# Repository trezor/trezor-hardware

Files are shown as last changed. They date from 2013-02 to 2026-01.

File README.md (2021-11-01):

# Hardware design of Trezor



https://trezor.io/

## Open Source Hardware

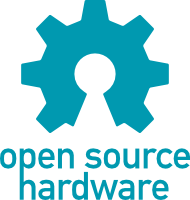
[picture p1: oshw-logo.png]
oshw (https://certification.oshwa.org/cz000005.html)


OSHWA UID: [CZ000005](https://certification.oshwa.org/cz000005.html)

The content of this repo is dual licensed under the following licenses:
* [GNU Affero General Public License v3](COPYING)
* [CERN Open Hardware Licence Version 2 - Strongly Reciprocal](LICENSE)

## Download

Download everything in a [single ZIP file](https://github.com/trezor/trezor-hardware/archive/master.zip).

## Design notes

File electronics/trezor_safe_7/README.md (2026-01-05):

# Trezor Safe 7 - Electronics Hardware
This folder contains both schematic designs and PCB renders of all the in-house developed PCBs present in the TS7 product. 

The TS7's electronics are split into three following PCBs
- Main board
- UI FPC
- ANT FPC

The display and battery also contain PCBs but these were not designed by Trezor's hardware team and therefore are not discloseable.

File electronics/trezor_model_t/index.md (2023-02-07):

# Trezor Model T Open Source Hardware Reference Documentation

## Photo

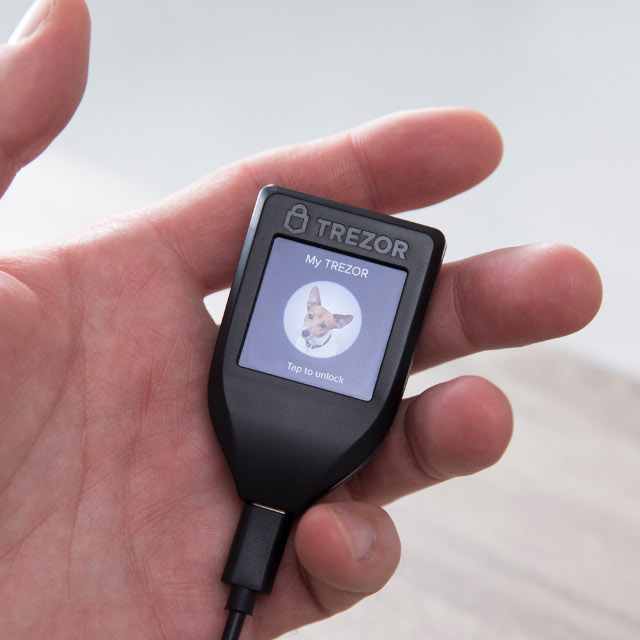
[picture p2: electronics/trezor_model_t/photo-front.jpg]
Photo Front


## Photo of assembled board (top)

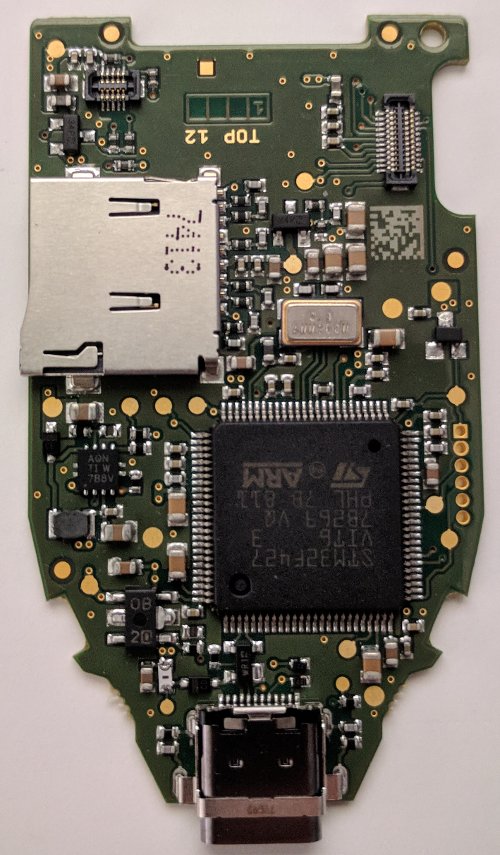
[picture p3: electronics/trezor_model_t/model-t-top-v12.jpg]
Assembled Board Top


## Photo of assembled board (bottom)

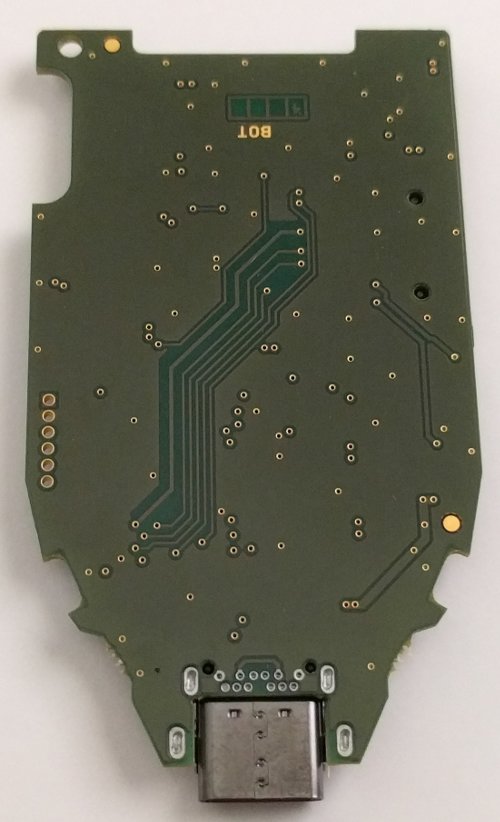
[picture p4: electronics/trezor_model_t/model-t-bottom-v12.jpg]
Assembled Board Bottom


## Photo of assembled TFT LCD display + capacitive touch panel module (top)

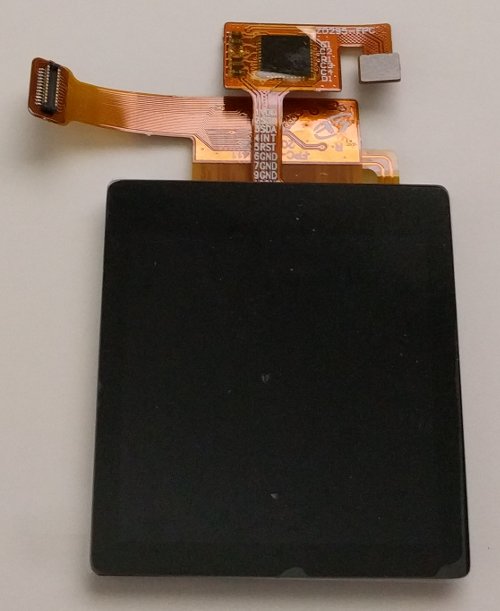
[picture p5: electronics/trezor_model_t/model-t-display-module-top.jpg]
Display Module Top


## Photo of assembled TFT LCD display + capacitive touch panel module (bottom)

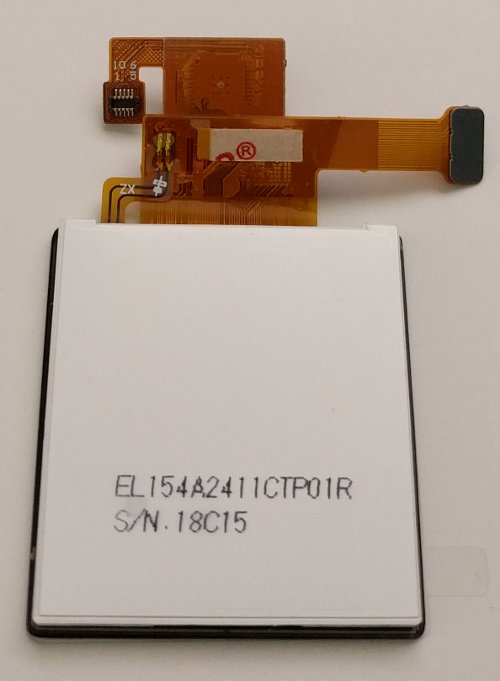
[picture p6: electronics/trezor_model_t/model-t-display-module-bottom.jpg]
Display Module Bottom


## Photo of disassembled TFT LCD display + capacitive touch panel module (top) (CTPM on left) (TFT LCD broken glass removed)

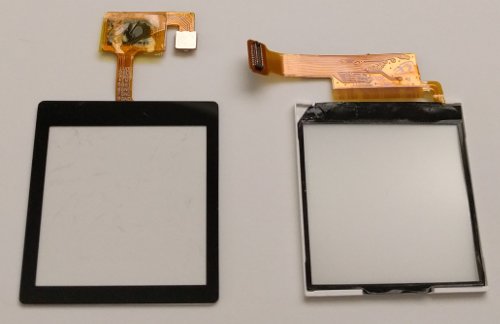
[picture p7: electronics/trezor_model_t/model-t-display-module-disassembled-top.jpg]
Display Module Disassembled Top


## Photo of disassembled TFT LCD display + capacitive touch panel module (bottom) (CTPM on left) (TFT LCD broken glass removed)

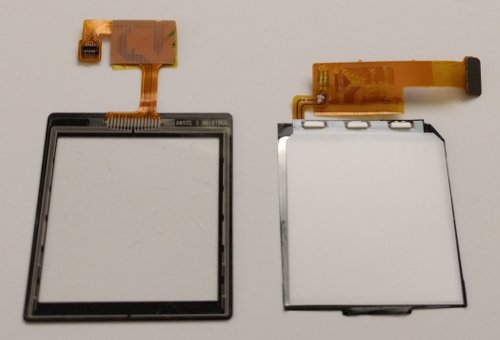
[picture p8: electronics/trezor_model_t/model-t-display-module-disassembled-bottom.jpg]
Display Module Disassembled Bottom


## Bill of Materials / BOM

[BOM](bom.txt)

## Schematic

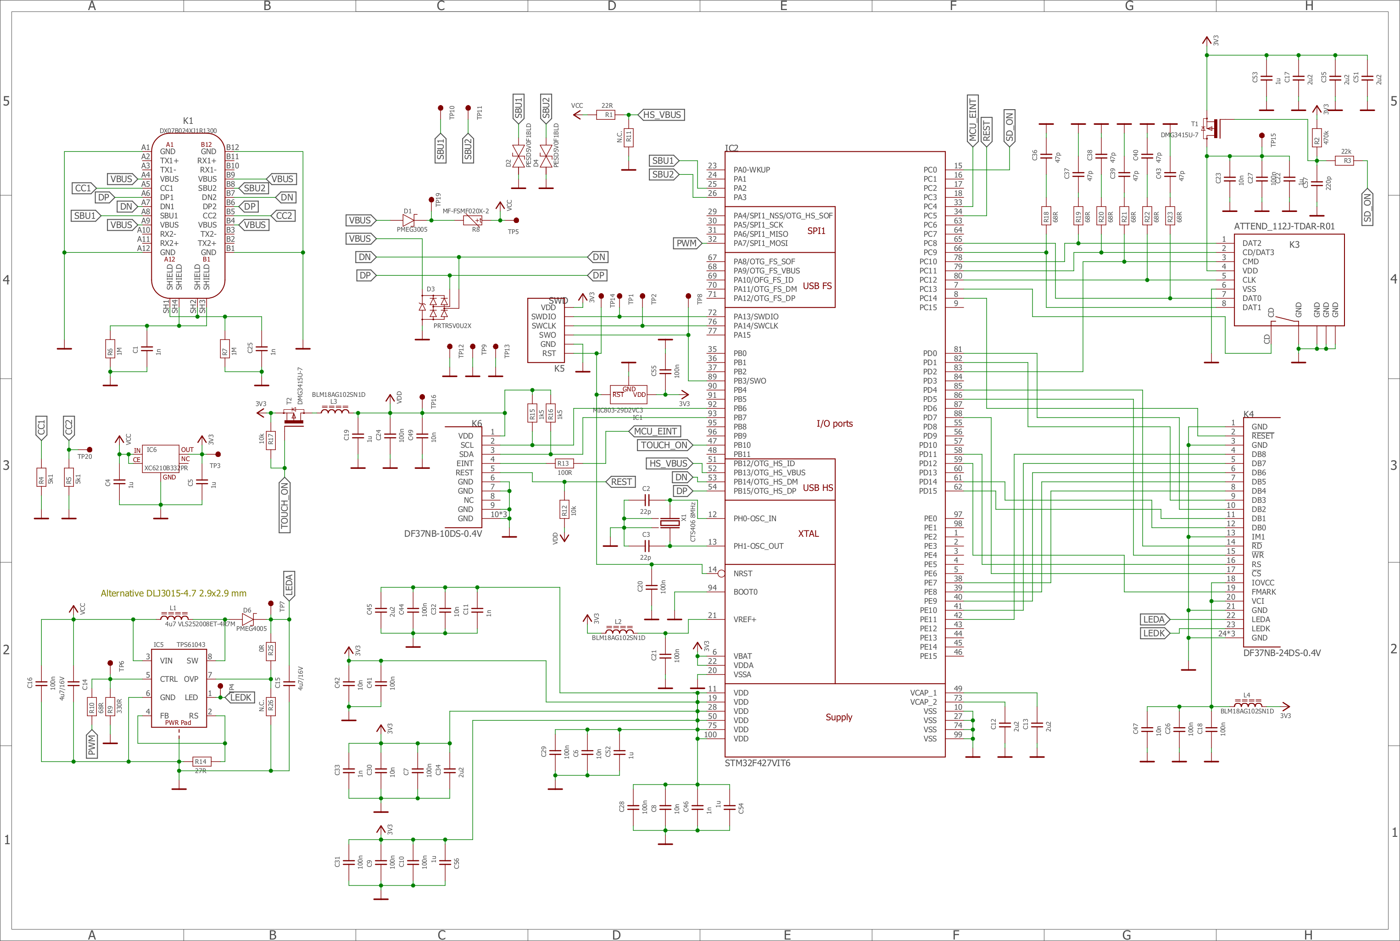
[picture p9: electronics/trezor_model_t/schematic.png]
Schematic


## Developer Kit

* 1 x [STM32F429I-DISC1](https://www.st.com/en/evaluation-tools/32f429idiscovery.html) (note: [Manual with pin to dev board function mapping](https://www.st.com/content/ccc/resource/technical/document/user_manual/6b/25/05/23/a9/45/4d/6a/DM00093903.pdf/files/DM00093903.pdf/jcr:content/translations/en.DM0009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))
* 1 x USB Cable Type A Plug/Male to Type Mini-B Plug/Male
* 1 x USB Cable Type A Plug/Male to Type Micro-B Plug/Male
* 1 x [ER-TFTM028-4 Display + Capacitive Touch Panel Module](https://www.ebay.com/itm/302049581340) (Note: specify 40-Pin Header, 8080 8-bit Parallel, VDD=3.3V, Capacitive Touch Panel) (note: [Manual](https://www.buydisplay.com/download/manual/ER-TFTM028-4_Datasheet.pdf))
* 1 x [microSD Board](https://www.waveshare.com/micro-sd-storage-board.htm)
* 1 x [Pack of 40 Female to female jumper wires with 0.1" header contacts](https://www.adafruit.com/product/266)

### Display

* Resolution: 240px x 240px -OR- 240px x 320px
* Driver IC: ST7789V, GC9307, or ILI9341V (on-chip display data RAM of 240x320x18 bits)
* 18-bit (262,144) RGB color graphic type TFT-LCD
* Bus/Interface: 8080-I 8-bit parallel with 16-bit/pixel (RGB 5-6-5)

#### Pinout

|Description|MCU Pin|Notes|
|---|---|-----|
|LCD_RST|PC14|display module pin 21. benign conflict with unpopulated OSC32_IN on dev board.|
|LCD_FMARK|PD12|tearing effect input; display module pin 22|
|LCD_PWM|PA7|backlight control (brightness); display module pin 29. benign conflict with I2C_EXT_RST on dev board.|
|LCD_CS|PD7|display module pin 23|
|LCD_RS|PD11|register select aka command/data; display module pin 24|
|LCD_RD|PD4|display module pin 26|
|LCD_WR|PD5|display module pin 25|
|LCD_D0|PD14|display module pin 3|
|LCD_D1|PD15|display module pin 4|
|LCD_D2|PD0|display module pin 5|
|LCD_D3|PD1|display module pin 6|
|LCD_D4|PE7|display module pin 7|
|LCD_D5|PE8|display module pin 8|
|LCD_D6|PE9|display module pin 9|
|LCD_D7|PE10|display module pin 10|
|LCD_D8|PE11|not currently used|

### Capacitive Touch Panel / Sensor

* Bus/Interface: I2C
* Driver IC: FT6236 or FT6206
* single touch

#### Pinout

|Description|MCU Pin|Notes|
|---|---|-----|
|TOUCH_ON|PB10|no mapped pin on display module|
|I2C1_SCL|PB6|display module pin 30|
|I2C1_SDA|PB7|display module pin 31|
|EINT|PC4|not currently used. display module pin 39. conflict with USB OTG FS PSO on dev board.|
|REST|PC5|benign conflict with USB OTG FS OC on dev board. no mapped pin on display module.|

### microSD Socket

* Bus/Interface: 4-bit

#### Pinout

|Description|MCU Pin|
|---|---|
|SDIO_D0|PC8|
|SDIO_D1|PC9|
|SDIO_D2|PC10|
|SDIO_D3|PC11|
|SDIO_CK|PC12|
|SDIO_CMD|PD2|
|SD_CARDDETECT|PC13|
|SD_ON|PC0|

### USB Socket

* USB HS (high-speed) peripheral in FS (full-speed) mode

#### Pinout

|Description|MCU Pin|Notes|
|---|---|-----|
|OTG_HS_VBUS|PB13||
|OTG_HS_ID|PB12||
|OTG_HS_DM|PB14||
|OTG_HS_DP|PB15||
|SBU1|PA2|not currently used. conflict with L3GD20 Gyroscope MEMS on dev board.|
|SBU2|PA3|not currently used|

### Dev Board

* [STM32F429ZIT6](https://www.st.com/en/microcontrollers-microprocessors/stm32f429zi.html)
* HSE / High-Speed External Crystal: 8 MHz
* Integrated STMicroelectronics ST-LINK/V2.1 debugger

Note: There are many conflicts between how the software maps GPIO pins and how the dev board maps them to its functions.
Many of the conflicts are resolved by removing the external SDRAM chip and the TFT LCD display + resistive touch panel that come attached to the dev board.
The unresolved conflicts are noted in the pinout descriptions above.
Currently, testing has shown that it is not necessary to remove either the SDRAM or the TFT LCD display + resistive touch panel.
If you choose to remove them, our experience is that the easiest way to remove the SDRAM chip is by first cutting the leads on one side of the chip (e.g.- with an X-Acto knife) and then lifting the chip and rocking it until the leads on the other side break. Be sure that no broken leads short to another pin as this can cause the dev board and/or display to malfunction. If some do, just clean them up so that they are separate again.
This method reduces the amount of knife work, and the chance for slicing other things on the board (or yourself).
To remove the TFT LCD display + resistive touch panel module, lift the module away from the metal tray, bend the metal tray out of the way, then cleanly pull/tear the flex PCB away from the solder connections to the main board (the connections usually break without much force).
The metal tray is attached to the board with double stick tape. You just have to pull that up.

## Photo of dev board before modifications (top)

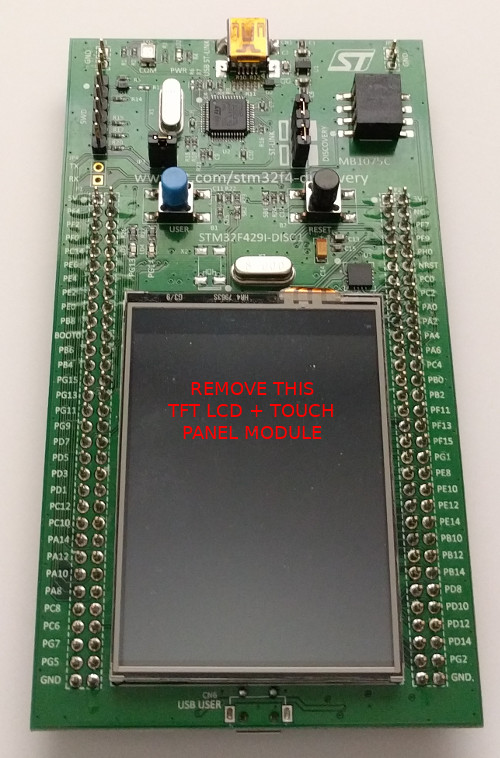
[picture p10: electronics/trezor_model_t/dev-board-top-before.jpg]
Dev Board Top Before


## Photo of dev board before modifications (bottom)

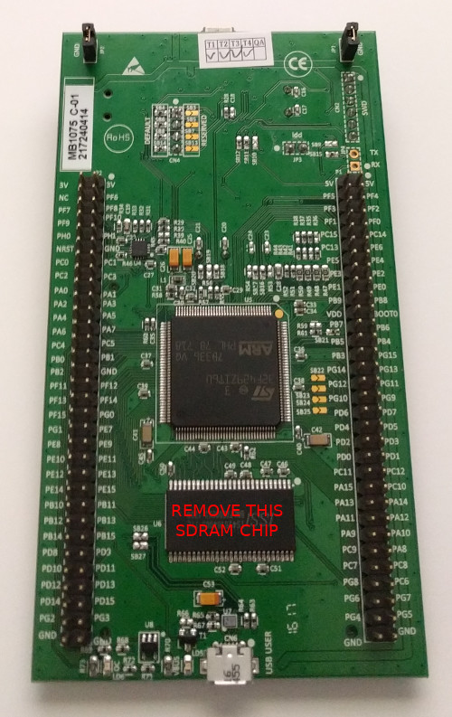
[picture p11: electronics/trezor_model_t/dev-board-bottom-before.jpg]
Dev Board Bottom Before


Minimum MCU requirements:

* STM32F4 family [STM32F427VIT6](https://www.st.com/en/microcontrollers-microprocessors/stm32f427vi.html)
* 168 MHz, 8 MHz HSE
* 2048 KB Flash memory
* 192 KB SRAM
* 64 KB CCMRAM
* FMC controller
* TRNG

### Clock Tree

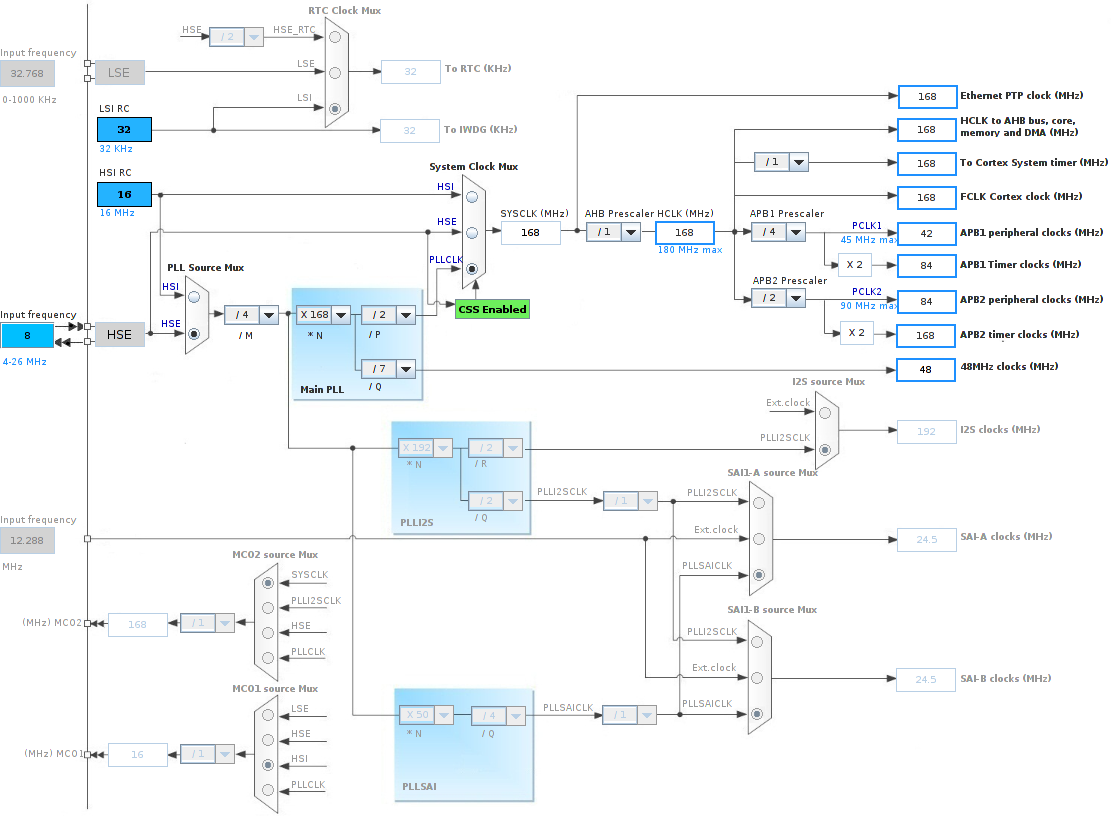
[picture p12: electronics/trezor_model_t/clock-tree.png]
Clock Tree


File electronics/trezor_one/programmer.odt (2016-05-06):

| 1 RST 2 GND 3 SWO 4 SWCLK 5 SWDIO 6 VDD

distance: 0.0625 inch

drill: 0.7 mm

programmer: ST-Link/V2

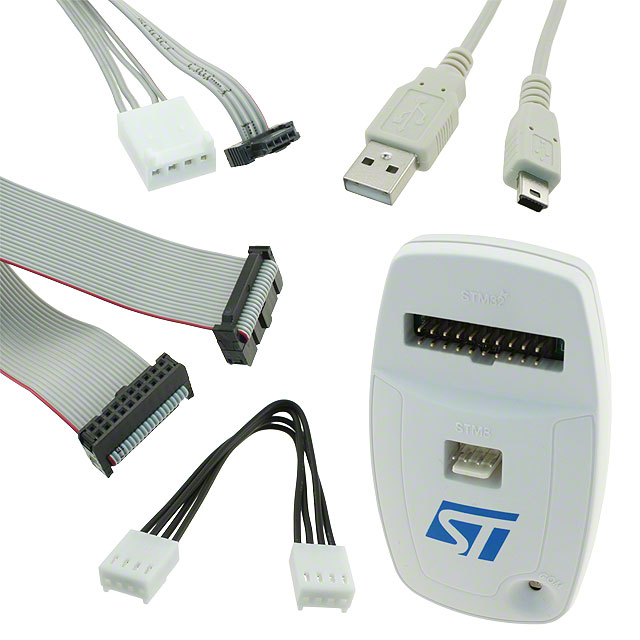
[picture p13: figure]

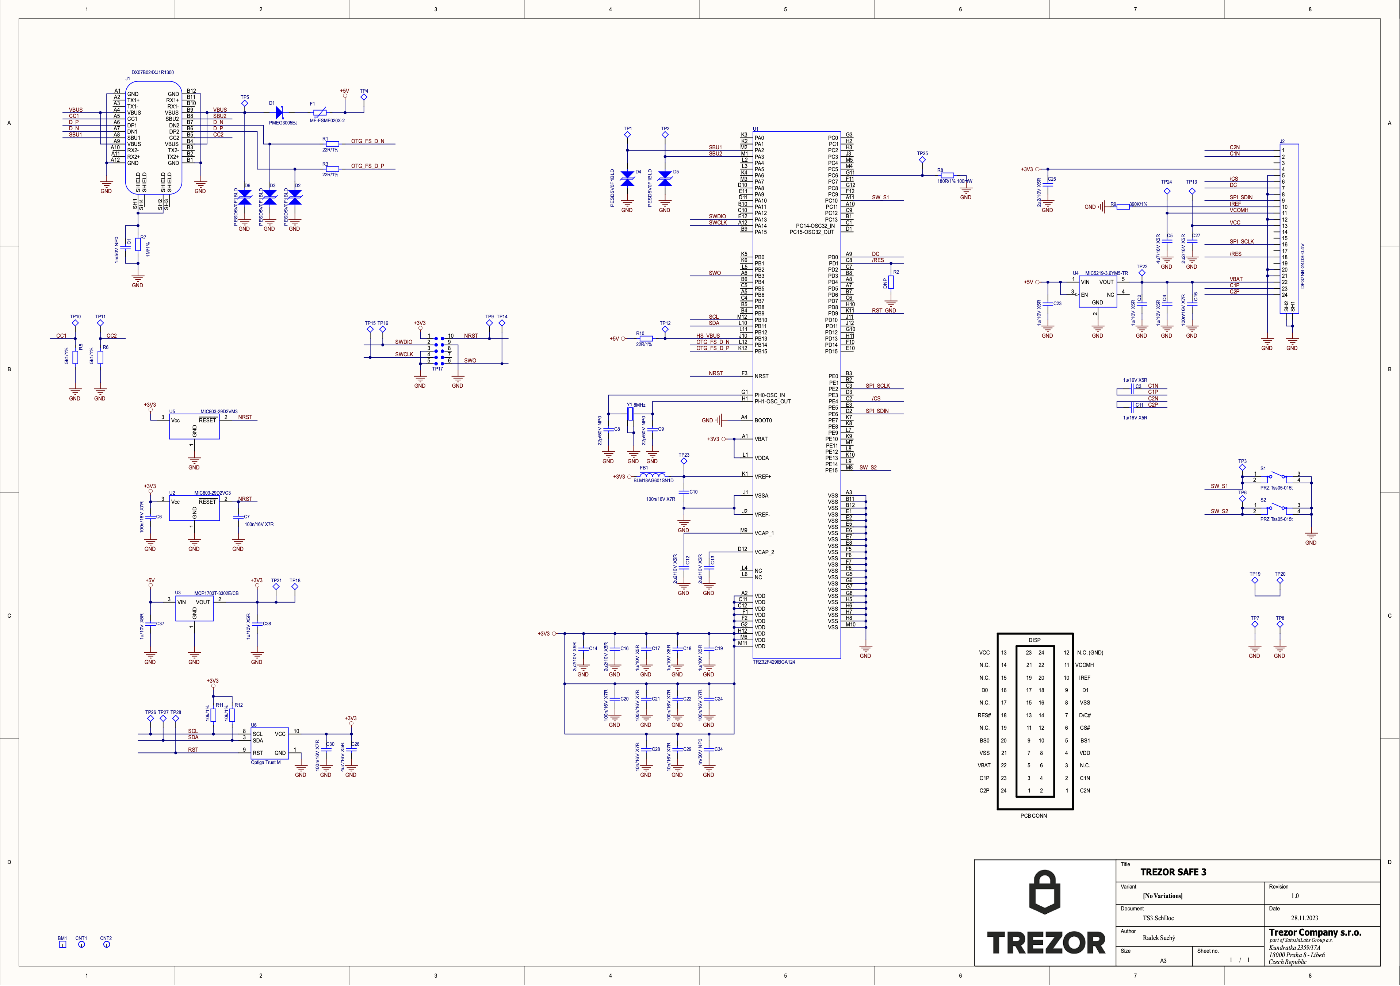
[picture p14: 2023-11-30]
electronics/trezor_safe_3/schematics.png

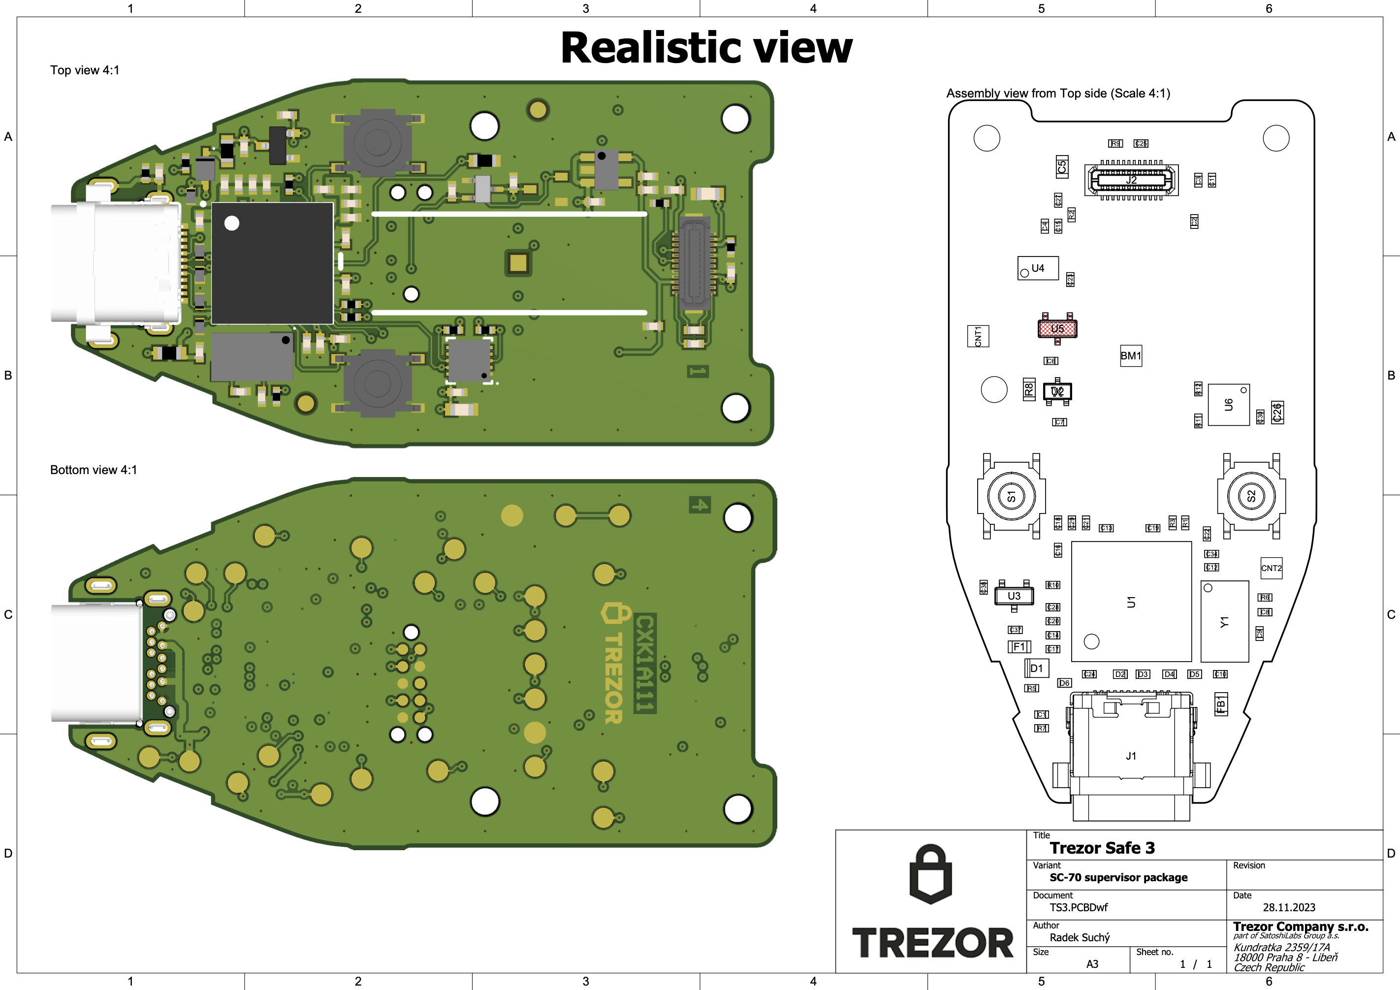
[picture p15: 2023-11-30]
electronics/trezor_safe_3/pcb_view.png

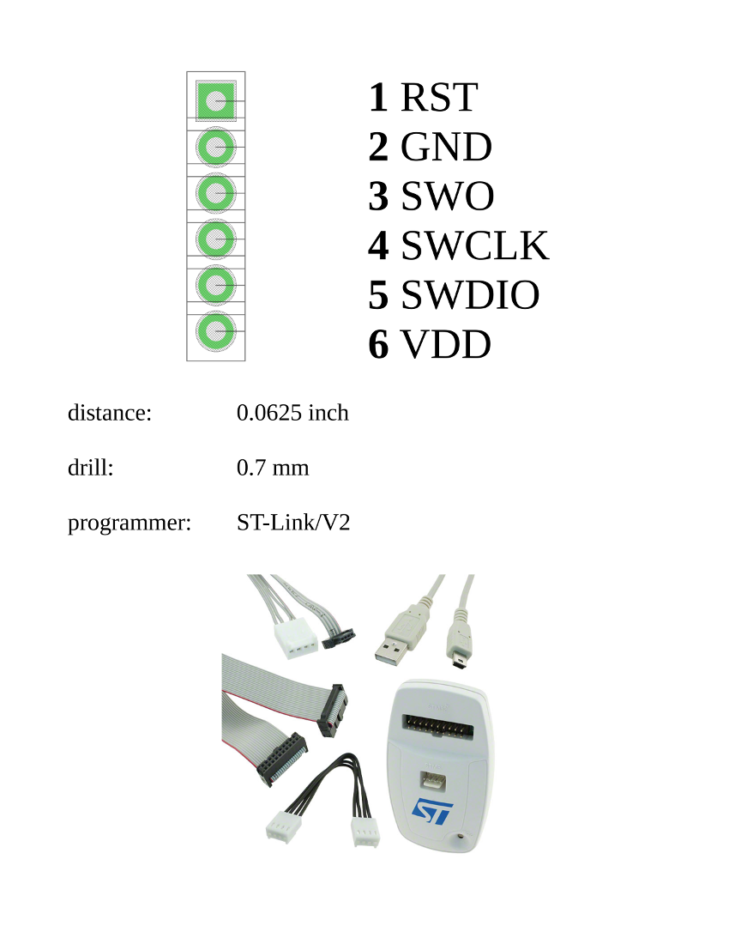
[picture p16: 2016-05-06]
electronics/trezor_one/programmer.png

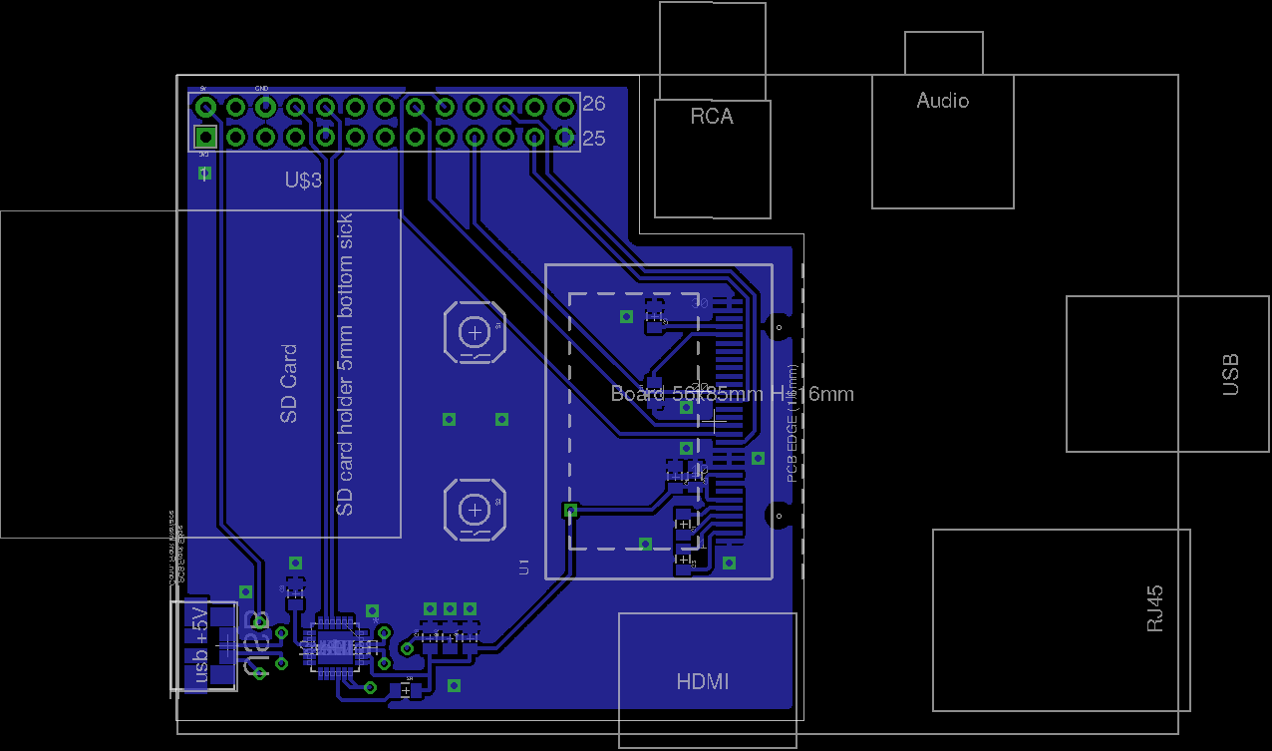
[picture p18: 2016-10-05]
electronics/trezor_one/raspi.brd.png

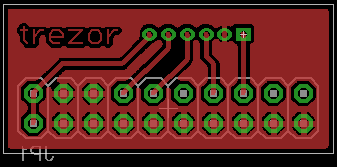
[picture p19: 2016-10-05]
electronics/trezor_one/programmer.brd.png

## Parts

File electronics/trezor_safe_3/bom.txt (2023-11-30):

Quantity    Designator                                  Comment                Footprint
2           C1, C34                                     1n/50V NP0             C_0402_B
8           C2, C4, C17, C18, C19, C23, C37, C38        1u/10V X5R             C_0402_B
2           C3, C11                                     1u/16V X5R             C_0402_B
2           C5, C26                                     4u7/16V X5R            C_0603_B
9           C6, C7, C10, C15, C20, C21, C22, C24, C30   100n/16V X7R           C_0402_B
2           C8, C9                                      22p/50V NP0            C_0402_B
5           C12, C13, C14, C16, C25                     2u2/10V X5R            C_0402_B
1           C27                                         2u2/16V X5R            C_0402_B
2           C28, C29                                    10n/16V X7R            C_0402_B
1           D1                                          PMEG3005EJ             SOD-323_B
5           D2, D3, D4, D5, D6                          PESD5V0F1BLD           SOD-882D_B
1           F1                                          MF-FSMF020X-2          R_0603_B
1           FB1                                         BLM18AG601SN1D         L_0603_B
1           J1                                          DX07B024XJ1R1300       USB-C_3.1_JAE_DX07B024XJ1
1           J2                                          DF37NB-24DS-0.4V       DF37NB-24DS-0.4V
3           R1, R3, R10                                 22R/1%                 R_0402_B
1           R2                                          DNP                    R_0402_B
2           R5, R6                                      5k1/1%                 R_0402_B
1           R7                                          1M/1%                  R_0402_B
1           R8                                          180R/1% 100mW          R_0603_B
1           R9                                          390K/1%                R_0402_B
2           R11, R12                                    10k/1%                 R_0402_B
2           S1, S2                                      PRZ Tss05-015t         Tact_Switch_5.2x5.2x1.5_B
1           U1                                          TRZ32F429IBGA124       BGA-124_9X9
1           U2                                          MIC803-29D2VC3         SC-70-3_B
1           U3                                          MCP1703T-3302E/CB      SOT-23-3_B
1           U4                                          MIC5219-3.6YM5-TR      SOT-23-5_B
1           U6                                          Optiga Trust M         PG-USON-10-2_B
1           Y1                                          8MHz                   X-4_6.0x3.5_B

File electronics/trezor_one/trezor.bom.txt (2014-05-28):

Trezor
======

- 5x SMD 0603 Capacitor 1uF - C1, C2, C4, C10, C11
- 7x SMD 0603 Capacitor 0.1uF - C3, C12, C13, C14, C15, C16, C18
- 3x SMD 0603 Capacitor 2.2uF - C6, C7, C17
- 1x SMD 0603 Capacitor 4.7uF - C5
- 2x SMD 0603 Capacitor 22pF - C8, C9

- 1x SMD 0603 Resistor 390k - R1

- 2x Microbuton P-B17310
  * http://www.gme.cz/mikrospinace-do-dps/p-b17310-p630-143/

- 1x Micro USB (type B) Receptacle Bottom
  * http://cz.farnell.com/molex/47346-0001/micro-usb-type-b-receptacle-bottom/dp/1568026

- 1x OLED display 128x64 UG-2864HSWEG01
  * http://www.wide.hk/products.php?product=128X64-OLED-LED-Display-Module-SSD1306-%28White-Color%29

- 1x STM32F205RE
  * http://www.st.com/web/catalog/mmc/FM141/SC1169/SS1575/LN1433/PF245096
  * http://cz.farnell.com/stmicroelectronics/stm32f205ret6/ic-mcu-32bit-arm-64-lqfp/dp/2060897

- 1x MCP1703 Low Dropout Voltage Regulator
  * http://www.microchip.com/wwwproducts/Devices.aspx?dDocName=en530838
  * http://cz.farnell.com/microchip/mcp1703t-3302e-cb/v-reg-ldo-250ma-3-3v-sot-23a-3/dp/1439518

- 1x ABMM2 8 MHz Crystal
  * http://cz.farnell.com/abracon/abmm2-8-000mhz-e2-t/crystal-8m-18pf-cl-6x3-6mm-smt/dp/1611803

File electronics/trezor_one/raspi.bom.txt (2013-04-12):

Raspberry Pi shield
===================

- 5x SMD 0805 Capacitor 1uF - C1, C2, C4, C6, C7
- 2x SMD 0805 Capacitor 0.1uF - C3, C8
- 1x SMD 0805 Capacitor 2.2uF - C5
- 1x SMD 0805 Capacitor 4.7uF - C9

- 1x SMD 0805 Resistor 390k - R1
- 1x SMD 0805 Resistor 4k7 - R2

- 2x Microbuton P-B17310
  * http://www.gme.cz/mikrospinace-do-dps/p-b17310-p630-143/

- 1x Micro USB (type B) Receptacle Bottom
  * http://cz.farnell.com/molex/47346-0001/micro-usb-type-b-receptacle-bottom/dp/1568026

- 1x OLED display 128x64 UG-2864HSWEG01
  * http://www.wide.hk/products.php?product=128X64-OLED-LED-Display-Module-SSD1306-%28White-Color%29

- 1x SiLabs CP2110 HID-232 converter
  * http://www.silabs.com/products/interface/usbtouart/Pages/usb-to-uart-bridge.aspx

- 1x 2x13 Pinheader
  * http://www.gme.cz/dutinkove-listy/dutinkova-lista-bl826gd-p832-240/

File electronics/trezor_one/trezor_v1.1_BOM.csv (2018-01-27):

Qty | Value | Device | Package | Parts | Description
7 | 100n | C_0402 | 402 | C7, C9, C12, C13, C14, C15, C16
1 | 12k | R_0402 | 402 | R7
1 | 1M | R_0603 | 603 | R9
1 | 1k5 | R_0402 | 402 | R6
1 | 1n/200V | C_0603 | 603 | C19
5 | 1u | C_0402 | 402 | C1, C2, C3, C4, C18
2 | 22R | R_0402 | 402 | R3, R4
1 | 22k | R_0402 | 402 | R8
2 | 22p | C_0402 | 402 | C20, C21
2 | 2u2 | C_0402 | 402 | C6, C8
1 | 2u2 | C_0603 | 603 | C5
1 | 390k | R_0402 | 402 | R10
1 | 4u7 | C_0603 | 603 | C10
1 | 8MHz | CRYSTALCTS406 | CTS406 | Q2 | CRYSTAL
1 | BAT60BWS | DS_SOD323 | SOD323 | D2
1 | DISPLAY | DISP_OLED_UG-2864HSWEG010.96";UG-2864HSWEG01_0.96IN_WRAPAROUND" | U3 | UG-2864HSWEG01 OLED display
1 | MCP1703T-3302E/CB | MCP1703CB | SOT23 | IC1 | 250 mA, 16V, Low Quiescent Current LDO Regulator
1 | MF-FSMF020X-2 | POLYSWITCH_0603 | 603 | R2
1 | PRTR5V0U2X | PRTR5V0_SOT143B | SOT143B | D1
1 | STM32F205RET6 | STM32F10XRXT6 | TQFP64 | U1 | STM32F101/103 64pin LQFP
1 | SWD | SWD | SWD | K2 | SWD
2 | SWITCH-MOMENTARY-2SMD | SWITCH-MOMENTARY-2SMD | TACTILE_SWITCH_SMD | S1, S2 | Various NO switches- pushbuttons, reed, etc
1 | USB5_USB_MICRO_MOLEX475890001 | USB5_USB_MICRO_MOLEX475890001 | USB_MICRO-MOLEX475890001 | K1

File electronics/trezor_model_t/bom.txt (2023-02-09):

Part Value                Device                                  Package
C1   1n/50V               C_0402                                  0402
C2   22p                  C_0402                                  0402
C3   22p                  C_0402                                  0402
C4   1u                   C_0603                                  0603
C5   1u                   C_0603                                  0603
C6   10n                  C_0402                                  0402
C7   100n                 C_0402                                  0402
C8   10n                  C_0402                                  0402
C9   100n                 C_0402                                  0402
C10  100n                 C_0402                                  0402
C11  1n                   C_0402                                  0402
C12  2u2                  C_0805                                  0805
C13  2u2                  C_0805                                  0805
C14  4u7/16V              C_0805                                  0805
C15  4u7/16V              C_0805                                  0805
C16  100n                 C_0402                                  0402
C17  2u2                  C_0805                                  0805
C18  100n                 C_0402                                  0402
C19  1u                   C_0603                                  0603
C20  100n                 C_0402                                  0402
C21  100n                 C_0402                                  0402
C22  1u                   C_0603                                  0603
C23  10n                  C_0402                                  0402
C24  100n                 C_0402                                  0402
C25  1n/50V               C_0402                                  0402
C26  100n                 C_0402                                  0402
C27  100n                 C_0402                                  0402
C28  100n                 C_0402                                  0402
C29  100n                 C_0402                                  0402
C30  10n                  C_0402                                  0402
C31  100n                 C_0402                                  0402
C32  10n                  C_0402                                  0402
C33  1n                   C_0402                                  0402
C34  2u2                  C_0805                                  0805
C35  2u2                  C_0805                                  0805
C36  47p                  C_0402                                  0402
C37  47p                  C_0402                                  0402
C38  47p                  C_0402                                  0402
C39  47p                  C_0402                                  0402
C40  47p                  C_0402                                  0402
C41  100n                 C_0402                                  0402
C42  10n                  C_0402                                  0402
C43  47p                  C_0402                                  0402
C44  100n                 C_0402                                  0402
C45  2u2                  C_0805                                  0805
C46  1n                   C_0402                                  0402
C47  10n                  C_0402                                  0402
C48  100n                 C_0402                                  0402
C49  10n                  C_0402                                  0402
C50  220p                 C_0402                                  0402
C51  2u2                  C_0805                                  0805
C52  1u                   C_0603                                  0603
C53  1u                   C_0603                                  0603
C54  1u                   C_0603                                  0603
C55  100n                 C_0402                                  0402
C56  1u                   C_0603                                  0603
C57  220p                 C_0402                                  0402
C58  1n                   C_0402                                  0402
D1   PMEG3005EJ           DS_SOD323F                              SOD323F
D2   PESD5V0F1BLD         D_TRANSIL_BI_SOD882D                    SOD882D
D3   PRTR5V0U2X           PRTR5V0_SOT143B                         SOT143B
D4   PESD5V0F1BLD         D_TRANSIL_BI_SOD882D                    SOD882D
D6   PMEG4005EJ           DS_SOD323F                              SOD323F
IC1  MIC803-30D2VC3                                               SC70-3
IC2  STM32F427VIT6        STM32F427_LQFP100                       LQFP100_NO_CENTER_NO_TDOCU
IC5  TPS61043             TP6104X_WSON-8_3X3MM                    WSON-8_3X3MM
IC6  XC6210B332PR         XC6210B_SOT89-5                         SOT89-5
K1   DX07B024XJ1R1300     USB-C_JAE_DX07B024XJ1                   USB_C_JAE_DX07B024XJ1
K3   ATTEND_112J-TDAR-R01 KON_µSD_CARD_ATTEND_112J_TXAR_R01_SMALL ATTEND_112J-TXAR-R01_SMALL
K4   DF37NB-24DS-0.4V     DISPLEJ_154A2411CTP01                   DF37NB-24DS-0.4V
K5   SWD                  SWD                                     SWD
K6   DF37NB-10DS-0.4V     DISPLEJ_154A2411CTP01_TOUCH             DF37NB-10DS-0.4V
L1   4u7 VLS252008ET-4R7M L_2.5X2.0                               L_2.5X2.0
L2   BLM18AG601SN1D       L_0603                                  0603
L3   BLM18AG601SN1D       L_0603                                  0603
L4   BLM18AG601SN1D       L_0603                                  0603
LCD1                      LCD_DISPLEJ                             LCD
R1   22R                  R_0402                                  0402
R2   470k                 R_0402                                  0402
R3   22k                  R_0402                                  0402
R4   5k1                  R_0402                                  0402
R5   5k1                  R_0402                                  0402
R6   1M                   R_0402                                  0402
R7   1M                   R_0402                                  0402
R8   MF-FSMF020X-2        POLYSWITCH_0603                         0603
R9   330R                 R_0402                                  0402
R10  68R                  R_0402                                  0402
R11  N.C.                 R_0402                                  0402
R12  10k                  R_0402                                  0402
R13  100R                 R_0402                                  0402
R14  27R                  R_0402                                  0402
R15  1k5                  R_0402                                  0402
R16  1k5                  R_0402                                  0402
R17  470k                 R_0402                                  0402
R18  68R                  R_0402                                  0402
R19  68R                  R_0402                                  0402
R20  68R                  R_0402                                  0402
R21  68R                  R_0402                                  0402
R22  68R                  R_0402                                  0402
R23  68R                  R_0402                                  0402
R24  22k                  R_0402                                  0402
R25  0R                   R_0402                                  0402
R26  N.C.                 R_0402                                  0402
T1   DMP2045U                                                     SOT-23
T2   DMP2045U                                                     SOT-23
X1   CTS406 8MHz          X_4V_6,0X3,5                            X6,0X3,5

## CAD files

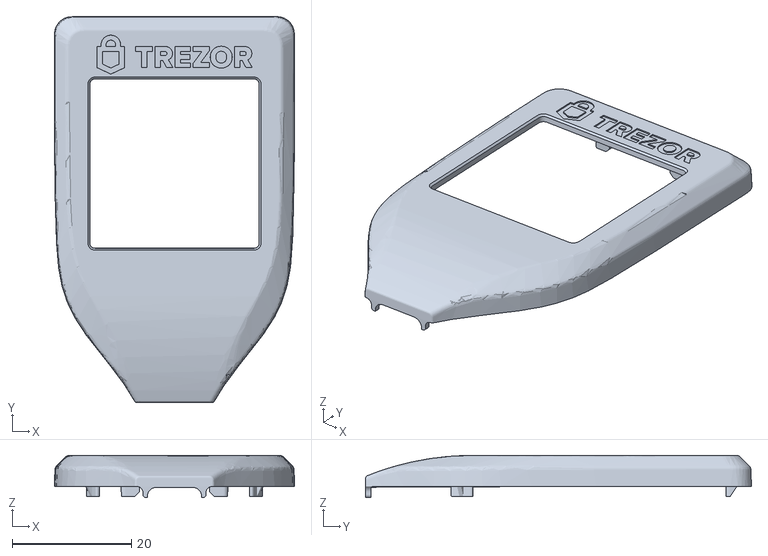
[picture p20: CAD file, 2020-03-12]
case/trezor_model_t/v1/top.stl
40.2 x 64.6 x 7.05

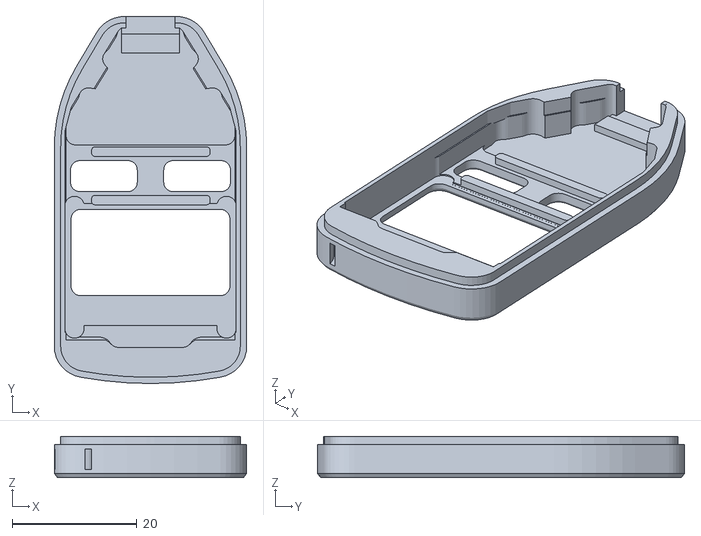
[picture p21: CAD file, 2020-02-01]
case/trezor_one/v3/cover-up.stl
30.9 x 58.9 x 6.61

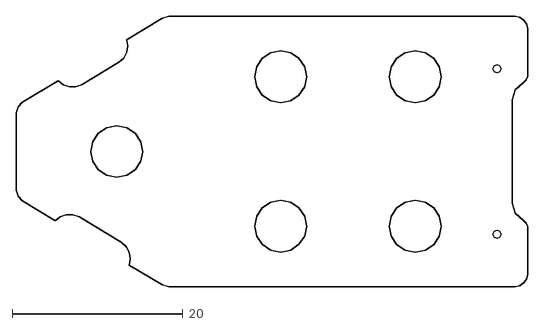
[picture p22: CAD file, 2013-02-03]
stl/plosak-nobezier.dxf
59.9 x 31.6

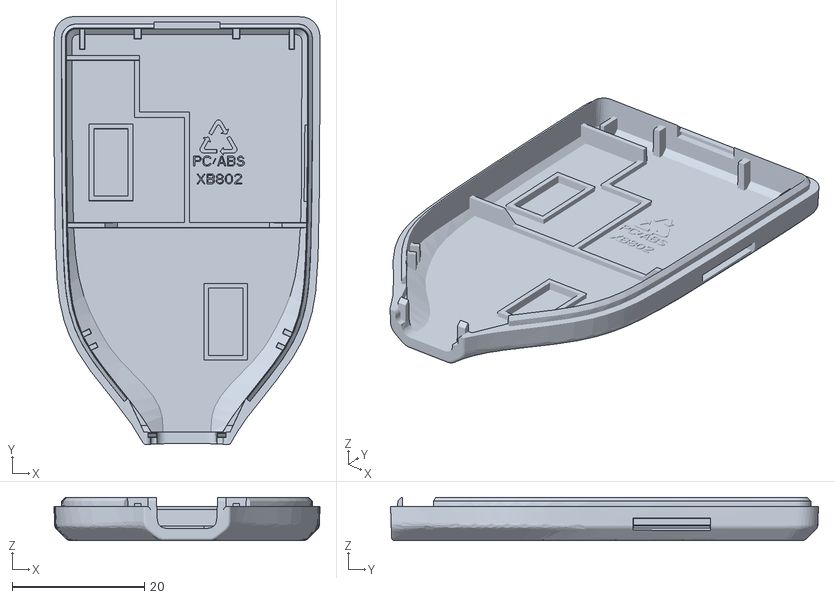
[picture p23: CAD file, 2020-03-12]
case/trezor_model_t/v1/bottom.stl
40.2 x 64.7 x 6.55

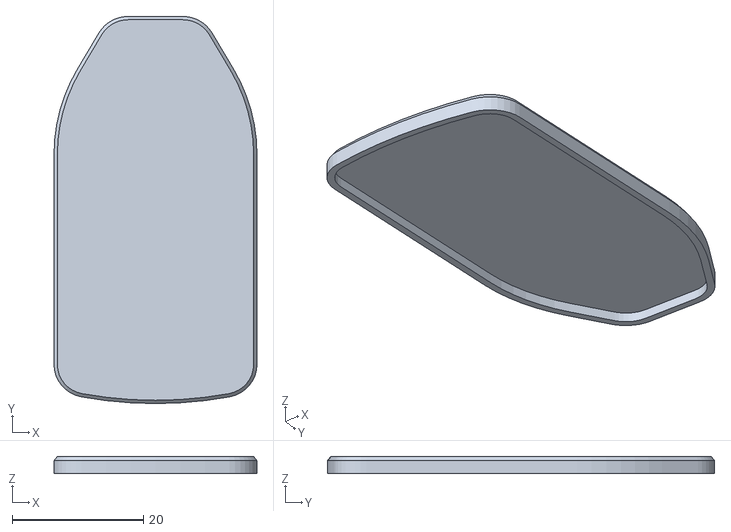
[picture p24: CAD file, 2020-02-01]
case/trezor_one/v3/cover-down.stl
30.9 x 58.9 x 2.64

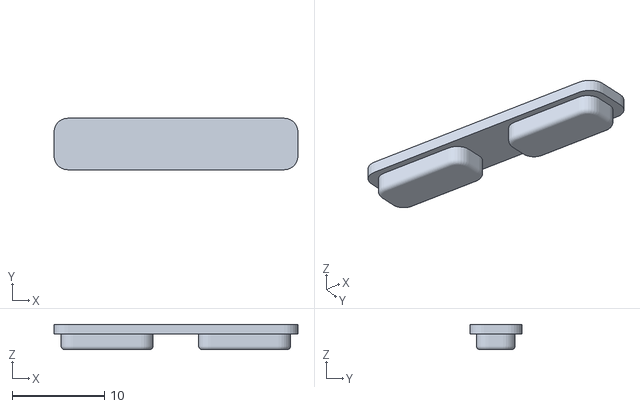
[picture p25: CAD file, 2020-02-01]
case/trezor_one/v3/buttons.stl
26.5 x 5.60 x 2.76

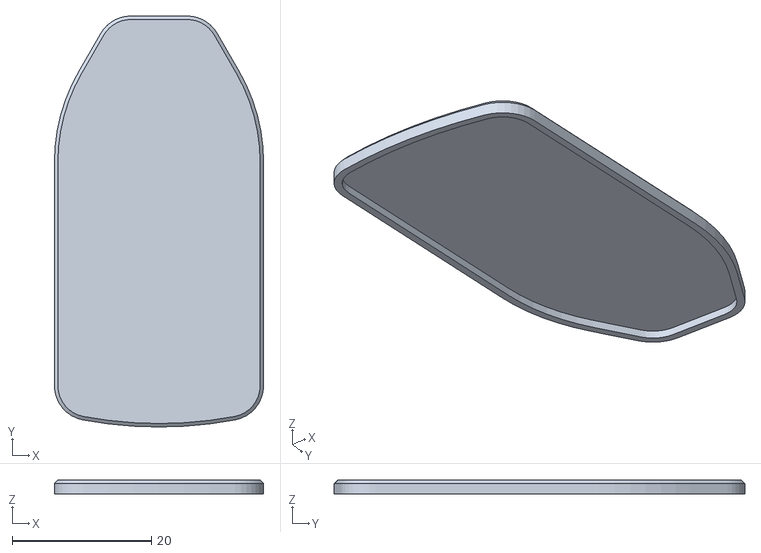
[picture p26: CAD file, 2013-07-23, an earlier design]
case/trezor_one/v1/cover-down.stl
30.0 x 58.9 x 2.00

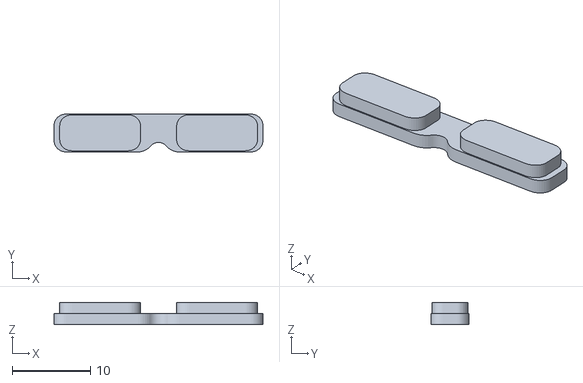
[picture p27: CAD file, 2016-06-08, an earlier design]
case/trezor_one/v2/buttons.stl
26.8 x 4.85 x 2.82

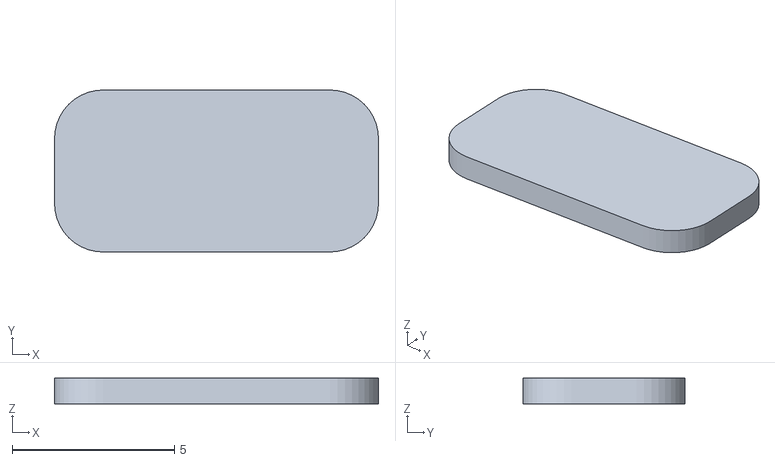
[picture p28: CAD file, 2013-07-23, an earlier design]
case/trezor_one/v1/button-up-2.stl
10.0 x 5.00 x 0.8

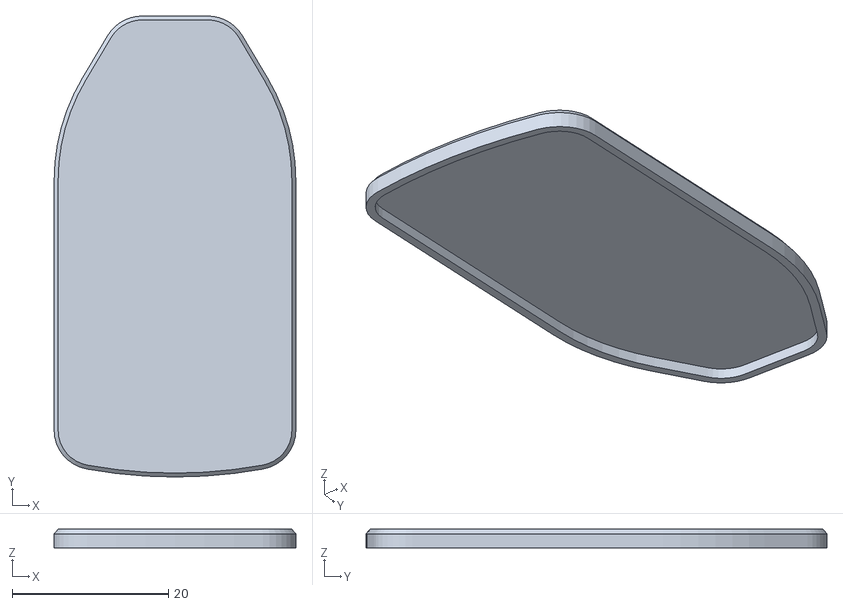
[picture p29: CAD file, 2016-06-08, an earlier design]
case/trezor_one/v2/cover-down-3.stl
30.9 x 58.9 x 2.40

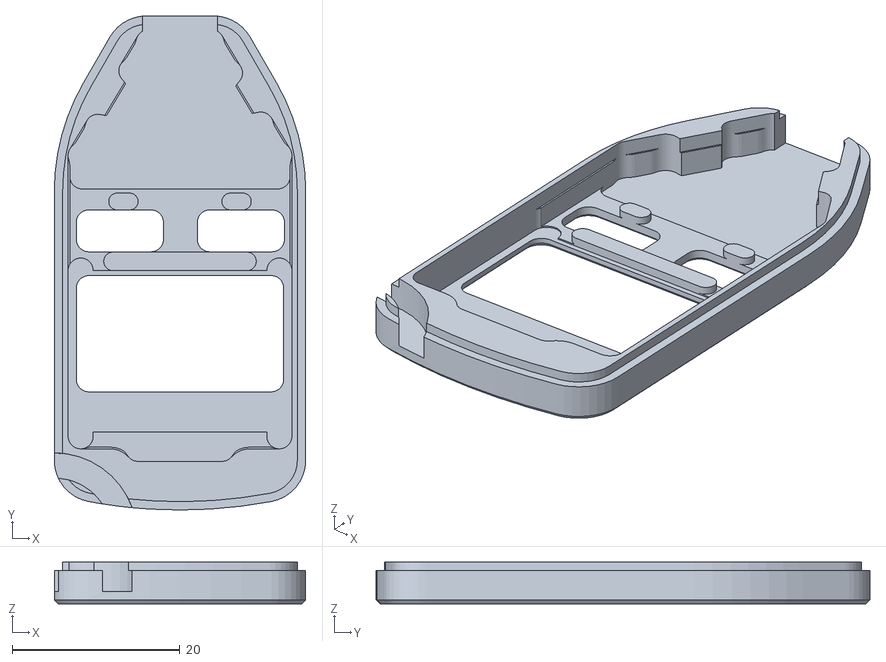
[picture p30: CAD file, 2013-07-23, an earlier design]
case/trezor_one/v1/cover-up.stl
30.0 x 58.9 x 5.00

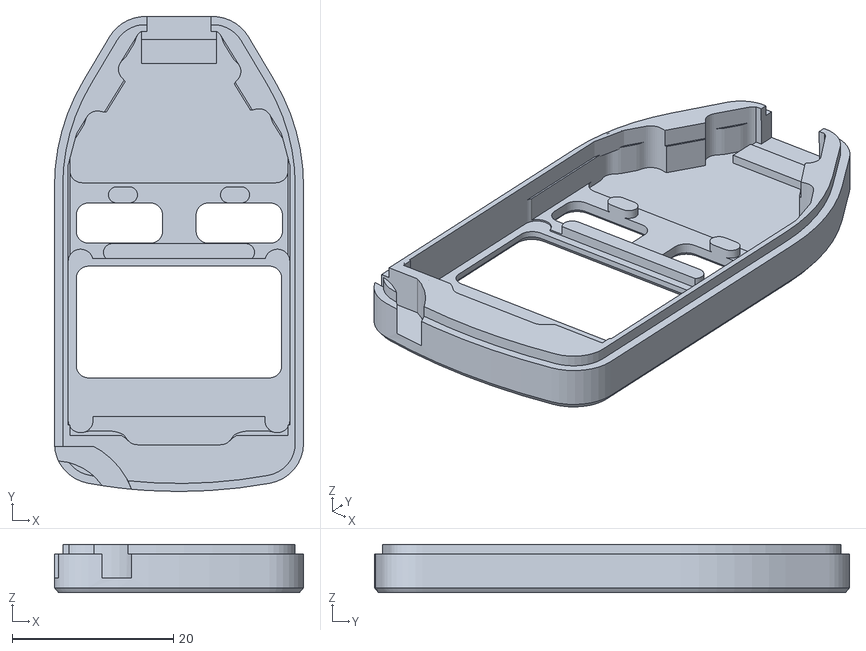
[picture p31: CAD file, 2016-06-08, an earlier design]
case/trezor_one/v2/cover-up-3.stl
30.9 x 58.9 x 6.01

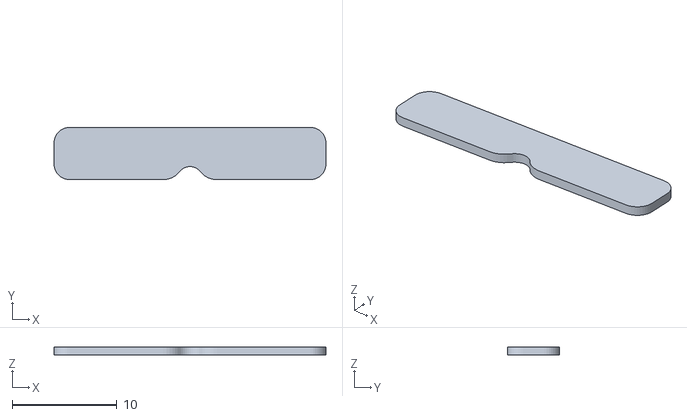
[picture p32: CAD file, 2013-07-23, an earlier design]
case/trezor_one/v1/button-down.stl
26.0 x 5.00 x 0.8

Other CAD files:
case/trezor_one/v1/button-up-1.stl

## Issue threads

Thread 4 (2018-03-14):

V1.1 schematic R6, R8 do not populate parts.

voltlog, 2018-03-14:
Although the schematic shows R6 and R8 these are do not populate parts as it can be seen in the picture of the production board. These should be marked accordingly in the schematic because if you populate these, trezor will only work in bootloader mode and it fill fail to initialize the USB interface in normal mode.

juttTechnology, 2018-06-26:
do you have trezor model T hardware files..? if this is open source then should be here. i also try to design for myself.

prusnak, 2018-06-26:
@juttTechnology https://github.com/trezor/trezor-core/blob/master/docs/hardware.md

juttTechnology, 2018-06-26:
thank you for your reply. this is document but can you also share the .sch and .brd file. or is it private ?

prusnak, 2018-06-26:
@juttTechnology what you see is what you get - i deleted older comments, because you are discussing totally unrelated stuff to the original issue

vladT0, 2018-08-13:
I can confirm, removing those 2 resistors will make USB available. With R6 and R8 for me PC has no connect to Trezor.

vladT0, 2018-08-13:
But actually I don't know about R8, if you remove it, you will get 5V on PA9, what is not good. May be make sense to return R8 back.

vladT0, 2018-08-13:
According your proposal I removed 2 resistors from the pcb and I can confirm, it makes USB available. With R6 and R8 for me PC had no connect to Trezor. But actually I don't know about R8, if you remove it, you will get 5V on PA9, what is not good. May be make sense to return R8 back. I return it back and I still have connect to PC with Trezor and seems wallet is working properly. I forget to say, in my case instead of STM32F205RET6, I am using STM32F405RGT6 and 16MHZ quartz with minor modifications in bootloader and firmware.

vladT0, 2018-08-14:
Resistor R6 1.5 kOhm is designed seems to provide STM32F102 functionality, which requires connection of an external resistor between D+ and VDD. Your microcontroller will likely not require such external component, having ‘on board’ everything what you need.

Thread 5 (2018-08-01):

External oscillator

Isawwad, 2018-08-01:
### You are using external oscillator because The USB OTG full-speed controller requires a dedicated 48 MHz clock that is generated by a PLL connected to the HSE oscillator.

is there any need or advantages from using external oscillator rather than internal one in stm32F20xx or its just the USB??

prusnak, 2018-08-01:
Just the USB

Isawwad, 2018-08-05:
thank you sir

Closed 2018-08-01.

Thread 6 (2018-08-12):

3D case

juttTechnology, 2018-08-12:
any one have updated 3D model files for Version 1.1
i already print the current files but have two issues.
1. button are very tight inside the case
2. back cover is not fitting because it looks small.

thank you

prusnak, 2018-08-12:
Use the files from https://github.com/trezor/trezor-hw/tree/master/case/3dPrint

Several people have successfully used these. If it still doesn't work, try to fiddle with your printer's settings.

Closed 2018-08-12.

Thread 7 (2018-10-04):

3D files for Model T case?

jonathancross, 2018-10-04:
Hi, where might I find 3D files for the Model T case?
I'd like to replace the plastic case with one [made of metal](https://www.sculpteo.com/en/materials/metals/dmls-stainless-steel-material/) -- is this at all feasible without breaking the electronics?

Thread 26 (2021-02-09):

Trezor T BOM and schematic mismatch

micmys, 2021-02-09:
I noticed there are differences in the BOM for Trezor model T:
https://github.com/trezor/trezor-hardware/blob/master/electronics/trezor_model_t/bom.txt
and its schematic:
https://github.com/trezor/trezor-hardware/blob/master/electronics/trezor_model_t/schematic.png

For example:
- transistors T1/T2 with their accompanying components are absent in the BOM
- IC1 is also nowhere to be found
- resistors R9, R10 have different values in both documents
- (probably some more discrepancies)

I assume that the schematic is newer & correct and BOM should be adjusted, but this probably needs clarification.

prusnak, 2023-02-09:
BOM updated in https://github.com/trezor/trezor-hardware/commit/5e020e14b6635fb0b783444121c7a3eb60352929

Closed 2023-02-09.

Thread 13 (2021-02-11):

Provide BOM and Gerbers for Model T

nhorvath, 2021-02-11:
Can you please provide similar resources for the model t as you have for the one? Thanks!

diimdeep, 2021-02-11:
Mentioned here https://www.youtube.com/watch?v=ggeCYry3gTw

specs32, 2021-02-12:
> Can you please provide similar resources for the model t as you have for the one? Thanks!

BOM is here https://github.com/trezor/trezor-firmware/blob/master/docs/hardware/model-t/index.md

prusnak, 2021-02-12:
I just copied the `bom.txt` and other files from the trezor-firmware repo to this repo.

We don't provide the Gerber files at the moment, only Eagle files - so it should be trivial to generate the Gerbers, but I'll have a look at this later.

nhorvath, 2021-02-12:
The free version of eagle only supports 2 layers.

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

prusnak, 2021-02-13:
I added the KiCad files (Eagle imports) to the Repo:

https://github.com/trezor/trezor-hardware/tree/master/electronics/trezor_model_t/kicad
and
https://github.com/trezor/trezor-hardware/tree/master/electronics/trezor_one/kicad

Feel free to send improvements to these.

I am not going to add Gerber files, because it should be trivial to export these from KiCad.

Closed 2021-02-13.

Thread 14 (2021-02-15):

K1 footprint : Edge.Cuts Layer stray segments prevent Kicad 3D viewer from determining board outline

transistortherapy, 2021-02-15:
The edge cut layers of K1 are preventing the 3D viewer from loading properly.

The slots/oval holes for SH1-4 are currently in the edge cuts layer. They need to be migrated from the edge cuts layer to the through hole pad parameters. The final result may be the same, depending on the fab.

However if you edit parameters of the through hole pads mentioned - in the top right hand corner of the pad parameters window, you'll see the drop down menu to change the hole shape from circular to oval and add the proper numbers.

Based on the corresponding stray segments in the edge cuts layer; SH2 and SH3 holes should be Oval, X:1.6mm x Y:0.6mm, SH1 and SH4 holes should be Oval, X:1.56mm x Y:0.6mm.

Once you've changed the pad hole type + dimensions, then delete the corresponding segments on the edge cuts layer, and the 3D viewer now loads the board as desired.

Thanks for your work!

prusnak, 2021-02-15:
Please send a pull request - I have very little experience with KiCad.

enjoycowboy, 2021-02-16:
I have the board outline issue resolved, trying to figure out the board layer disposition to correctly reassign power planes, as those are borked on import from eagle

prusnak, 2021-02-16:
Closing this as @enjoycowboy has addressed the issues! Thank you!!!

Closed 2021-02-16.

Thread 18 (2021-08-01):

Unknown bootloader detected

btclinux, 2021-08-01:
Hi! I built firmware with docker script, flash the bootloader and install firmware with trezor suite. Is it possible to erase firmware from STM now? With st-link utilities I can't connect to device anymore. ST-flash give an error "unknown chip id! 0x5fa0004", openocd give "Error: init mode failed (unable to connect to the target)"

prusnak, 2021-08-01:
Check your wiring again (maybe SWCLK and SWDIO are swapped)?
Also check the soldering quality.

btclinux, 2021-08-02:
> Check your wiring again (maybe SWCLK and SWDIO are swapped)?
> Also check the soldering quality.

no, all connections is right also soldering quality is perfect, I can connect to another empty device also I can to connect to this device before

Closed 2021-08-01.

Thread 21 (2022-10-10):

I'm trying to set up my TREZØR and it doesn't show up on my devices

WhiteTrashRabbit615, 2022-10-10:

Closed 2022-10-10.

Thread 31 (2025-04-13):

doc: missing `.stl` files for `Safe 3` and `Safe 5`

0xClandestine, 2025-04-13:
Would be useful for creating accessories.

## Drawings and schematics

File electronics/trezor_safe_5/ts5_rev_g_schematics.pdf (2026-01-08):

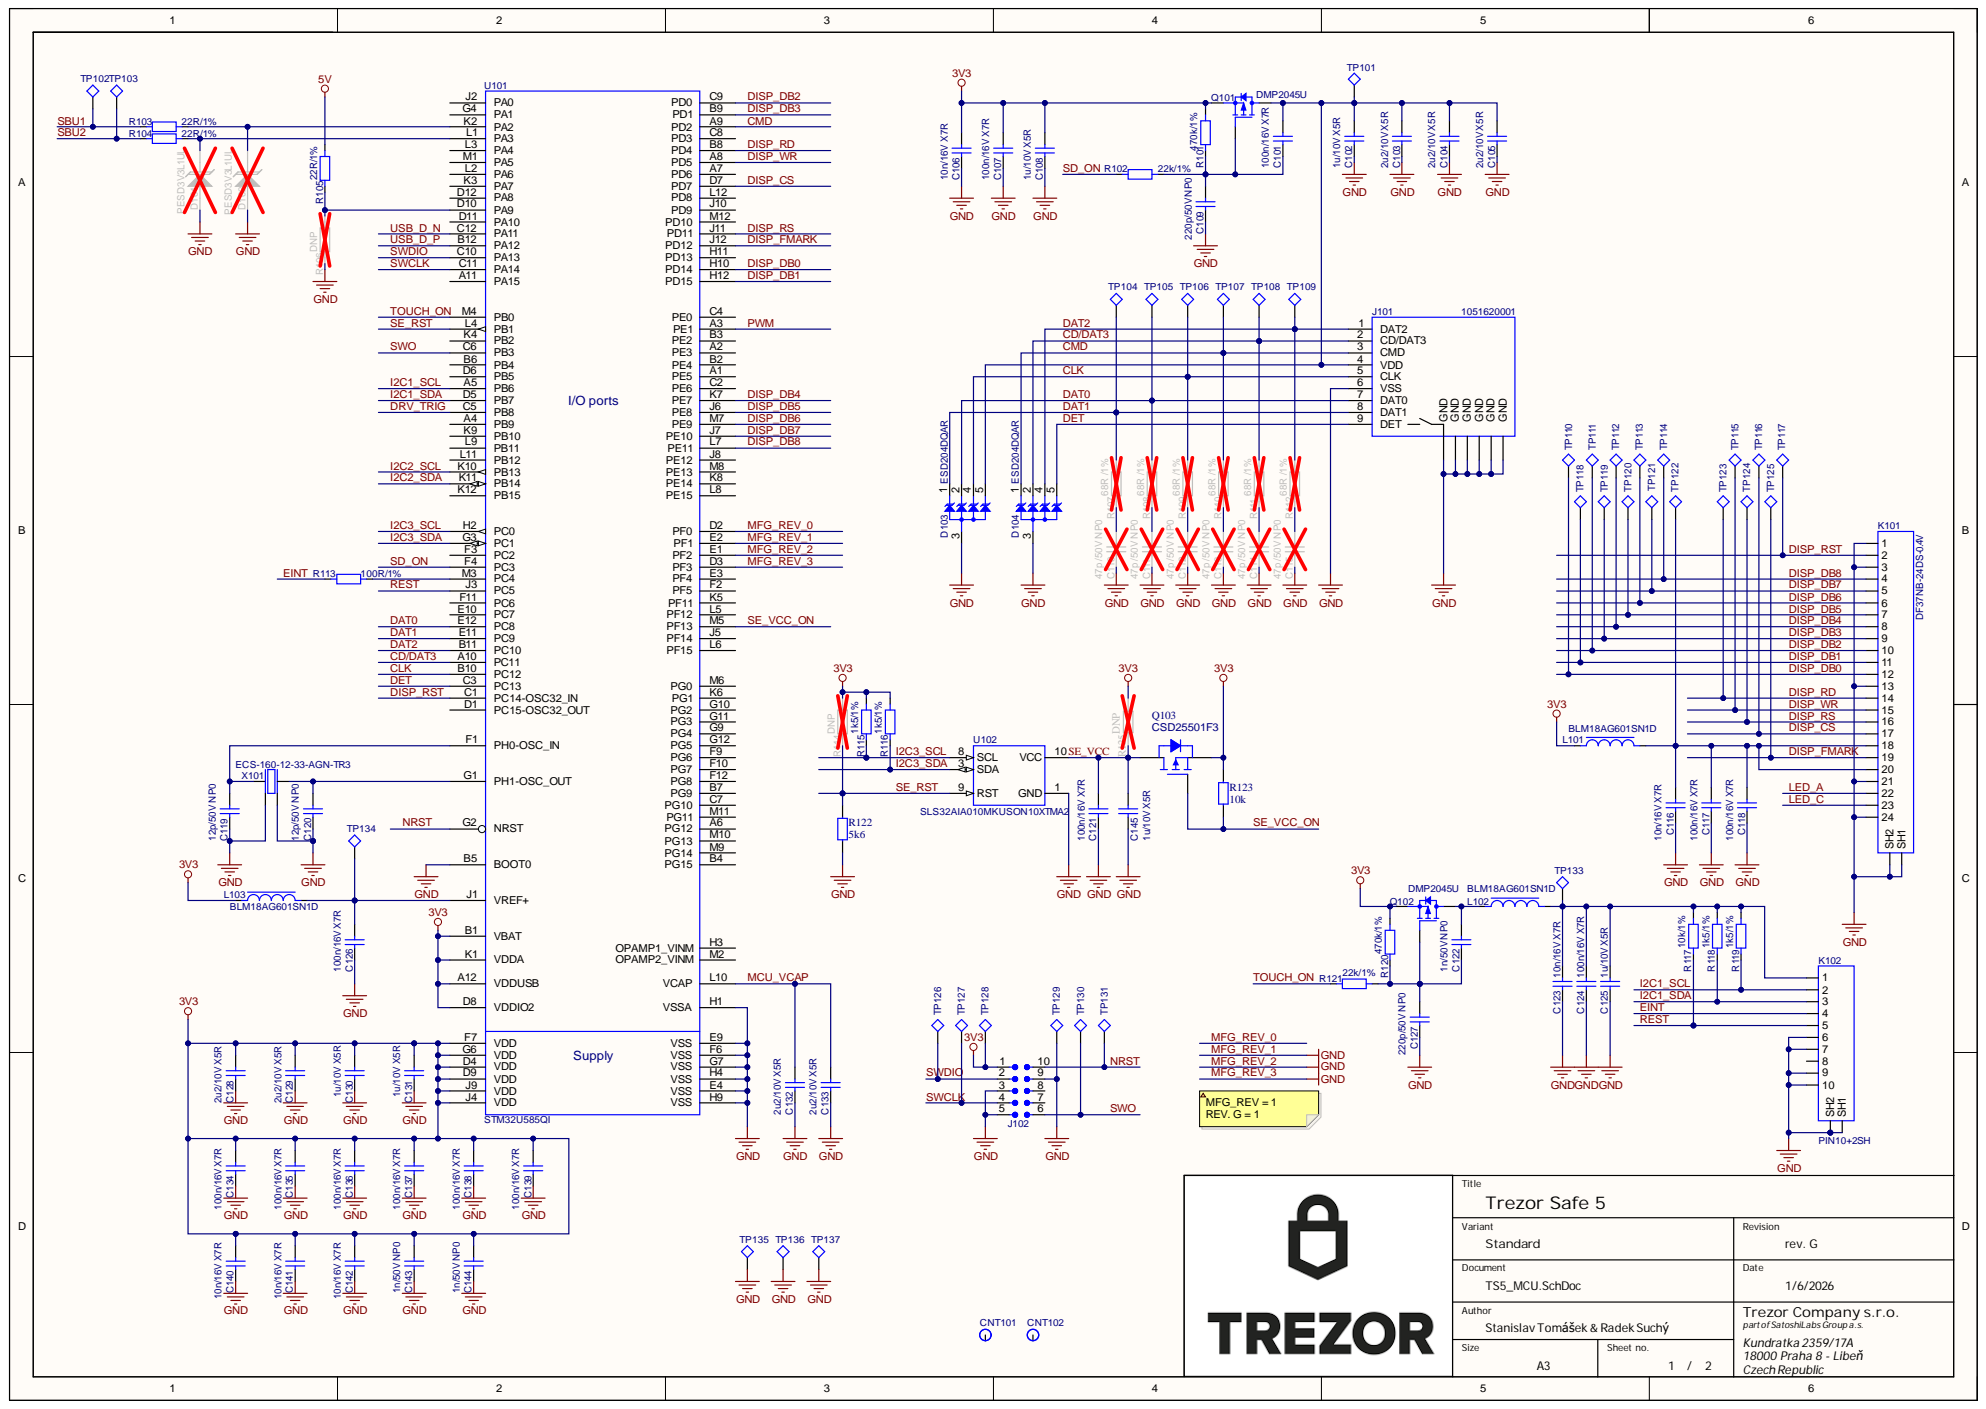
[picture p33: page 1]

PA4 L3
PA5 M1 | DISP_WR

DAT0 7

DISP_DB6 | | DET

DISP_DB7
DISP_DB6

DISP_DB3
DISP_DB2
DISP_DB1
DISP_DB0

DISP_RD
DISP_WR

VDDA K1

I2C1_SDA

VDDIO2 D8

10n/16V X7R GND GND GND GND

Title Trezor Safe 5

Variant Standard | Revision rev. G

Document TS5_MCU.SchDoc | Date 1/6/2026

Author
Stanislav Tomášek & Radek Suchý

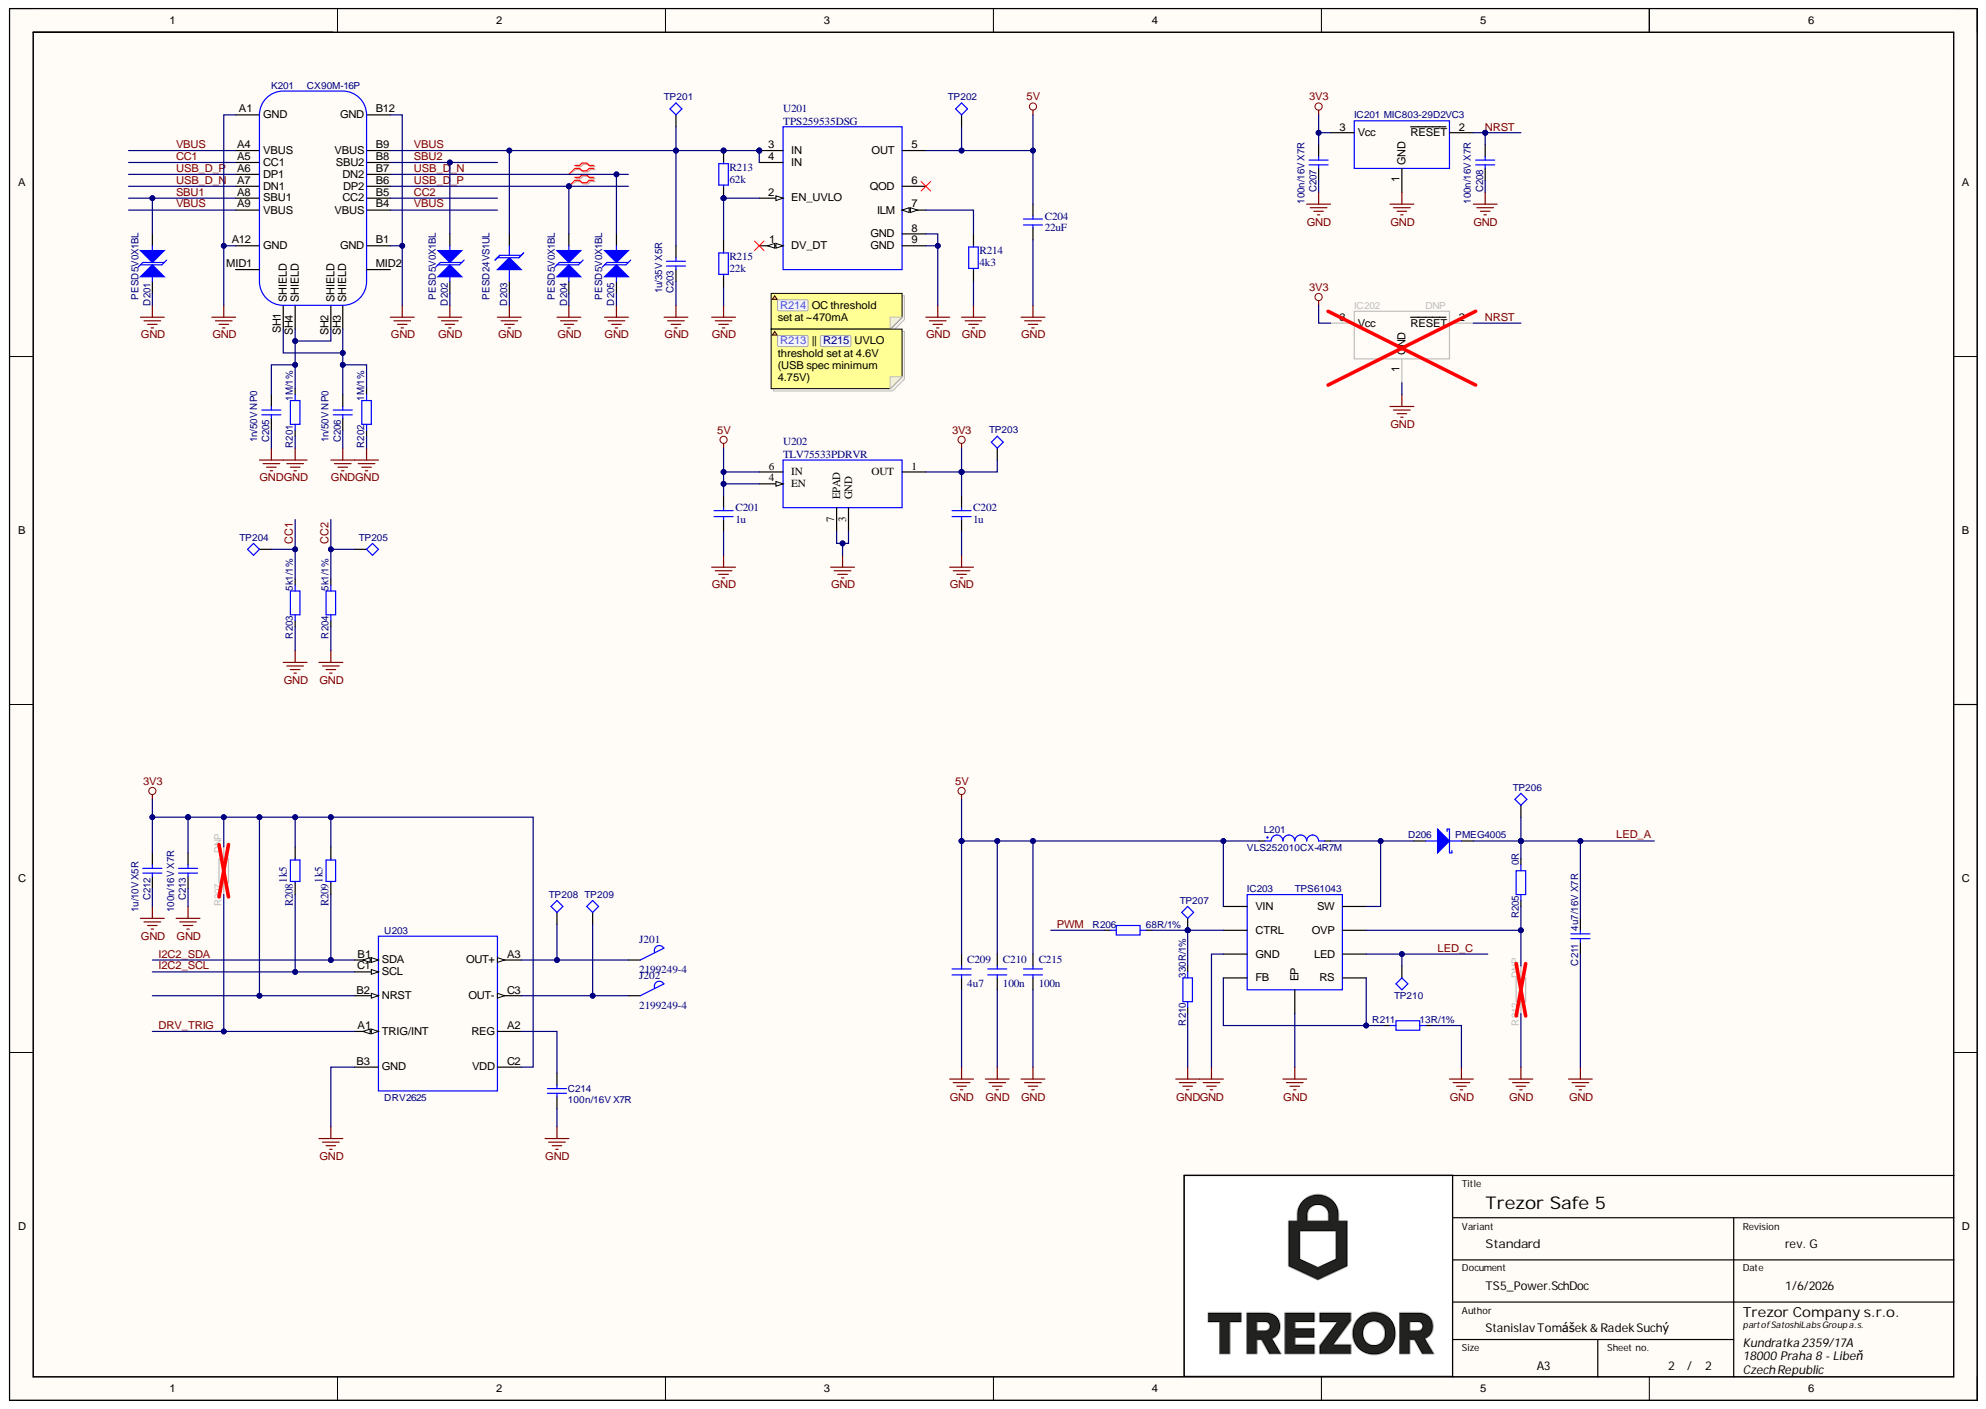
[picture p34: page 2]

Title Trezor Safe 5

Variant Standard | Revision rev. G

Document TS5_Power.SchDoc | Date 1/6/2026

Author Stanislav Tomášek & Radek Suchý | Trezor Company s.r.o. part of SatoshiLabsGroup a.s. Kundratka 2359/17A 18000 Praha 8 - Libeň Czech Republic

Size A3 | Sheet no. 2 / 2

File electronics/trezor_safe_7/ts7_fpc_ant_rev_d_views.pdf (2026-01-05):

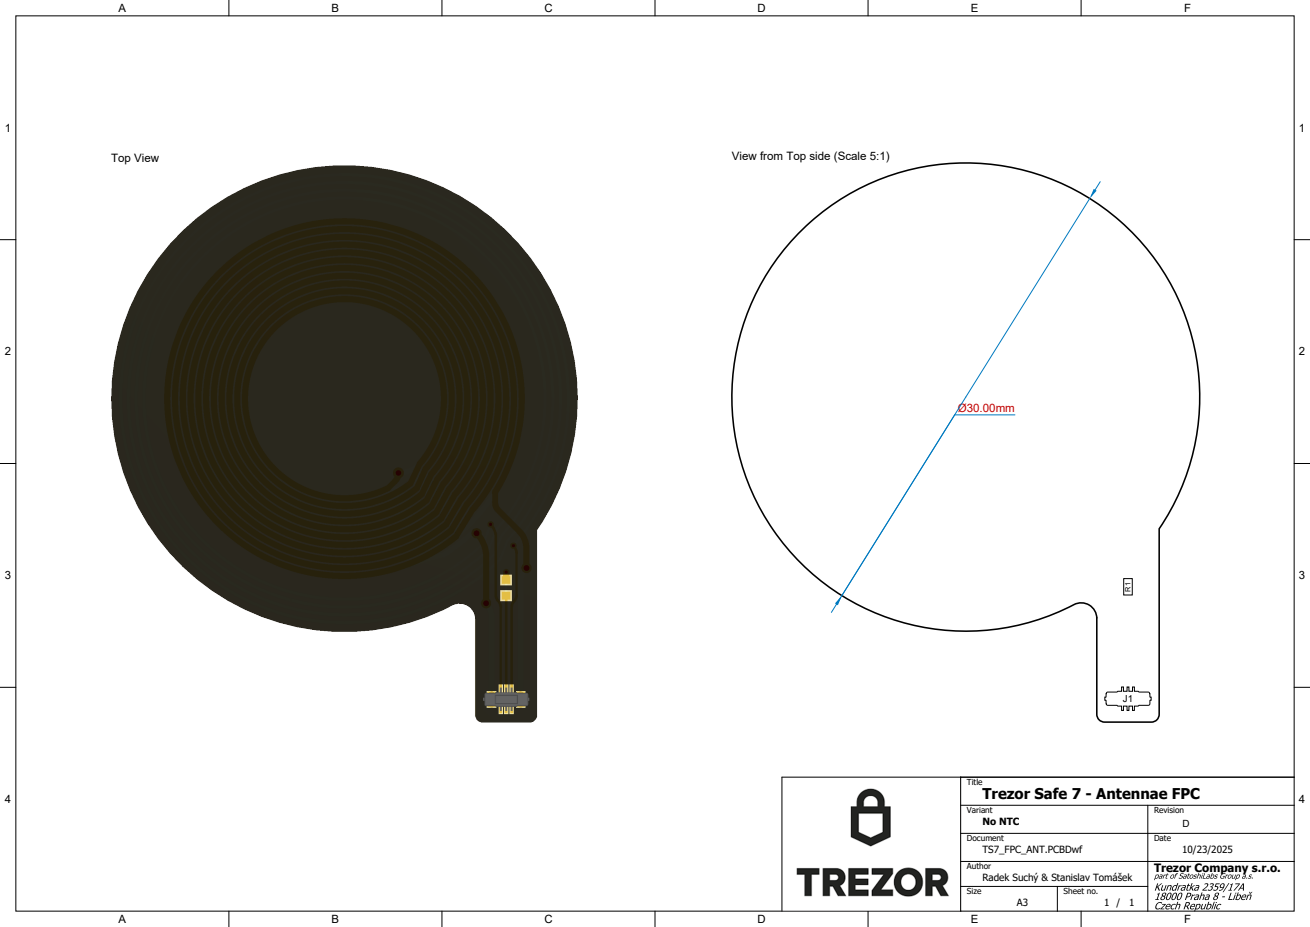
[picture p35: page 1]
Top View; View from Top side (Scale 5:1); Trezor Company s.r.o.; Date; Revision; Size; Sheet no.

Title
Trezor Safe 7 - Antennae FPC

Variant
No NTC
Document
TS7_FPC_ANT.PCBDwf
Author
Radek Suchý & Stanislav Tomášek

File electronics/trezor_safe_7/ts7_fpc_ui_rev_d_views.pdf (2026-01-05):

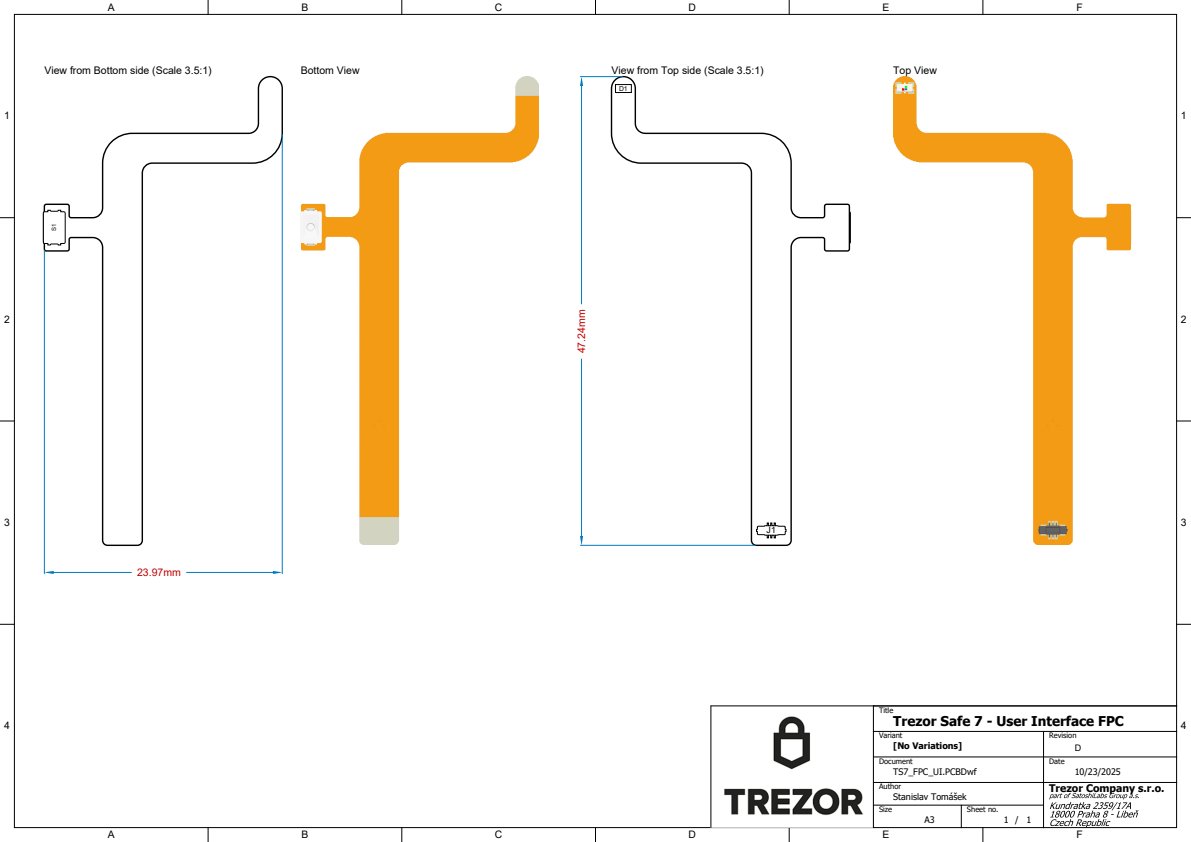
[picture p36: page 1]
View from Bottom side (Scale 3.5:1); Top View; Trezor Company s.r.o.; Date; Variant [No Variations]; Document; Stanislav Tomášek; Revision; Author; Size; Sheet no.; TS7_FPC_UI.PCBDwf; Bottom View

View from Top side (Scale 3.5:1)

Title
Trezor Safe 7 - User Interface FPC

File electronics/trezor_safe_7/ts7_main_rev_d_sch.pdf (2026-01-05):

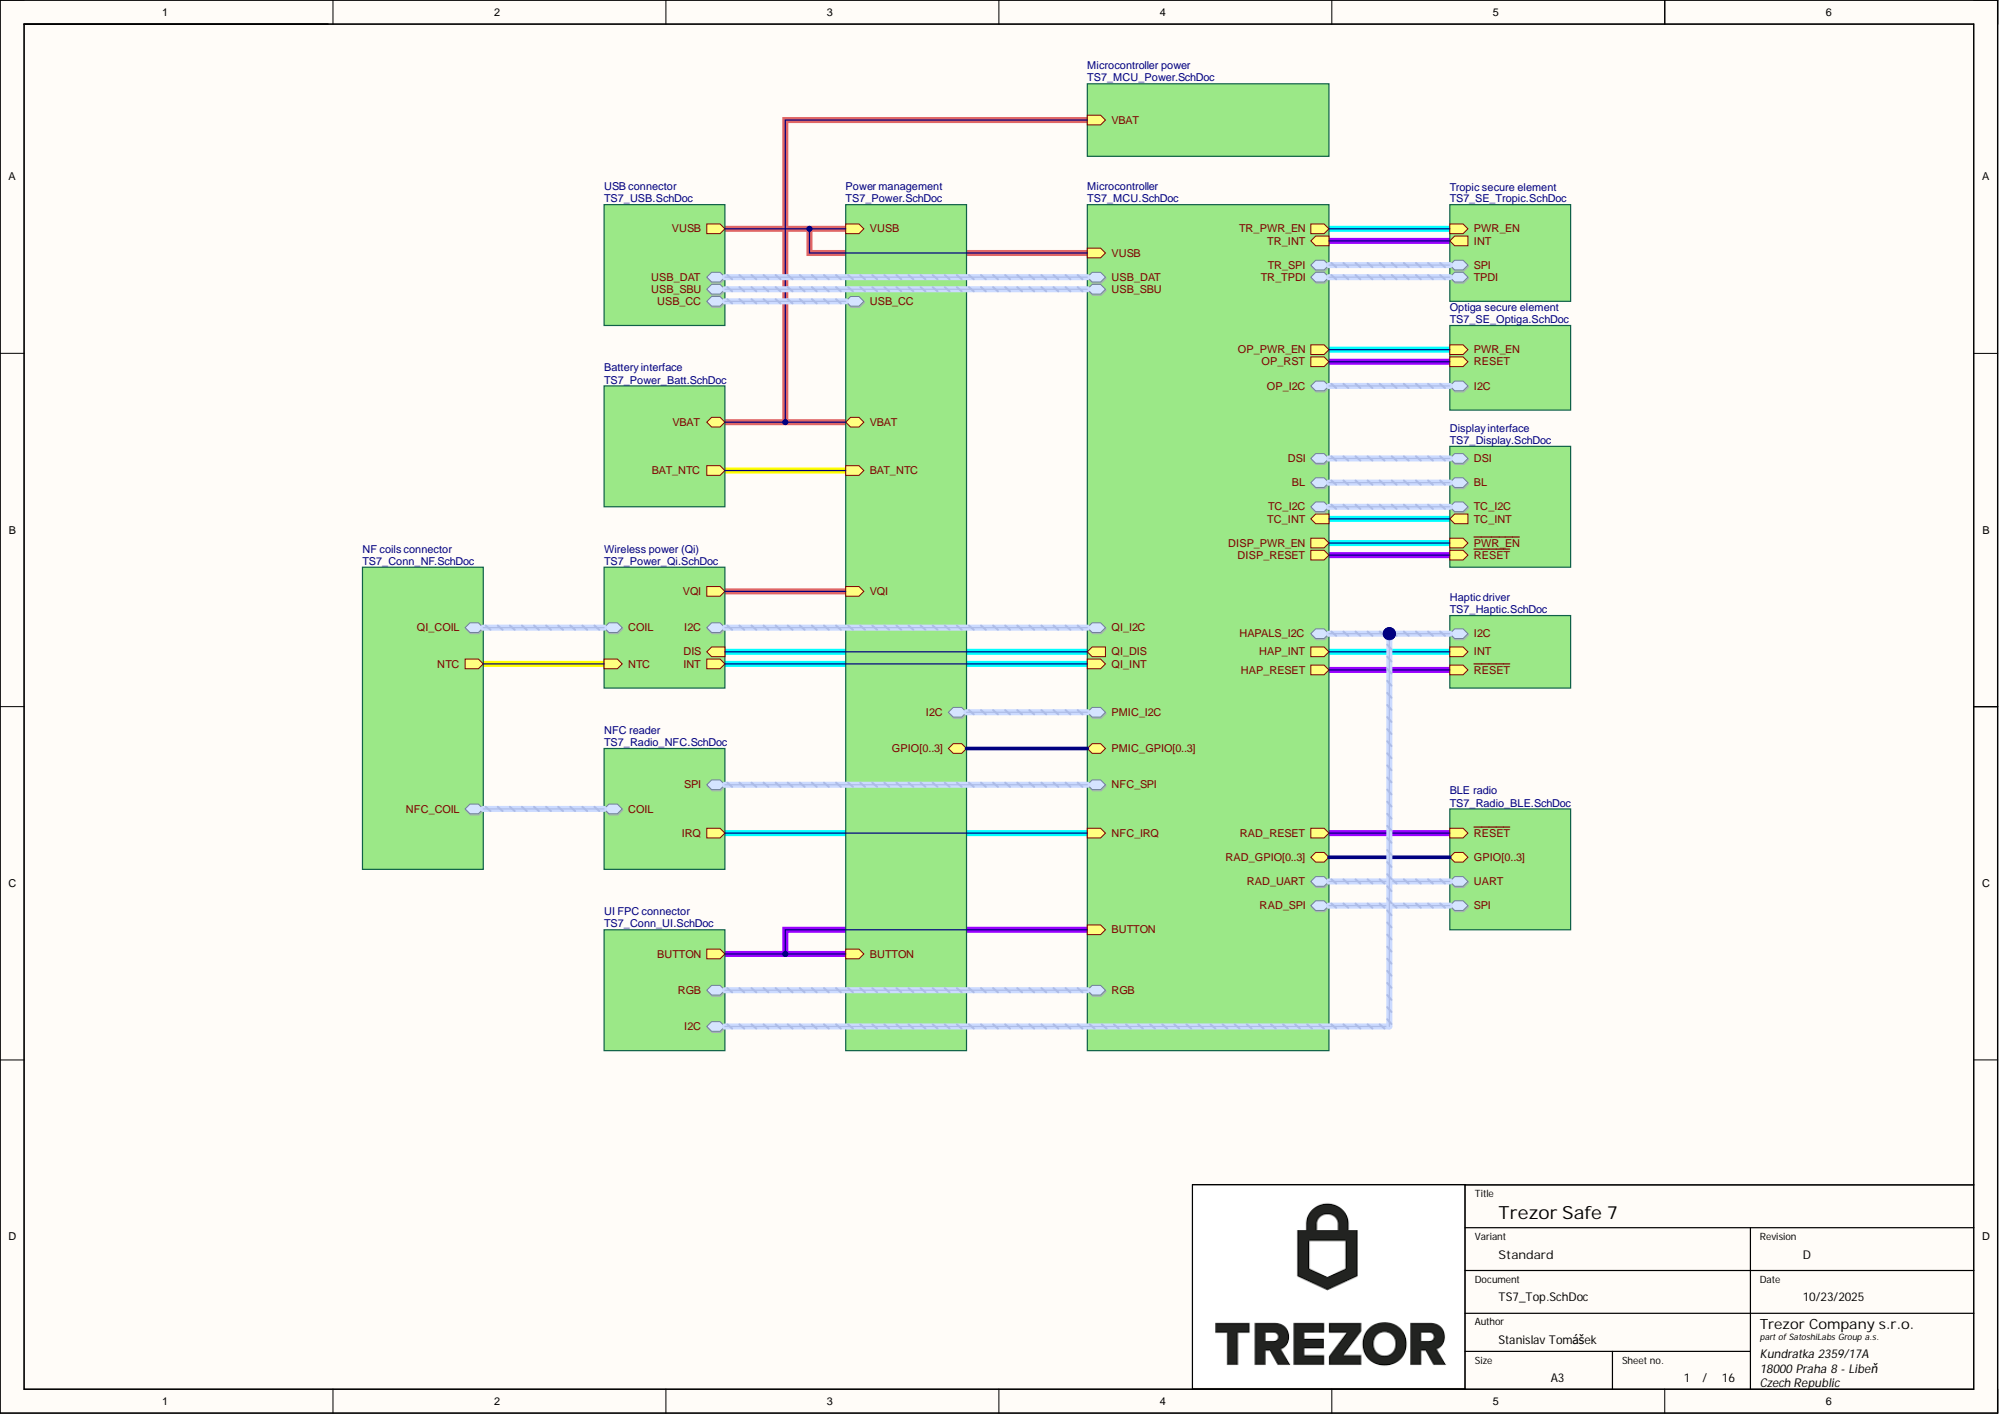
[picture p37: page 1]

USB_CC VBAT

BAT_NTC VQI

I2C GPIO[0..3]

TS7_Radio_BLE.SchDoc COIL

Title Trezor Safe 7

Variant Standard | Revision D

Document TS7_Top.SchDoc | Date 10/23/2025

Author Stanislav Tomášek | Trezor Company s.r.o. part of SatoshiLabs Group a.s. Kundratka 2359/17A 18000 Praha 8 - Libeň Czech Republic

Size A3 | Sheet no. 1 / 16

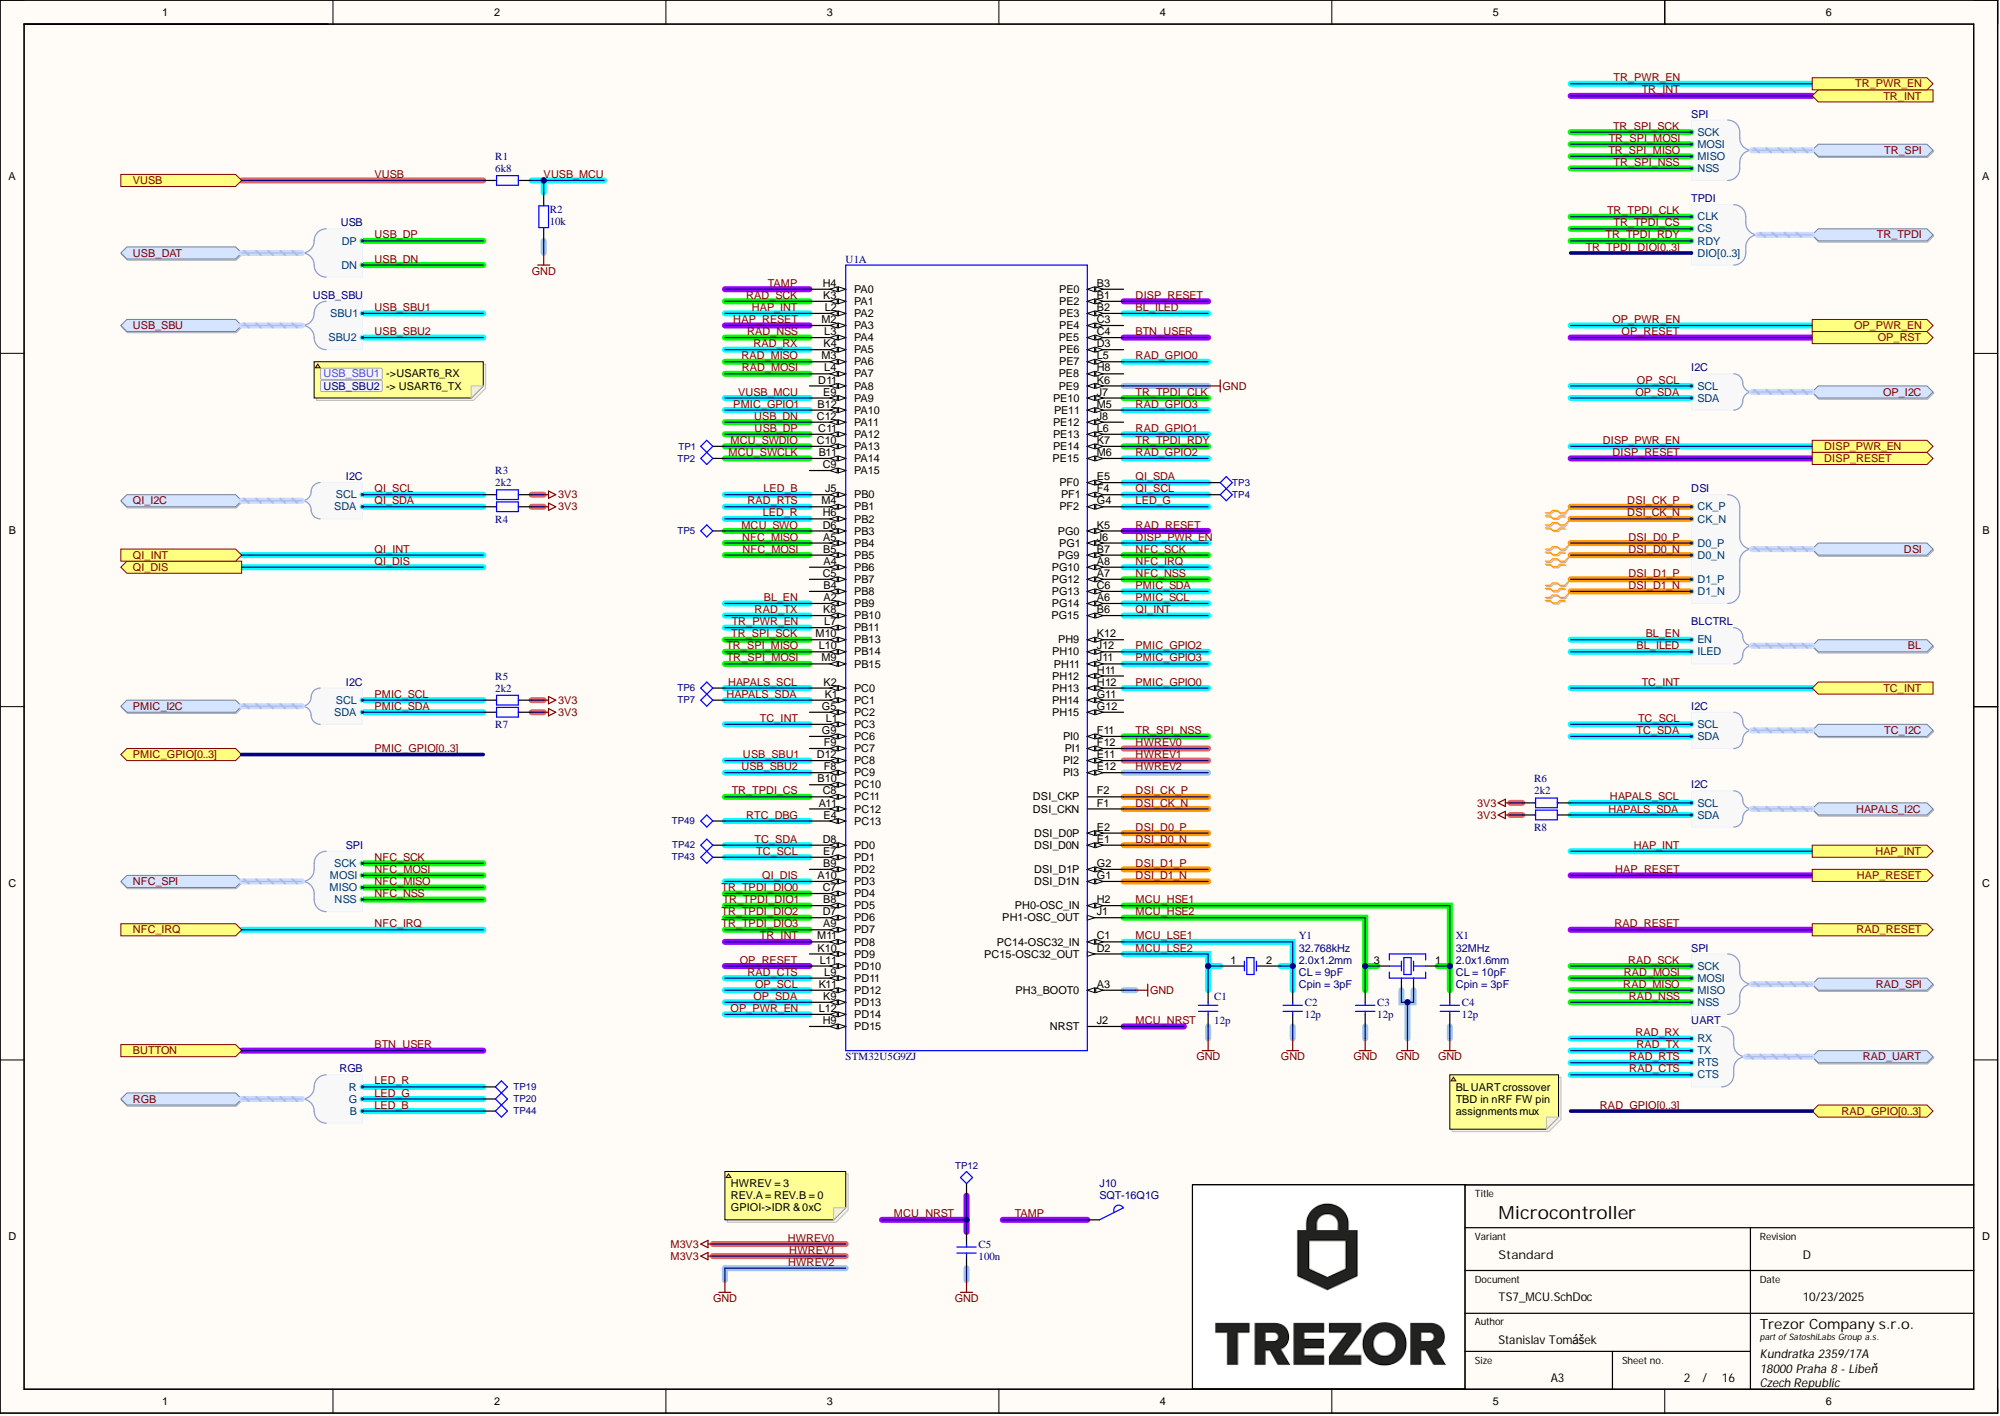
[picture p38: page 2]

T i t l e Microcon t r o l l e r

Variant Standar d | Rev isi o n D

Autho r Tomášek Stanislav | Trez or Co mpany s.r.o . part of Sa toshiLabs Group a .s. Kundratka 7A Praha 8 - Libeň Czech Republic

Size | Sheet no /

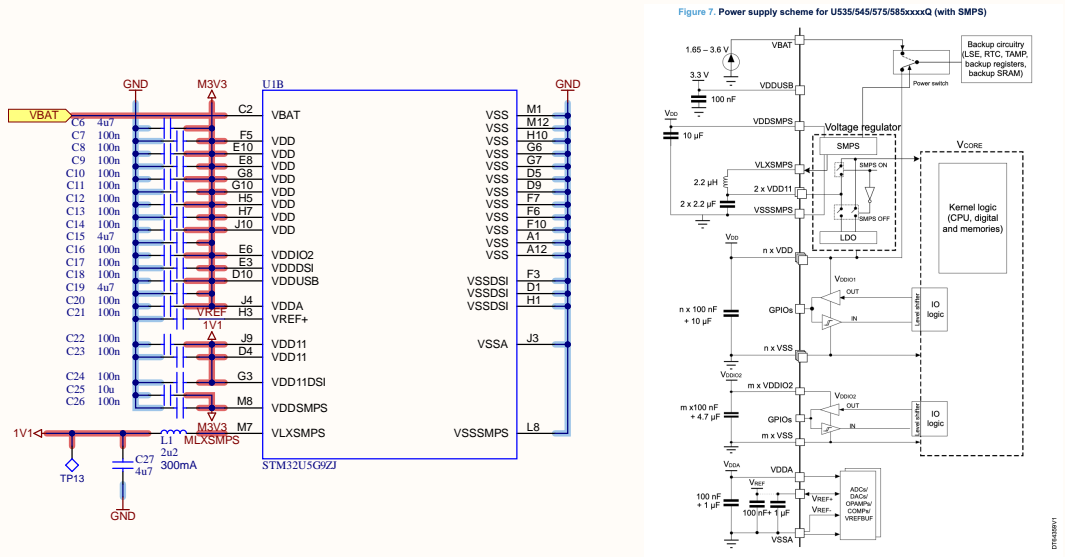
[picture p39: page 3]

H 5 | F7 6 VSS
H 7 | F
J 1 0 | F 1 0

T i t l e Microcontroller pow e r

Variant Standar d | Rev isi o n B

Do cumen t _MCU Power.SchD | Date

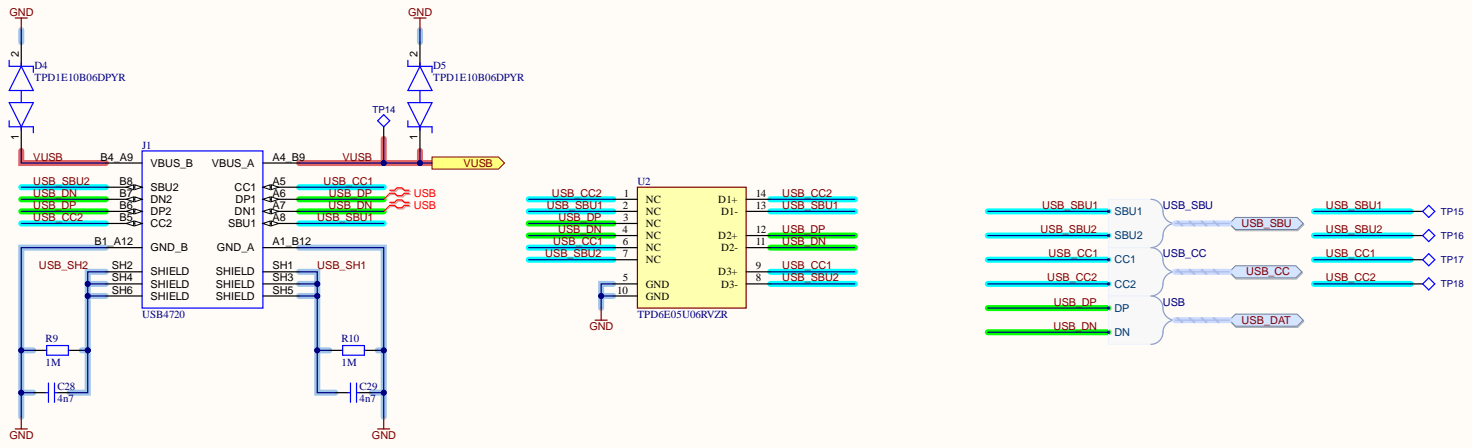
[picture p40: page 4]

T i t l e USB connector & protections

Variant Standar d | Rev isi o n B

Do cumen t USB.SchD | Date

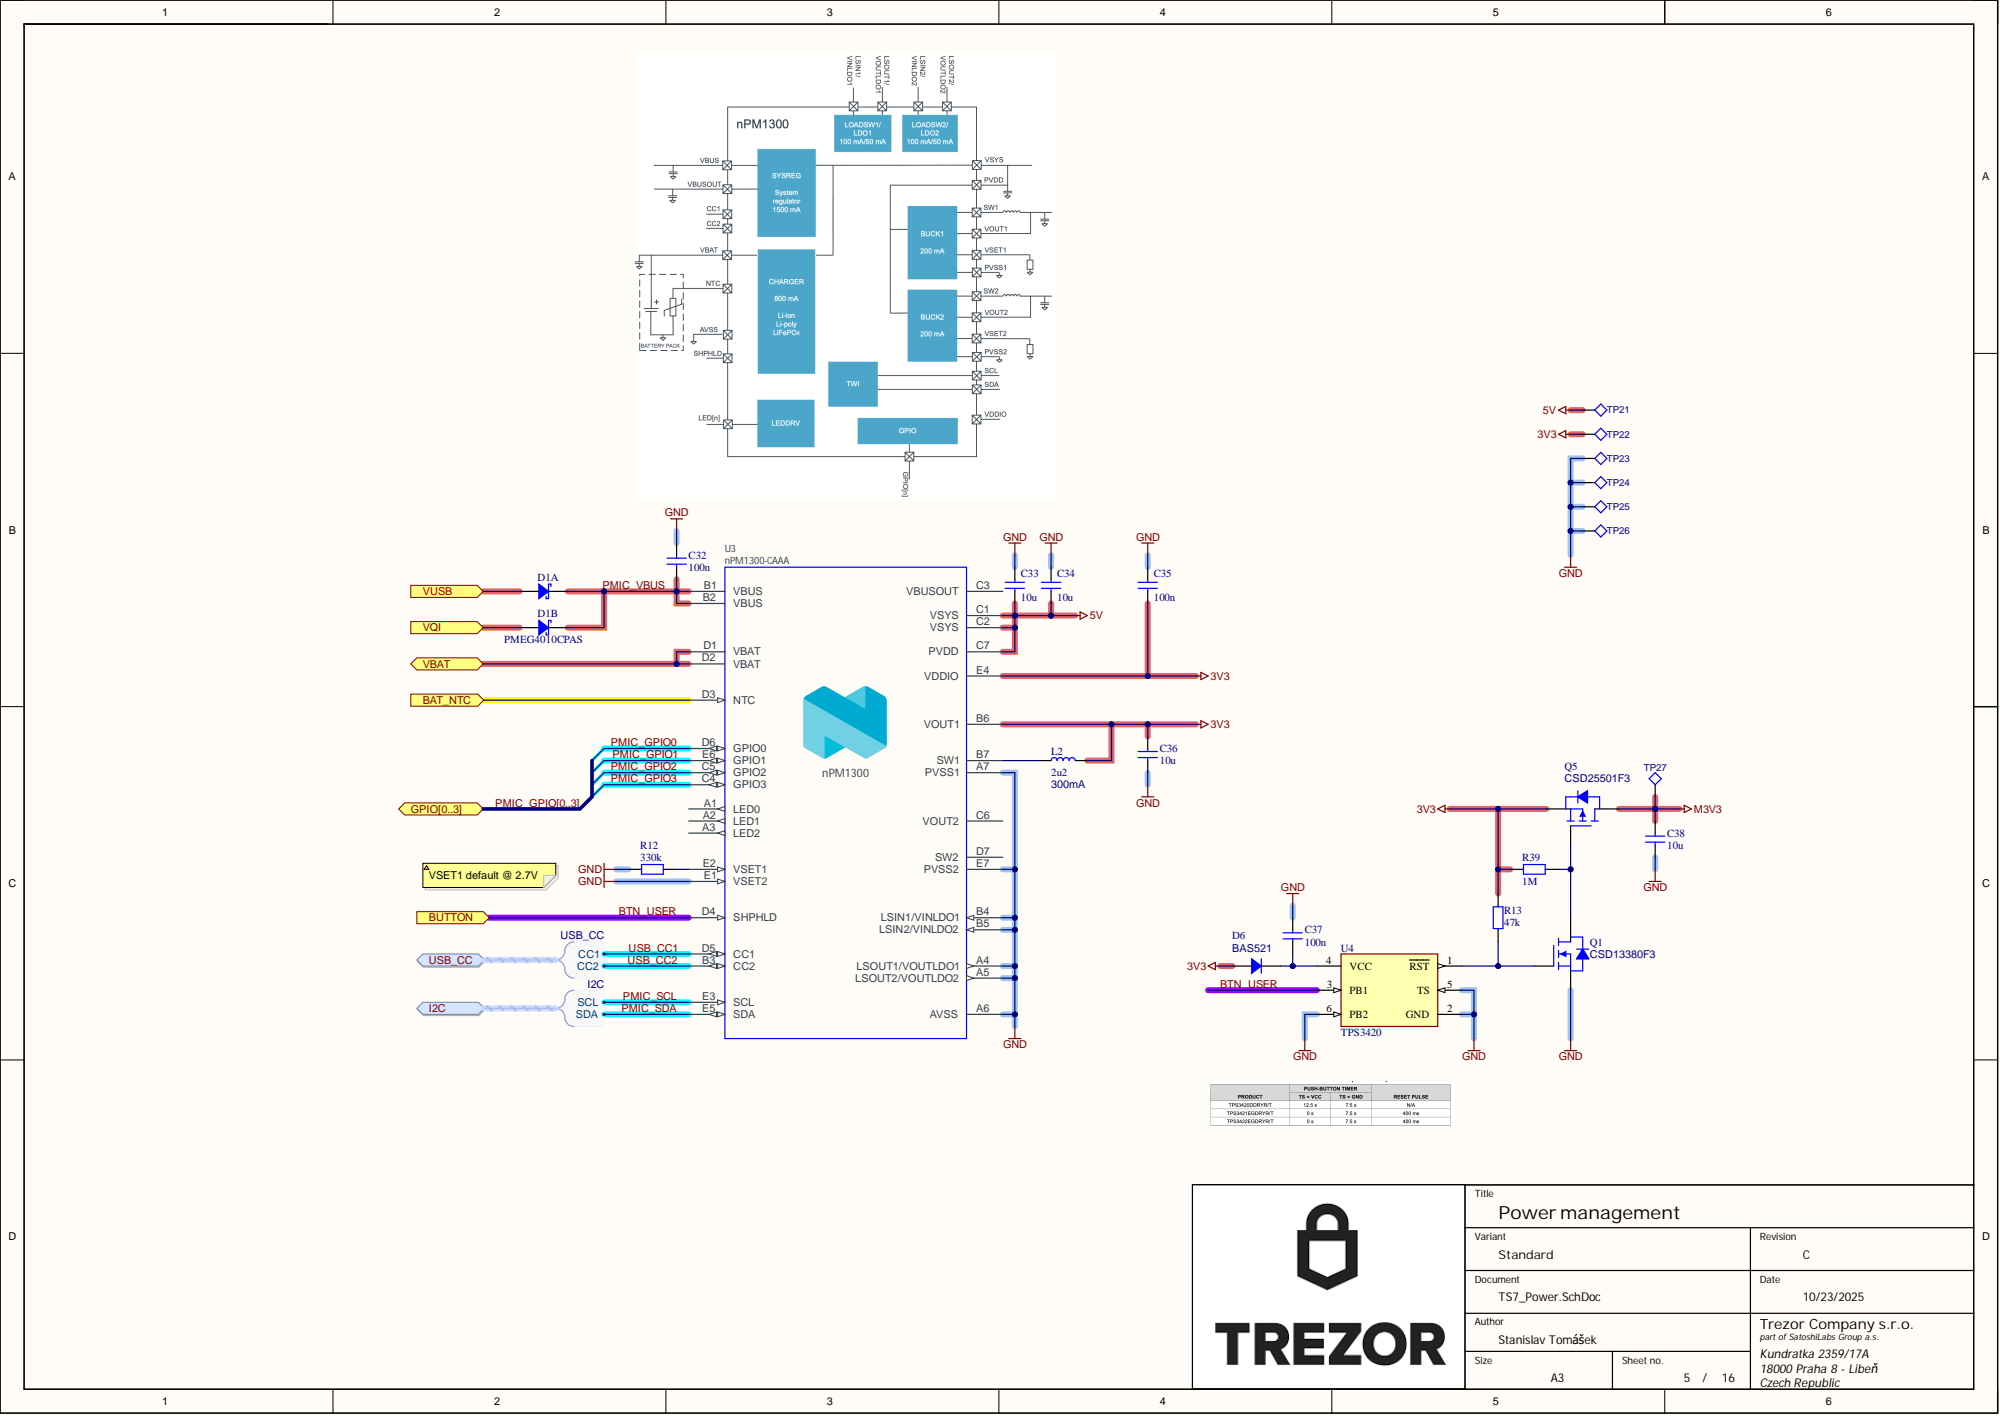
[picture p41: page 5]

T i t l e Power management

Variant Standar d | Rev isi o n C

Do cumen t Power.SchD | Date

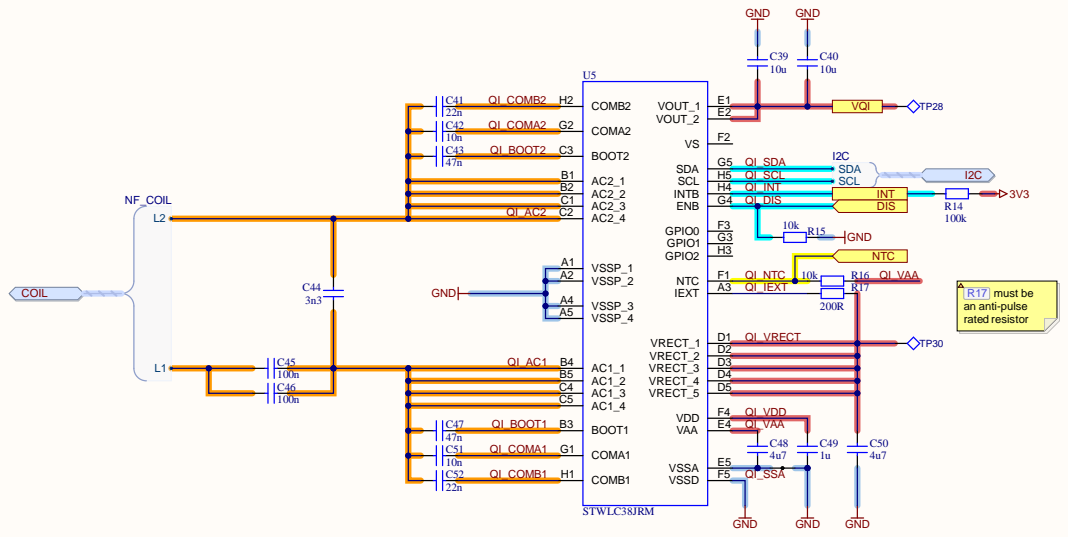
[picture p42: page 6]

C 4 | D 5
C 5 | F 4 QI_V D D

T i t l e Wireless power

Variant Standar d | Rev isi o n B

Do cumen t Power_Qi.SchD | Date

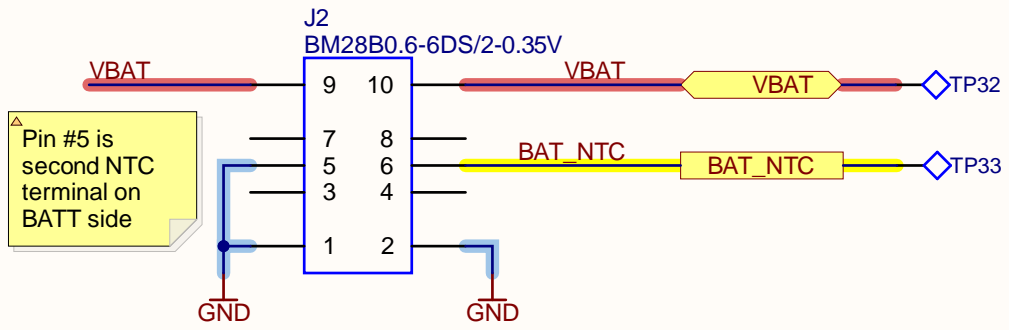
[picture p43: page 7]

Title Battery interface

Variant Standard | Revision B

Document TS7_Power_Batt.SchDoc | Date 10/23/2025

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

Size | Sheet no. 7 / 16

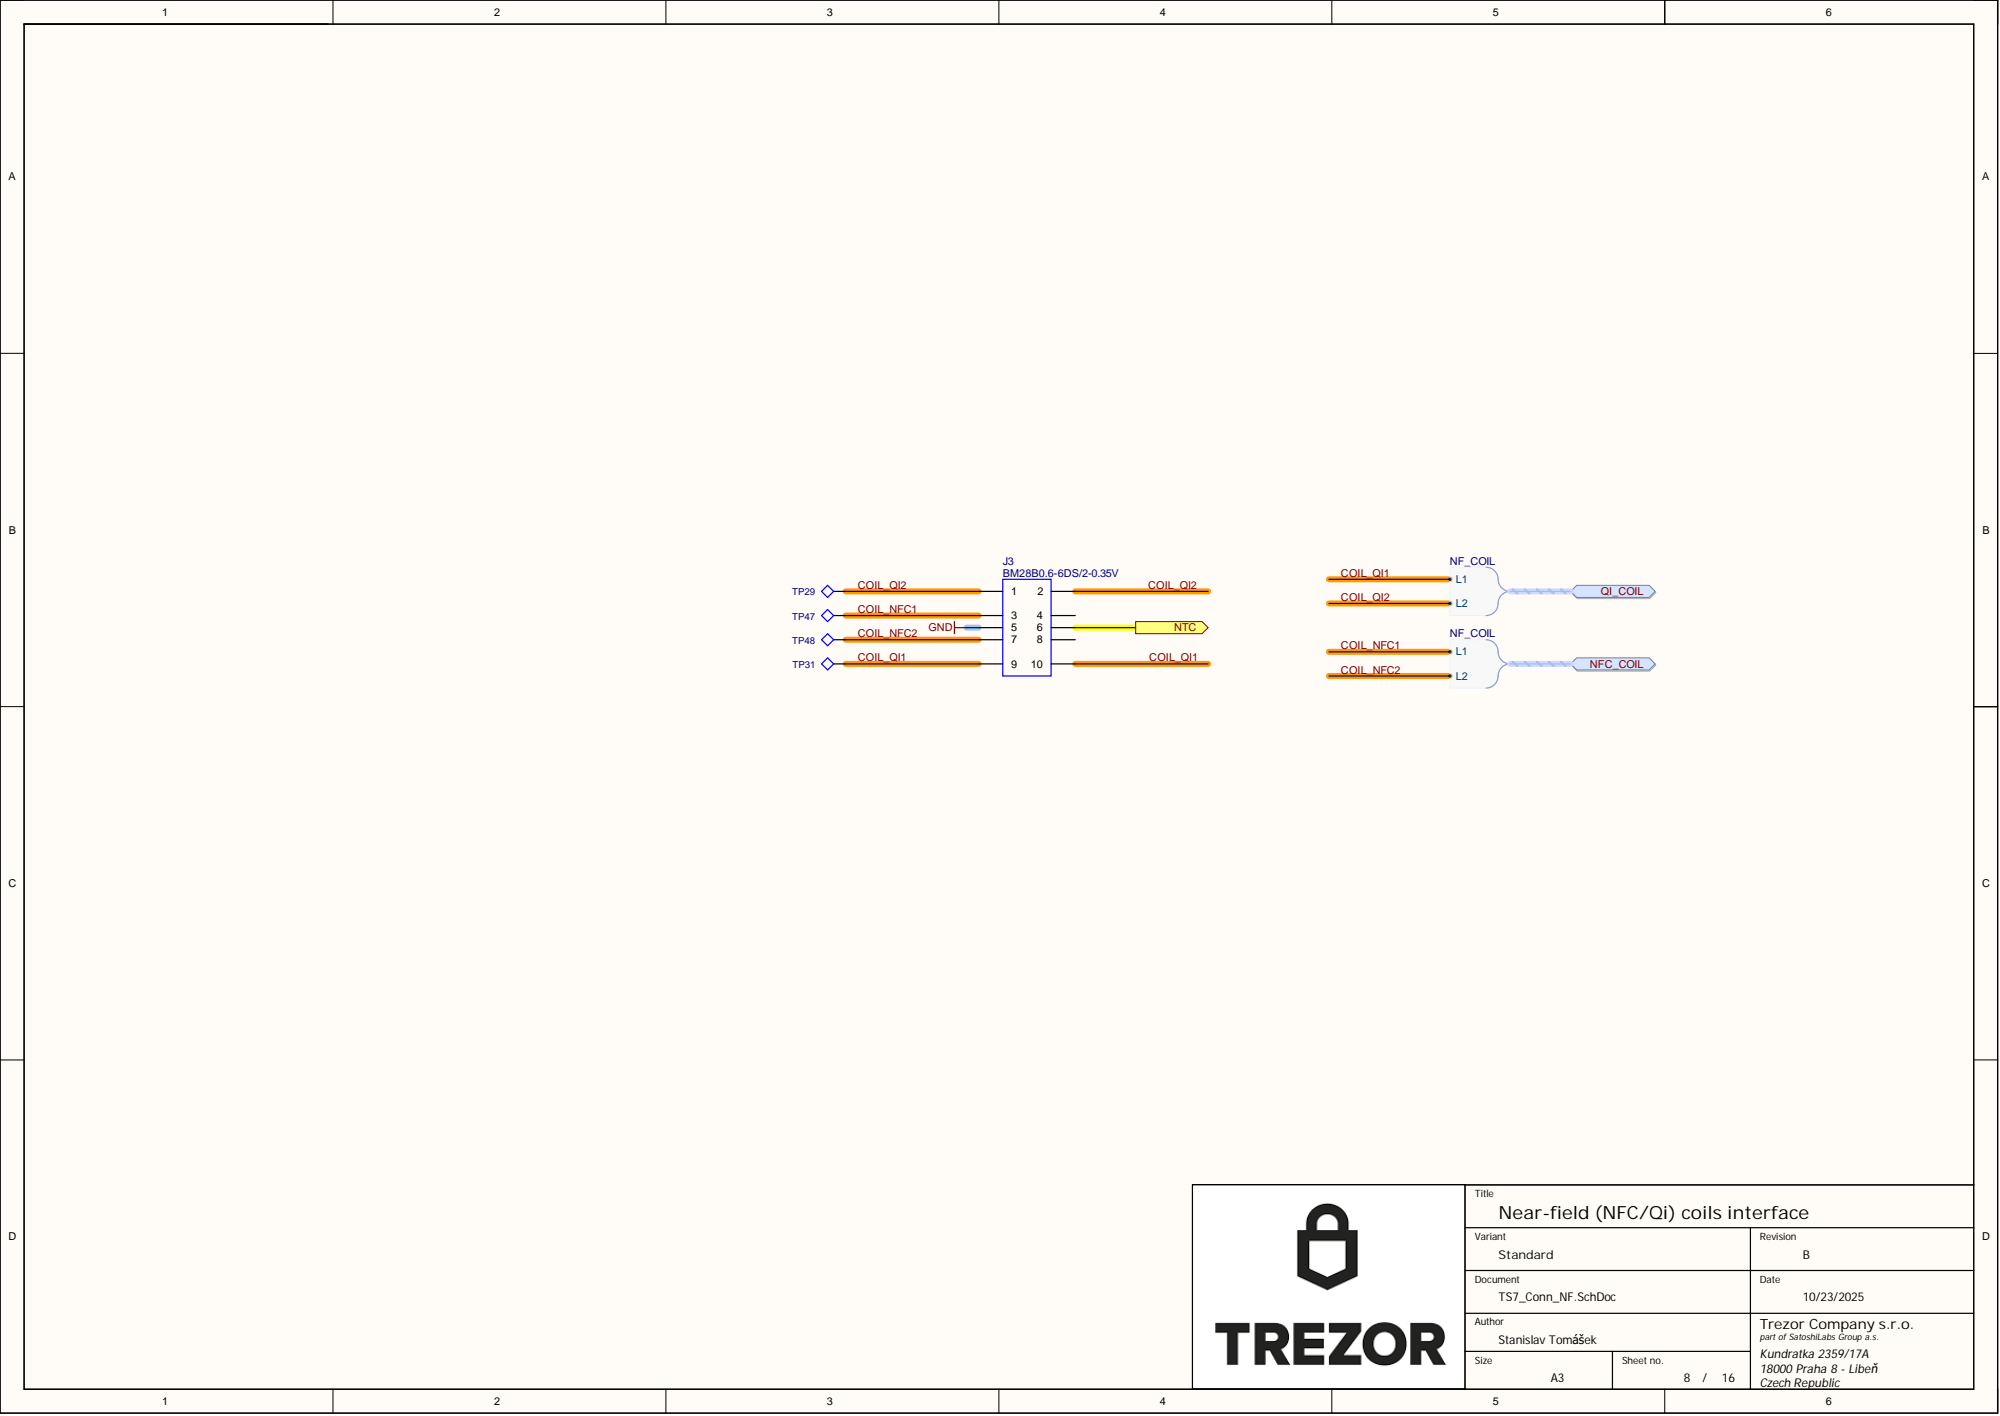
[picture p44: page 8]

T i t l e
Near-field (NFC/Qi) coils interfaceB 8 / 16 Variant Standar d | Rev isi o n

Do cumen t _Conn_NF.SchD | Date


DEC _2 | 1 0 | 0 n | C6 0

C 2 DEC _3 | C6 1 | 1 0 | 0 p

DEC _4 | 1 0 0 p | C6 | 2

T i t l e BLE/NFC radio

Variant Standar d | Rev isi o n D

Do cumen t Radio_ BLE.Sch D | Date


T i t l e NFC Reader

Variant Standar d | Rev isi o n B

Do cumen t Radio_NFC.Sch D | Date


T i t l e T ropic secure element

Variant Standar d | Rev isi o n C

Do cumen t _SE_ Tropic.Sch D | Date


T i t l e Optiga secure element

Variant Standar d | Rev isi o n A

Do cumen t _SE_Optiga.Sch D | Date


Title Display interface

Variant Standard | Revision C

Document TS7_Display.SchDoc | Date 10/23/2025

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

Size | Sheet no. 13 / 16


T i t l e Haptic driver

Variant Standar d | Rev isi o n C

Do cumen t _Haptic.SchD | Date


nPM has an internal PU

T i t l e UI FPC interface

Variant Standar d | Rev isi o n D

Do cumen t _Conn_ UI.SchD | Date

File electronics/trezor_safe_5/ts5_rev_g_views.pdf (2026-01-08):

A

B


View from Top side (Scale 2.5:1)

View from Bottom side (Scale 2.5:1)

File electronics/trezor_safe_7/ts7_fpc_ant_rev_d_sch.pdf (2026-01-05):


T i t l e Trezor S afe 7 - Anten n ae FPC

V a r i antN o N T C | Revisi o n D

Do cu m ent Radek Suc TS7_FPC_AN T_Top. Sch D oc | Da t e 9/2/2025

A u tho r ý á š h & Stanisl av Tom e k | Trezor Compan y s.r.o. part of Satoshi LabsGro up a. s. Kundra tka 2359/1 7A 18000 Praha 8 - Libeň Czech Republ ic

Size A 3 | She e t no . 1 / 1

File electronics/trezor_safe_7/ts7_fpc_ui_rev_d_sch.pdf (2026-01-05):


Title Trezor Safe 7 - User Interface FPC

Variant [NoVariations] | Revision D

Document TS7_FPC_UI_Top.SchDoc | Date 9/2/2025

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

Size A3 | Sheet no. 1 / 1

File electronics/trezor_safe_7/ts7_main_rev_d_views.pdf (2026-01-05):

AA

BB


View from Top side (Scale 3.5:1)

View from Bottom side (Scale 3.5:1)

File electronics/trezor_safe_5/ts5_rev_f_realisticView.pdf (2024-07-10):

A

B


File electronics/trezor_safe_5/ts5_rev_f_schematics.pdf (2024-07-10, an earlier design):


PA3 L1 | DISP_RD
PA4 L3
PA5 M1 | DISP_WR

CLK | | VDD 4

DAT0 | | VSS 6

DAT0 7

DISP_DB4
DISP_DB3
DISP_DB2

DISP_RD
DISP_WR
DISP_RS

ECS-160-12-33-AGN-TR3 | PH1-OSC_OUT G1

NRST G2 BOOT0 B5

I2C1_SCL
I2C1_SDA

VDDA K1

VDDUSB A12

VDDIO2 D8

10n/16V X7R GND GND GND GND

Title Trezor Safe 5

Variant Standard | Revision rev. F

Document TS5_MCU.SchDoc | Date 6/17/2024

Author Radek Suchý | Trezor Company s.r.o. part of SatoshiLabs Group a.s. Kundratka 2359/17A 18000 Praha 8 - Libeň Czech Republic


Title Trezor Safe 5

Variant Standard | Revision rev. F

Document TS5_Power.SchDoc | Date 6/17/2024

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

Size A3 | Sheet no. 2 / 2

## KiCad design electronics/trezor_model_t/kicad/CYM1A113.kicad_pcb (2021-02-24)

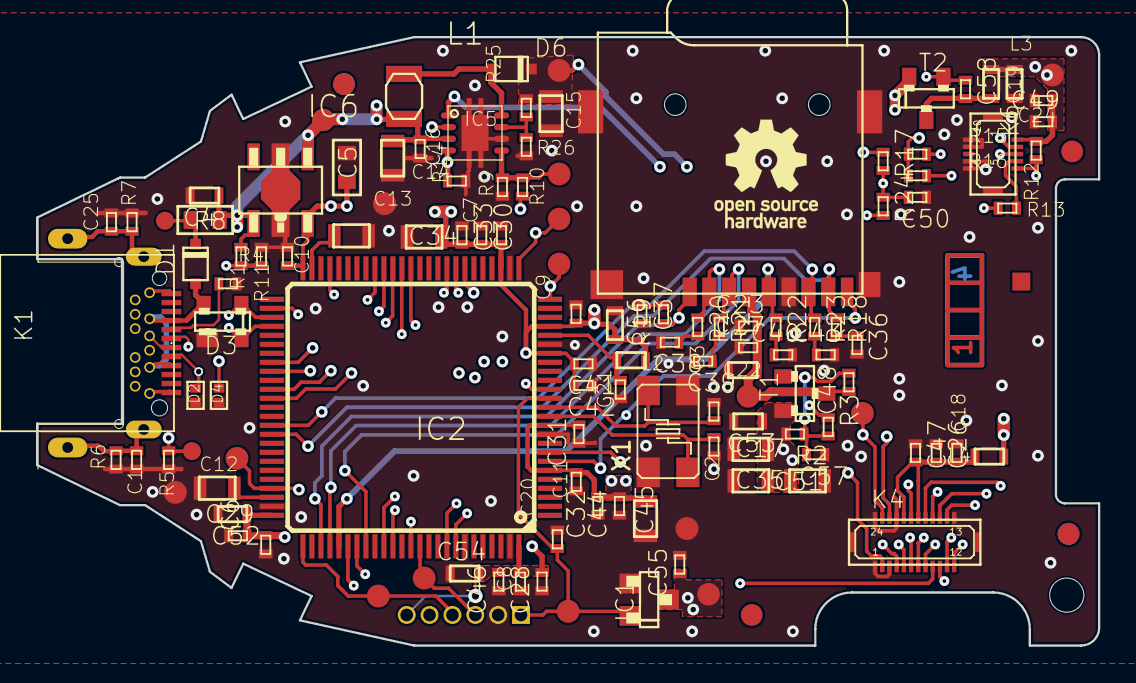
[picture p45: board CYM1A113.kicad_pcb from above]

Board: 4 copper layers, 59.0 x 33.8 mm, 132 parts (0 on the bottom side), 71 nets.

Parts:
@HOLE0: (no value)
C1, C11, C25, C33, C46, C58: 1n; 0402
C2, C3: 22p; 0402
C4, C19, C22, C52, C53, C54, C56: 1u; 0603_REFLOW
C5: 1u; 0603
C6, C8, C23, C30, C32, C42, C47, C49: 10n; 0402
C7, C9, C10, C16, C18, C20, C21, C24, C26, C27, C28, C29, C31, C41, C44, C48, C55: 100n; 0402
C12, C13, C17, C34, C35, C45, C51: 2u2; 0805_REFLOW
C14, C15: 4u7/16V; 0805_REFLOW
C36, C37, C38, C39, C40, C43: 47p; 0402
C50, C57: 220p; 0402
D1: PMEG3005; SOD323F
D2, D4: PESD5V0F1BLD; SOD882D
D3: PRTR5V0U2X; SOT143B_REFLOW
D6: PMEG4005; SOD323F
IC1: MIC803-29D2VC3; SOT23_MEDIUM_SIZE
IC2: STM32F427VIT6; LQFP100_NO_CENTER_NO_TDOCU
IC5: TPS61043; WSON-8_3X3MM
IC6: XC6210B332PR; SOT89-5
K1: DX07B024XJ1R1300; USB_C_JAE_DX07B024XJ1
K3: ATTEND_112J-TDAR-R01; ATTEND_112J-TXAR-R01_SMALL
K4: DF37NB-24DS-0.4V
K5: SWD
K6: DF37NB-10DS-0.4V
L1: 4u7 VLS252008ET-4R7M; L_2.5X2.0
L2, L3, L4: BLM18AG102SN1D; 0603_REFLOW
R1: 22R; 0402
R2, R17: 470k; 0402
R3, R24: 22k; 0402
R4, R5: 5k1; 0402
R6, R7: 1M; 0402
R8: MF-FSMF020X-2; 0603
R9: 330R; 0402
R10, R18, R19, R20, R21, R22, R23: 68R; 0402
R11, R26: N.C.; 0402
R12: 10k; 0402
R13: 100R; 0402
R14: 27R; 0402
R15, R16: 1k5; 0402
R25: 0R; 0402
T1, T2: DMP2045U; SOT23_REFLOW
TP1, TP2, TP4, TP6, TP7, TP8, TP9, TP12, TP13, TP14, TP15, TP16: MB_1.27; MB1.27
TP3, TP5, TP10, TP11: MB_1.50; MB1.5
TP19, TP20: MB_1.00
U$45, U$46, U$48, U$49, U$56, U$57: CENTR
U$47: BADMARK
U$54: LAYER_STACK_4_LAYERS
X1: CTS406 8MHz; X6,0X3,5

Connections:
/CC1: K1.A5, R4.P$2
/CC2: R5.P$2, TP20.1
/DN: D3.3, IC2.53, K1.A7, K1.B7
/DP: D3.2, IC2.54, K1.A6, K1.B6
/HS_VBUS: IC2.52, R1.P$1, R11.P$1
/LEDA: C15.2, D6.K, K4.22, R25.P$1, TP7.1
/LEDK: IC5.1, K4.23, TP4.1
/MCU_EINT: IC2.33, R13.P$2
/PWM: IC2.32, R10.P$1
/REST: IC2.34, K6.5, R12.P$2
/SBU1: D2.2, IC2.25, TP10.1
/SBU2: D4.2, IC2.26, TP11.1
/SD_ON: IC2.15, R3.P$1
/TOUCH_ON: IC2.47, R24.P$2
/VBUS: D1.A, D3.4, K1.A4, K1.B9
GND: C1.P$1, C2.P$1, C3.P$1, C4.1, C5.1, C6.P$1, C7.P$1, C8.P$1, C9.P$1, C10.P$1, C11.P$1, C12.1, C13.1, C14.2, C15.1, C16.P$1, C17.1, C18.P$1, C19.1, C20.P$1, C21.P$1, C22.1, C23.P$1, C24.P$1, C25.P$1, C26.P$1, C27.P$1, C28.P$1, C29.P$1, C30.P$1, C31.P$1, C32.P$1, C33.P$1, C34.1, C35.1, C36.P$2, C37.P$2, C38.P$2, C39.P$2, C40.P$2, C41.P$1, C42.P$1, C43.P$2, C44.P$1, C45.1, C46.P$1, C47.P$1, C49.P$1, C50.P$1, C51.1, C52.1, C53.1, C54.2, C55.P$2, C56.2, C57.P$1, D2.1, D3.1, D4.1, IC1.1, IC2.10, IC2.20, IC2.27, IC2.74, IC2.94, IC2.99, IC5.6, IC5.EP, IC5.EP$1, IC5.EP$2, IC5.EP$3, IC5.EP$4, IC6.2, K3.6, K3.GND@1, K3.GND@2, K3.GND@3, K3.GND@4, K4.1, K4.3, K4.13, K4.21, K4.24, K4.25, K4.26, K5.GND, K6.6, K6.7, K6.9, K6.10, K6.11, K6.12, R4.P$1, R5.P$1, R6.P$1, R7.P$1, R9.P$1, R11.P$2, R14.P$1, R26.P$2, TP9.1, TP12.1, TP13.1, X1.2, X1.4
unnamed: C1.P$2, R6.P$2
unnamed: C2.P$2, IC2.12, X1.1
unnamed: C3.P$2, IC2.13, X1.3
unnamed: C12.2, IC2.73
unnamed: C13.2, IC2.49
unnamed: C18.P$2, C26.P$2, C47.P$2, K4.18, K4.20, L4.1
unnamed: C20.P$2, IC1.2, IC2.14, K5.RST, TP14.1
unnamed: C21.P$2, IC2.21, L2.2
unnamed: C22.2, C23.P$2, C27.P$2, C48.P$1, K3.4, T1.3, TP15.1
unnamed: C25.P$2, K1.SH1, K1.SH2, R7.P$2
unnamed: C36.P$1, R18.P$2
unnamed: C37.P$1, R19.P$2
unnamed: C38.P$1, R20.P$2
unnamed: C39.P$1, R21.P$2
unnamed: C40.P$1, R22.P$2
unnamed: C43.P$1, R23.P$2
unnamed: C48.P$2, C57.P$2, R2.P$1, R3.P$2, T1.2
unnamed: C50.P$2, C58.P$1, R17.P$2, R24.P$1, T2.2
unnamed: C58.P$2, L3.1, T2.3
unnamed: D1.K, R8.2, TP19.1
unnamed: D6.A, IC5.8, L1.2
unnamed: IC2.7, K3.CD
unnamed: IC2.8, K4.2
unnamed: IC2.38, K4.8
unnamed: IC2.39, K4.7
unnamed: IC2.40, K4.6
unnamed: IC2.41, K4.5
unnamed: IC2.42, K4.4
unnamed: IC2.58, K4.16
unnamed: IC2.59, K4.19
unnamed: IC2.61, K4.12
unnamed: IC2.62, K4.11
unnamed: IC2.65, K3.7, R23.P$1
unnamed: IC2.66, K3.8, R18.P$1
unnamed: IC2.72, K5.SWDIO, TP1.1
unnamed: IC2.76, K5.SWCLK, TP2.1
unnamed: IC2.78, K3.1, R19.P$1
unnamed: IC2.79, K3.2, R20.P$1
unnamed: IC2.80, K3.5, R22.P$1
unnamed: IC2.81, K4.10
unnamed: IC2.82, K4.9
unnamed: IC2.83, K3.3, R21.P$1
unnamed: IC2.85, K4.14
unnamed: IC2.86, K4.15
unnamed: IC2.88, K4.17
unnamed: IC2.89, K5.SWO, TP8.1
unnamed: IC2.92, K6.2, R15.P$1
unnamed: IC2.93, K6.3, R16.P$1
unnamed: IC5.2, IC5.4, R14.P$2
unnamed: IC5.5, R9.P$2, R10.P$2, TP6.1
unnamed: IC5.7, R25.P$2, R26.P$1
unnamed: K6.4, R13.P$1
VBAT: C19.2, C24.P$2, C49.P$2, K6.1, L3.2, R12.P$1, R15.P$2, R16.P$2, TP16.1
VCC: C4.2, C14.1, C16.P$2, IC5.3, IC6.1, IC6.4, L1.1, R1.P$2, R8.1, TP5.1
VCC-2: C5.2, C6.P$2, C7.P$2, C8.P$2, C9.P$2, C10.P$2, C11.P$2, C17.2, C28.P$2, C29.P$2, C30.P$2, C31.P$2, C32.P$2, C33.P$2, C34.2, C35.2, C41.P$2, C42.P$2, C44.P$2, C45.2, C46.P$2, C51.2, C52.2, C53.2, C54.1, C55.P$1, C56.1, IC1.3, IC2.6, IC2.11, IC2.19, IC2.22, IC2.28, IC2.50, IC2.75, IC2.100, IC6.5, K5.VCC, L2.1, L4.2, R2.P$2, R17.P$1, T1.1, T2.1, TP3.1

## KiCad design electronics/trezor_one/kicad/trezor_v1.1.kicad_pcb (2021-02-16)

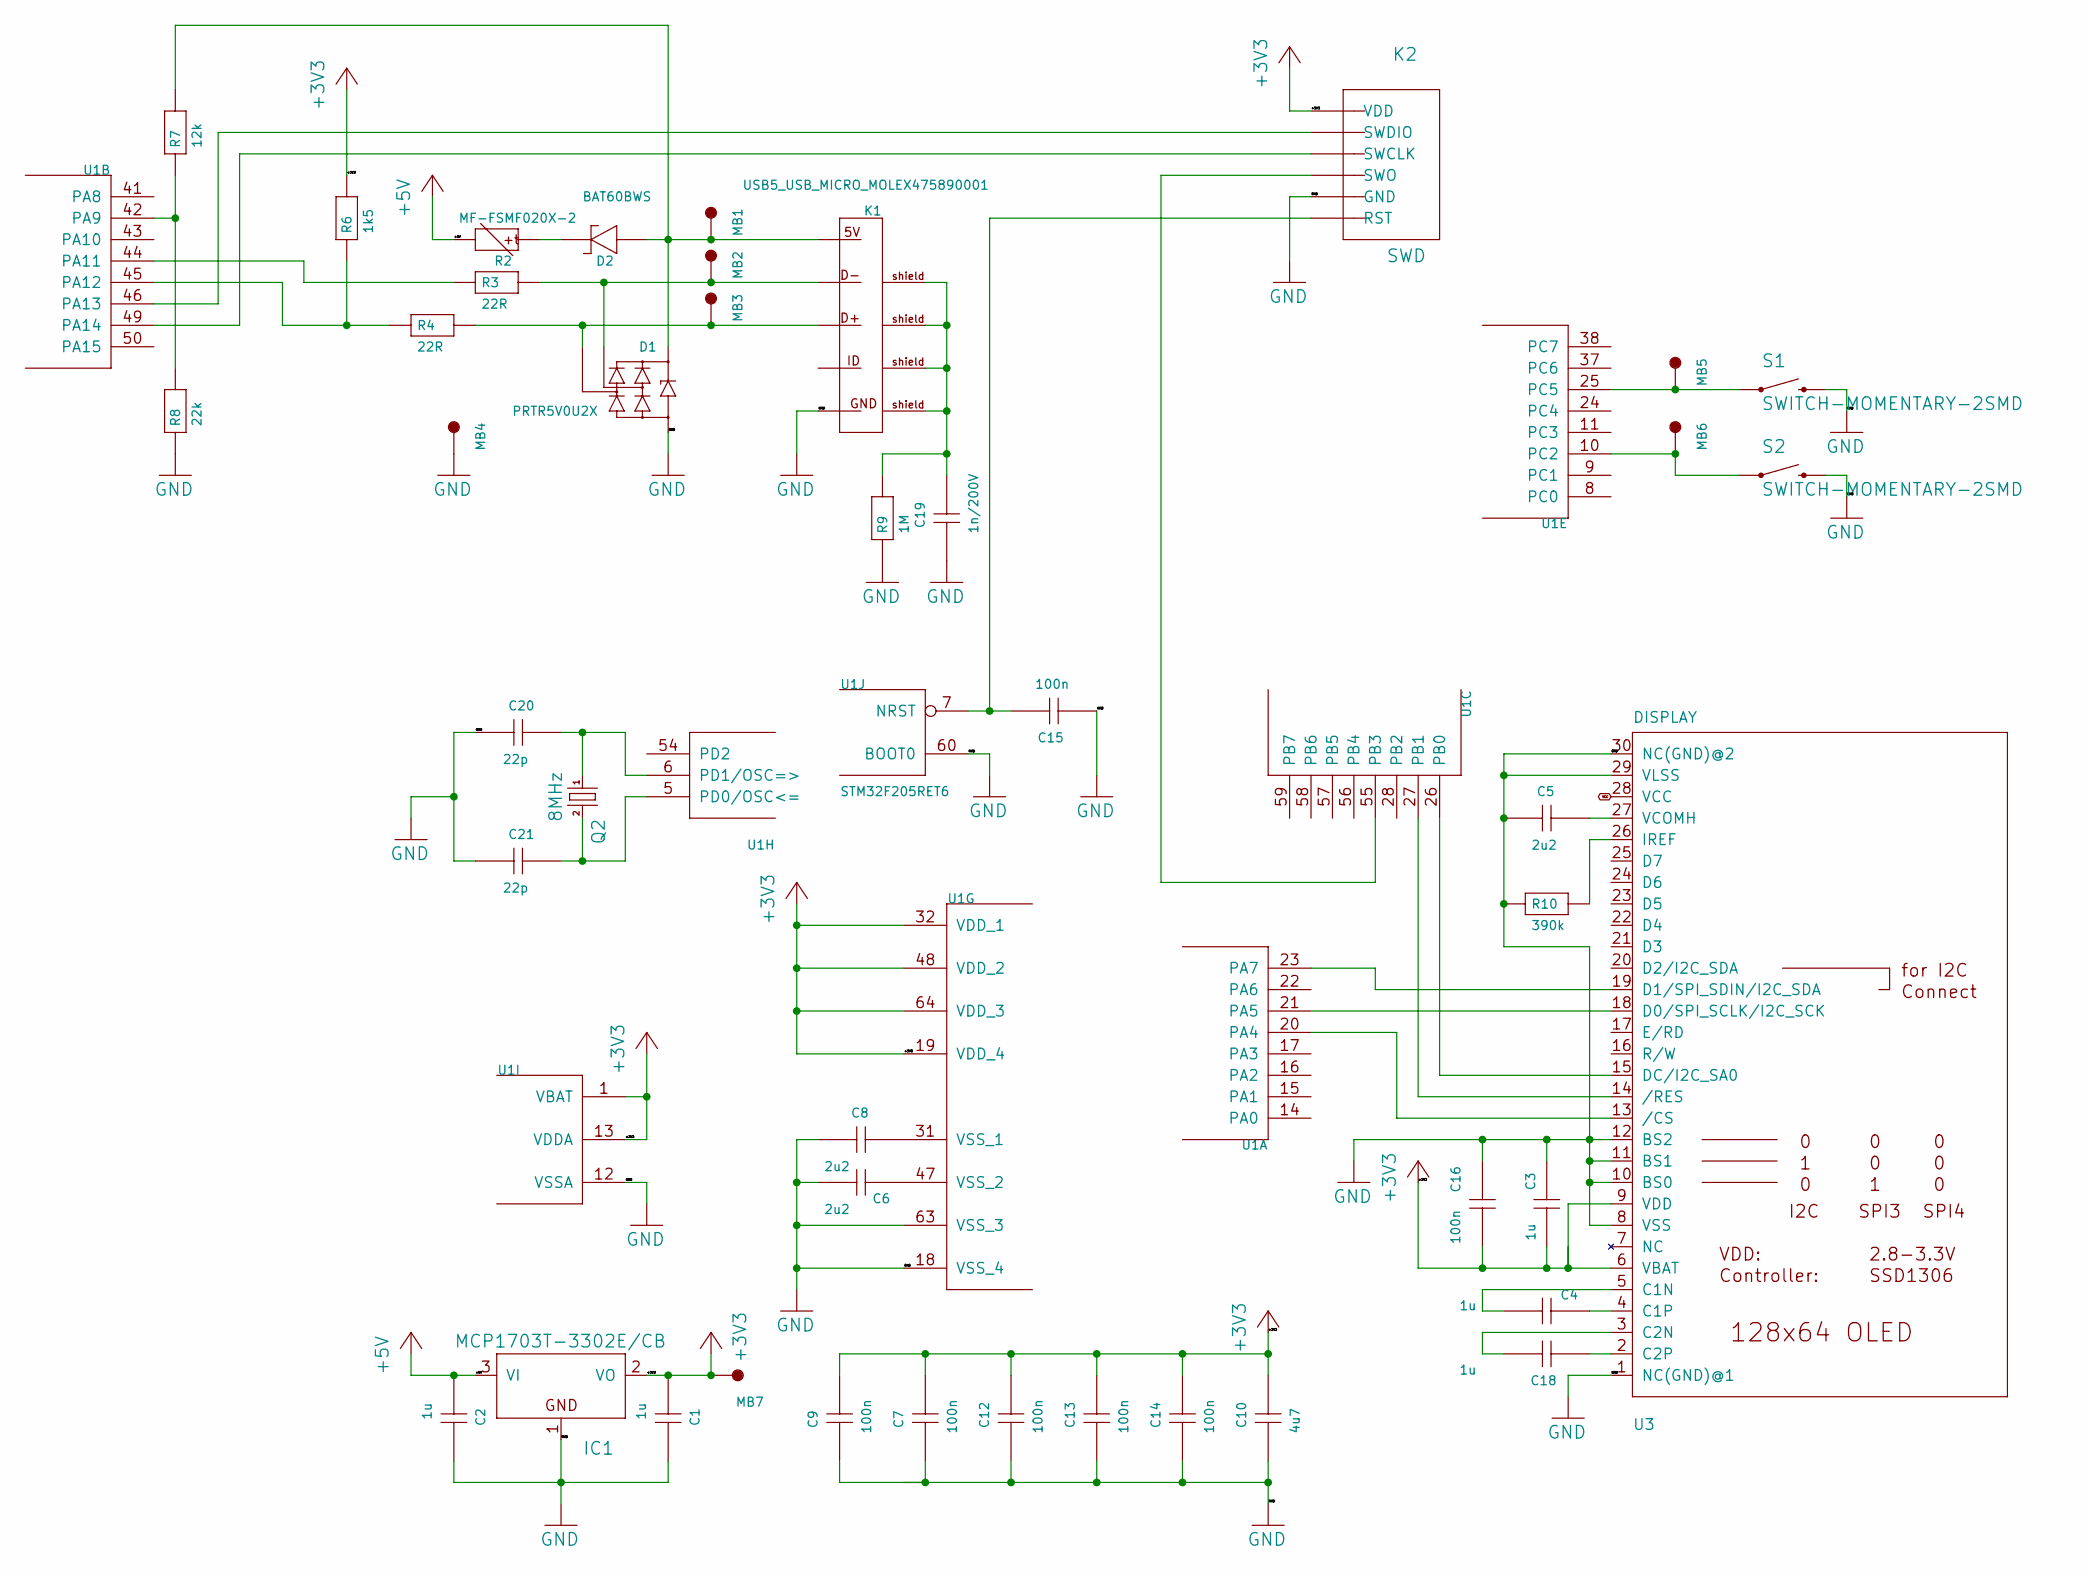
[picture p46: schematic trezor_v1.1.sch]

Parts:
C1, C2, C3, C4, C18: 1u; 0402
C5: 2u2; 0603
C6, C8: 2u2; 0402
C7, C9, C12, C13, C14, C15, C16: 100n; 0402
C10: 4u7; 0603
C19: 1n/200V; 0603
C20, C21: 22p; 0402
D1: PRTR5V0U2X; SOT143B
D2: BAT60BWS; SOD323
IC1: MCP1703T-3302E/CB; SOT23
K1: USB5_USB_MICRO_MOLEX475890001; USB_MICRO-MOLEX475890001
K2: SWD
MB1, MB2, MB3, MB4, MB5, MB6, MB7: MB_1.50; MB1.5
Q2: 8MHz; CTS406
R2: MF-FSMF020X-2; 0603
R3, R4: 22R; 0402
R6: 1k5; 0402
R7: 12k; 0402
R8: 22k; 0402
R9: 1M; 0603
R10: 390k; 0402
S1, S2: SWITCH-MOMENTARY-2SMD; TACTILE_SWITCH_SMD
U1: STM32F205RET6; TQFP64
U3: DISPLAY; UG-2864HSWEG01_0.96IN_WRAPAROUND

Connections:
+3V3: C1.P$1 (1), C3.P$1 (1), C7.P$2 (2), C9.P$2 (2), C10.2, C12.P$2 (2), C13.P$2 (2), C14.P$2 (2), C16.P$1 (1), IC1.2 (VO), K2.6 (VDD), MB7.1, R6.P$2 (2), U1.1 (VBAT), U1.13 (VDDA), U1.19 (VDD_4), U1.32 (VDD_1), U1.48 (VDD_2), U1.64 (VDD_3), U3.6 (VBAT), U3.9 (VDD)
+5V: C2.P$1 (1), IC1.3 (VI), R2.2
GND: C1.P$2 (2), C2.P$2 (2), C3.P$2 (2), C5.1, C6.P$1 (1), C7.P$1 (1), C8.P$1 (1), C9.P$1 (1), C10.1, C12.P$1 (1), C13.P$1 (1), C14.P$1 (1), C15.P$1 (1), C16.P$2 (2), C19.1, C20.P$1 (1), C21.P$1 (1), D1.1 (GND), IC1.1 (GND), K1.5 (5_GND), K2.2 (GND), MB4.1, R8.P$1 (1), R9.1, R10.P$1 (1), S1.3 (2), S1.4 (2), S2.3 (2), S2.4 (2), U1.12 (VSSA), U1.18 (VSS_4), U1.60 (BOOT0), U1.63 (VSS_3), U3.1 (NC(GND)@1), U3.8 (VSS), U3.10 (BS0), U3.11 (BS1), U3.12 (BS2), U3.29 (VLSS), U3.30 (NC(GND)@2)
unnamed: C4.P$1 (1), U3.4 (C1P)
unnamed: C4.P$2 (2), U3.5 (C1N)
unnamed: C5.2, U3.27 (VCOMH)
unnamed: C6.P$2 (2), U1.47 (VSS_2)
unnamed: C8.P$2 (2), U1.31 (VSS_1)
unnamed: C15.P$2 (2), K2.1 (RST), U1.7 (NRST)
unnamed: C18.P$1 (1), U3.2 (C2P)
unnamed: C18.P$2 (2), U3.3 (C2N)
unnamed: C19.2, K1.S1_BOT (SHIELD_1), K1.S1_TOP (SHIELD_1), K1.S2_BOT (SHIELD_2), K1.S2_TOP (SHIELD_2), K1.S3_BOT (SHIELD_3), K1.S3_TOP (SHIELD_3), K1.S4_BOT (SHIELD_4), K1.S4_TOP (SHIELD_4), K1.SA (SHIELD_1), K1.SB (SHIELD_2), R9.2
unnamed: C20.P$2 (2), Q2.1, U1.6 (PD1/OSC=>)
unnamed: C21.P$2 (2), Q2.3 (2), U1.5 (PD0/OSC<=)
unnamed: D1.2 (I/O1), K1.2 (2_D-), MB2.1, R3.P$2 (2)
unnamed: D1.3 (I/O2), K1.3 (3_D+), MB3.1, R4.P$2 (2)
unnamed: D1.4 (VCC), D2.A (1), K1.1 (1_5V), MB1.1, R7.P$2 (2)
unnamed: D2.K (2), R2.1
unnamed: K2.3 (SWO), U1.55 (PB3)
unnamed: K2.4 (SWCLK), U1.49 (PA14)
unnamed: K2.5 (SWDIO), U1.46 (PA13)
unnamed: MB5.1, S1.1, S1.2 (1), U1.25 (PC5)
unnamed: MB6.1, S2.1, S2.2 (1), U1.10 (PC2)
unnamed: R3.P$1 (1), U1.44 (PA11)
unnamed: R4.P$1 (1), R6.P$1 (1), U1.45 (PA12)
unnamed: R7.P$1 (1), R8.P$2 (2), U1.42 (PA9)
unnamed: R10.P$2 (2), U3.26 (IREF)
unnamed: U1.20 (PA4), U3.13 (/CS)
unnamed: U1.21 (PA5), U3.18 (D0/SPI_SCLK/I2C_SCK)
unnamed: U1.23 (PA7), U3.19 (D1/SPI_SDIN/I2C_SDA)
unnamed: U1.26 (PB0), U3.15 (DC/I2C_SA0)
unnamed: U1.27 (PB1), U3.14 (/RES)
VCC: U3.28 (VCC)

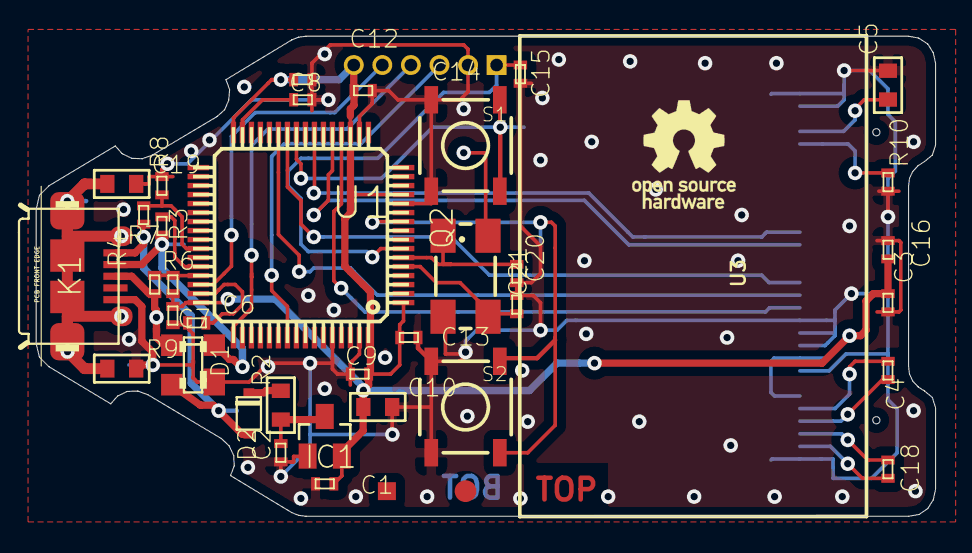
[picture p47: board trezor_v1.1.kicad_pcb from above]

Board: 16 copper layers, 50.0 x 26.7 mm, 46 parts (0 on the bottom side), 32 nets.

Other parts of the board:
U$3: BADMARK
U$4: CENTR

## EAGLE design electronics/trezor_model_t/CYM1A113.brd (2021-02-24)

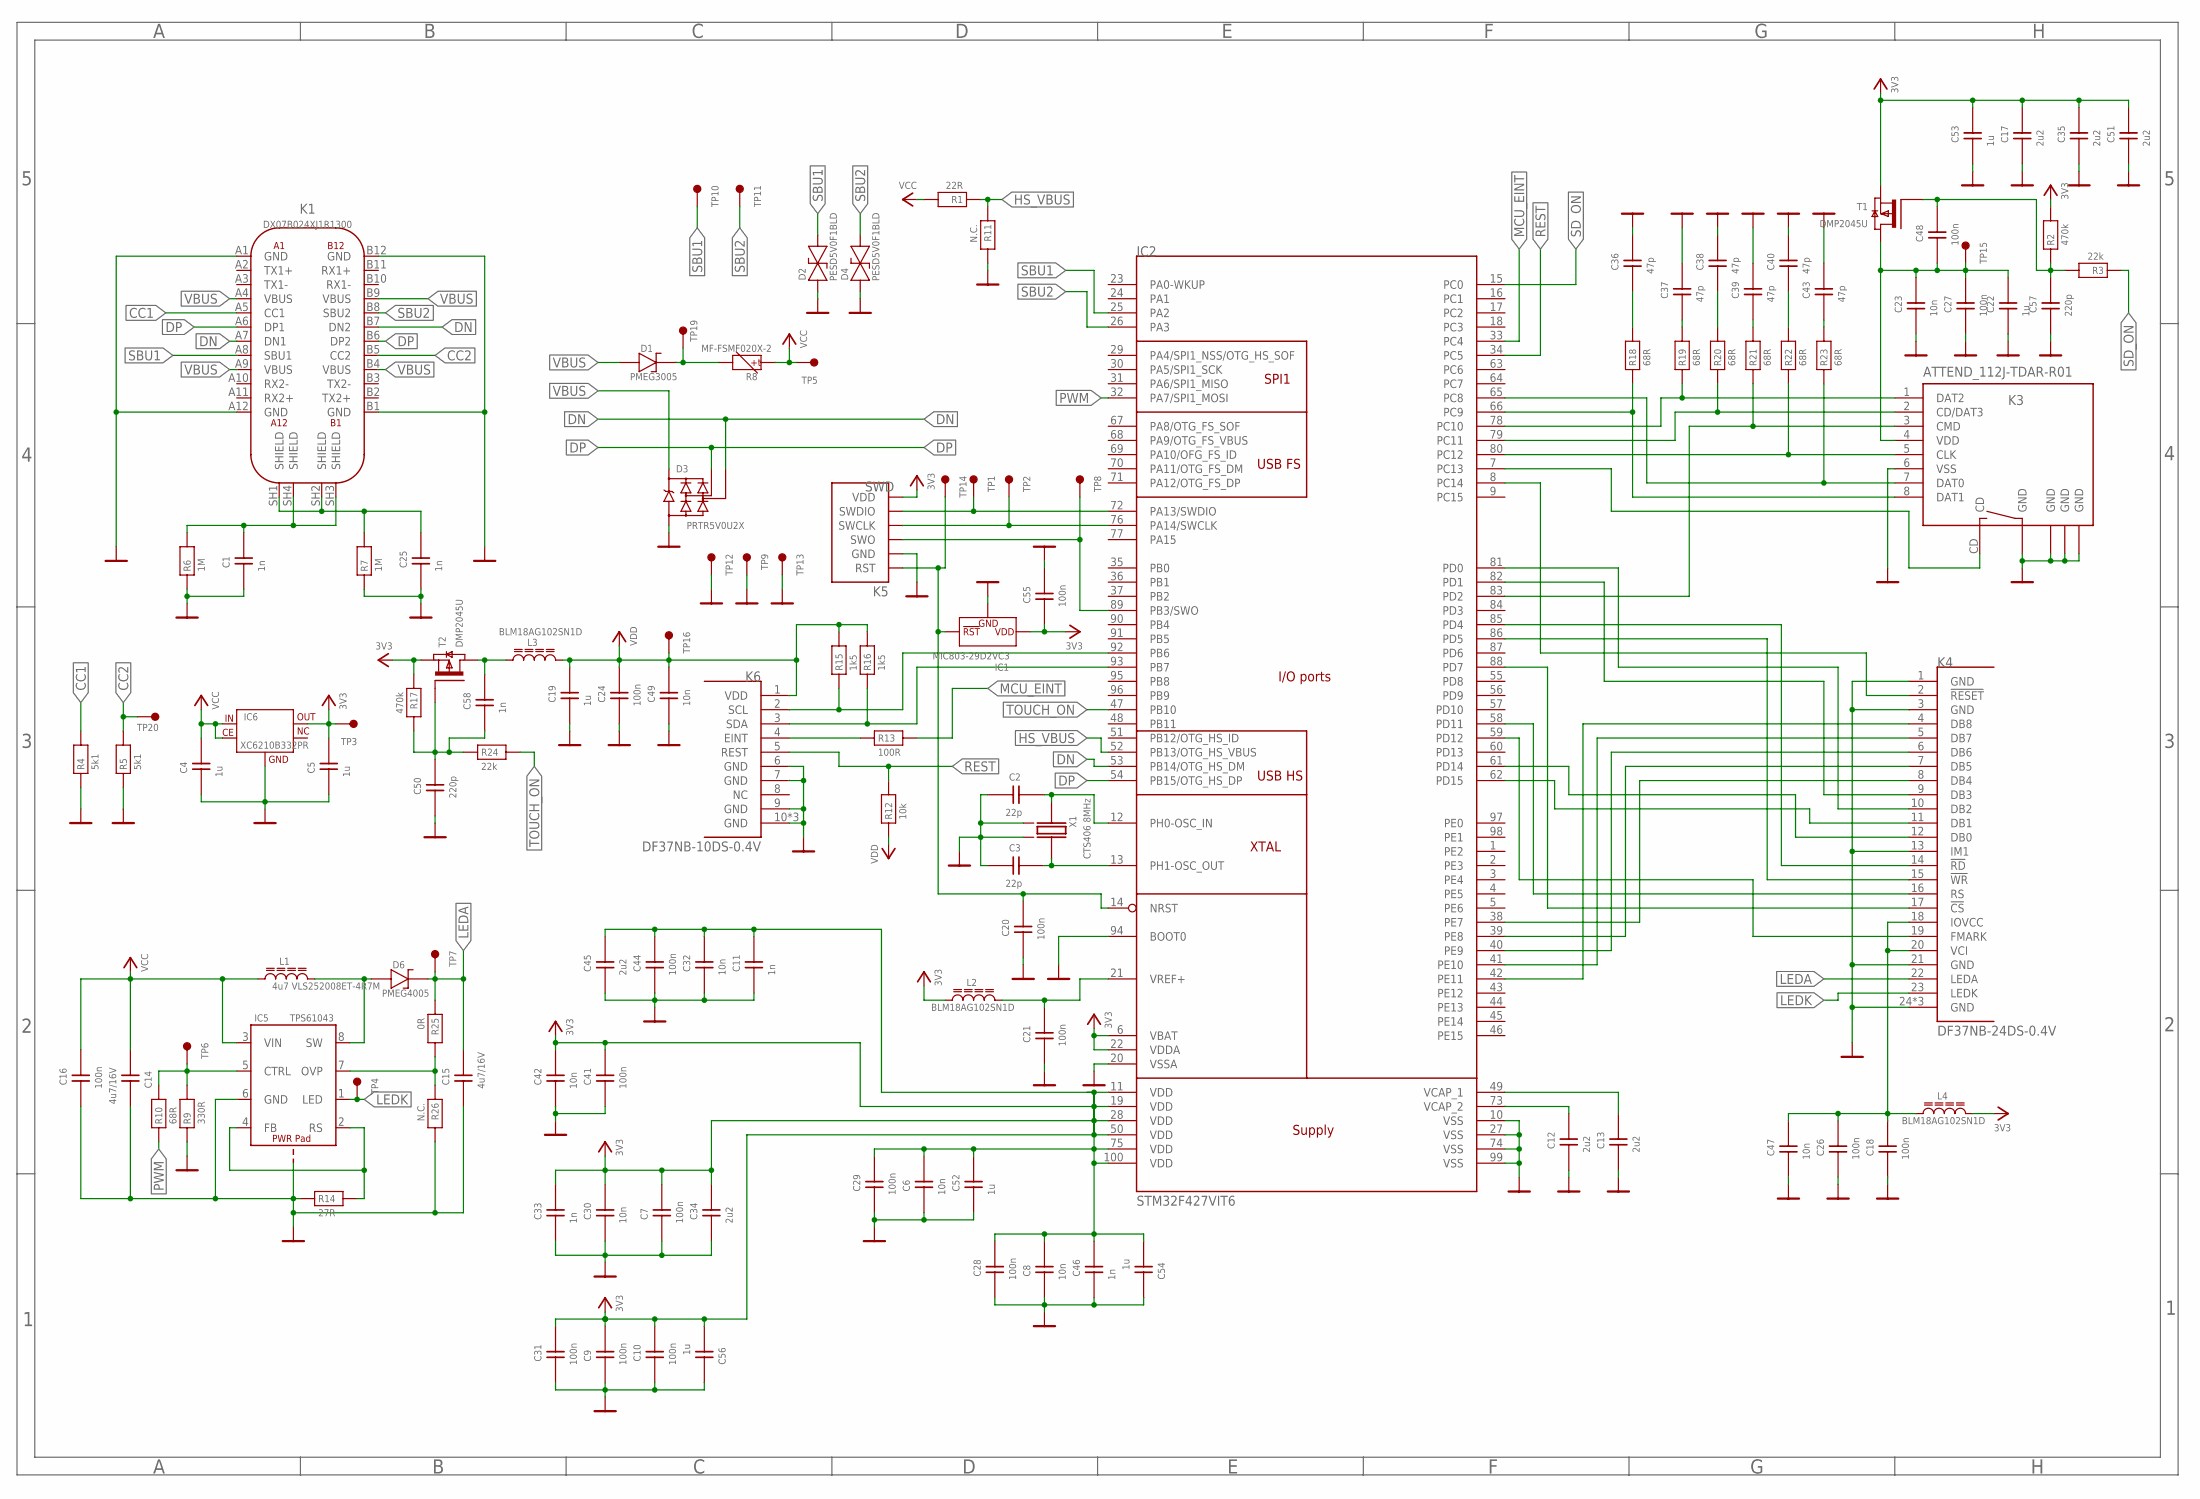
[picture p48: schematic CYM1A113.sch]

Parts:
C1, C11, C25, C33, C46, C58: 1n; 0402
C2, C3: 22p; 0402
C4, C19, C22, C52, C53, C54, C56: 1u; 0603_REFLOW
C5: 1u; 0603
C6, C8, C23, C30, C32, C42, C47, C49: 10n; 0402
C7, C9, C10, C16, C18, C20, C21, C24, C26, C27, C28, C29, C31, C41, C44, C48, C55: 100n; 0402
C12, C13, C17, C34, C35, C45, C51: 2u2; 0805_REFLOW
C14, C15: 4u7/16V; 0805_REFLOW
C36, C37, C38, C39, C40, C43: 47p; 0402
C50, C57: 220p; 0402
D1: PMEG3005; SOD323F
D2, D4: PESD5V0F1BLD; SOD882D
D3: PRTR5V0U2X; SOT143B_REFLOW
D6: PMEG4005; SOD323F
IC1: MIC803-29D2VC3; SOT23_MEDIUM_SIZE
IC2: STM32F427VIT6; LQFP100_NO_CENTER_NO_TDOCU
IC5: TPS61043; WSON-8_3X3MM
IC6: XC6210B332PR; SOT89-5
K1: DX07B024XJ1R1300; USB_C_JAE_DX07B024XJ1
K3: ATTEND_112J-TDAR-R01; ATTEND_112J-TXAR-R01_SMALL
K4: DF37NB-24DS-0.4V
K5: SWD
K6: DF37NB-10DS-0.4V
L1: 4u7 VLS252008ET-4R7M; L_2.5X2.0
L2, L3, L4: BLM18AG102SN1D; 0603_REFLOW
R1: 22R; 0402
R2, R17: 470k; 0402
R3, R24: 22k; 0402
R4, R5: 5k1; 0402
R6, R7: 1M; 0402
R8: MF-FSMF020X-2; 0603
R9: 330R; 0402
R10, R18, R19, R20, R21, R22, R23: 68R; 0402
R11, R26: N.C.; 0402
R12: 10k; 0402
R13: 100R; 0402
R14: 27R; 0402
R15, R16: 1k5; 0402
R25: 0R; 0402
T1, T2: DMP2045U; SOT23_REFLOW
TP1, TP2, TP4, TP6, TP7, TP8, TP9, TP12, TP13, TP14, TP15, TP16: MB_1.27; MB1.27
TP3, TP5, TP10, TP11: MB_1.50; MB1.5
TP19, TP20: MB_1.00
X1: CTS406 8MHz; X6,0X3,5

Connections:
CC1: K1.A5 (CC1), R4.P$2 (2)
CC2: K1.B5 (CC2), R5.P$2 (2), TP20.1
CTRL: IC5.5 (CTRL), R9.P$2 (2), R10.P$2 (2), TP6.1
DISP_!CS: IC2.88 (PD7), K4.17 (!CS)
DISP_!RD: IC2.85 (PD4), K4.14 (!RD)
DISP_!RESET: IC2.8 (PC14), K4.2 (!RESET)
DISP_!WR: IC2.86 (PD5), K4.15 (!WR)
DISP_DB0: IC2.61 (PD14), K4.12 (DB0)
DISP_DB1: IC2.62 (PD15), K4.11 (DB1)
DISP_DB2: IC2.81 (PD0), K4.10 (DB2)
DISP_DB3: IC2.82 (PD1), K4.9 (DB3)
DISP_DB4: IC2.38 (PE7), K4.8 (DB4)
DISP_DB5: IC2.39 (PE8), K4.7 (DB5)
DISP_DB6: IC2.40 (PE9), K4.6 (DB6)
DISP_DB7: IC2.41 (PE10), K4.5 (DB7)
DISP_DB8: IC2.42 (PE11), K4.4 (DB8)
DISP_FMARK: IC2.59 (PD12), K4.19 (FMARK)
DISP_RS: IC2.58 (PD11), K4.16 (RS)
DISP_VCC: C18.P$2 (2), C26.P$2 (2), C47.P$2 (2), K4.18 (IOVCC), K4.20 (VCI), L4.1
DN: D3.3 (I/O2), IC2.53 (PB14/OTG_HS_DM), K1.A7 (DN1), K1.B7 (DN2)
DP: D3.2 (I/O1), IC2.54 (PB15/OTG_HS_DP), K1.A6 (DP1), K1.B6 (DP2)
EINT: K6.4 (EINT), R13.P$1 (1)
FB_RS: IC5.2 (RS), IC5.4 (FB), R14.P$2 (2)
GND: C1.P$1 (1), C2.P$1 (1), C3.P$1 (1), C4.1, C5.1, C6.P$1 (1), C7.P$1 (1), C8.P$1 (1), C9.P$1 (1), C10.P$1 (1), C11.P$1 (1), C12.1, C13.1, C14.2, C15.1, C16.P$1 (1), C17.1, C18.P$1 (1), C19.1, C20.P$1 (1), C21.P$1 (1), C22.1, C23.P$1 (1), C24.P$1 (1), C25.P$1 (1), C26.P$1 (1), C27.P$1 (1), C28.P$1 (1), C29.P$1 (1), C30.P$1 (1), C31.P$1 (1), C32.P$1 (1), C33.P$1 (1), C34.1, C35.1, C36.P$2 (2), C37.P$2 (2), C38.P$2 (2), C39.P$2 (2), C40.P$2 (2), C41.P$1 (1), C42.P$1 (1), C43.P$2 (2), C44.P$1 (1), C45.1, C46.P$1 (1), C47.P$1 (1), C49.P$1 (1), C50.P$1 (1), C51.1, C52.1, C53.1, C54.2, C55.P$2 (2), C56.2, C57.P$1 (1), D2.1, D3.1 (GND), D4.1, IC1.1 (GND), IC2.10 (VSS), IC2.20 (VSSA), IC2.27 (VSS), IC2.74 (VSS), IC2.94 (BOOT0), IC2.99 (VSS), IC5.6 (GND), IC5.EP, IC5.EP$1 (EP), IC5.EP$2 (EP), IC5.EP$3 (EP), IC5.EP$4 (EP), IC6.2 (GND), K1.A1 (GND), K1.A12 (GND), K1.B1 (GND), K1.B12 (GND), K3.6 (VSS), K3.GND@1 (GND), K3.GND@2 (GND), K3.GND@3 (GND), K3.GND@4 (GND), K4.1 (GND), K4.3 (GND), K4.13 (IM1), K4.21 (GND), K4.24 (GND), K4.25 (GND), K4.26 (GND), K5.GND, K6.6 (GND), K6.7 (GND), K6.9 (GND), K6.10 (GND), K6.11 (GND), K6.12 (GND), R4.P$1 (1), R5.P$1 (1), R6.P$1 (1), R7.P$1 (1), R9.P$1 (1), R11.P$2 (2), R14.P$1 (1), R26.P$2 (2), TP9.1, TP12.1, TP13.1, X1.2 (GND1), X1.4 (GND2)
HS_VBUS: IC2.52 (PB13/OTG_HS_VBUS), R1.P$1 (1), R11.P$1 (1)
LEDA: C15.2, D6.K (2), K4.22 (LEDA), R25.P$1 (1), TP7.1
LEDK: IC5.1 (LED), K4.23 (LEDK), TP4.1
MCU_EINT: IC2.33 (PC4), R13.P$2 (2)
unnamed: C58.P$2 (2), L3.1, T2.3 (D)
unnamed: C1.P$2 (2), K1.SH3 (SHIELD), K1.SH4 (SHIELD), R6.P$2 (2)
unnamed: C25.P$2 (2), K1.SH1 (SHIELD), K1.SH2 (SHIELD), R7.P$2 (2)
unnamed: C36.P$1 (1), R18.P$2 (2)
unnamed: C37.P$1 (1), R19.P$2 (2)
unnamed: C38.P$1 (1), R20.P$2 (2)
unnamed: C39.P$1 (1), R21.P$2 (2)
unnamed: C40.P$1 (1), R22.P$2 (2)
unnamed: C43.P$1 (1), R23.P$2 (2)
unnamed: C22.2, C23.P$2 (2), C27.P$2 (2), C48.P$1 (1), K3.4 (VDD), T1.3 (D), TP15.1
unnamed: C2.P$2 (2), IC2.12 (PH0-OSC_IN), X1.1
unnamed: C3.P$2 (2), IC2.13 (PH1-OSC_OUT), X1.3 (2)
unnamed: C48.P$2 (2), C57.P$2 (2), R2.P$1 (1), R3.P$2 (2), T1.2 (G)
unnamed: D1.K (2), R8.2, TP19.1
unnamed: C12.2, IC2.73 (VCAP_2)
unnamed: C13.2, IC2.49 (VCAP_1)
unnamed: C50.P$2 (2), C58.P$1 (1), R17.P$2 (2), R24.P$1 (1), T2.2 (G)
OVP: IC5.7 (OVP), R25.P$2 (2), R26.P$1 (1)
PWM: IC2.32 (PA7/SPI1_MOSI), R10.P$1 (1)
REST: IC2.34 (PC5), K6.5 (REST), R12.P$2 (2)
RST: C20.P$2 (2), IC1.2 (RES), IC2.14 (NRST), K5.RST, TP14.1
SBU1: D2.2, IC2.25 (PA2), K1.A8 (SBU1), TP10.1
SBU2: D4.2, IC2.26 (PA3), K1.B8 (SBU2), TP11.1
SCL: IC2.92 (PB6), K6.2 (SCL), R15.P$1 (1)
SDA: IC2.93 (PB7), K6.3 (SDA), R16.P$1 (1)
SD_CD: IC2.7 (PC13), K3.CD
SD_CLK: IC2.80 (PC12), K3.5 (CLK), R22.P$1 (1)
SD_CMD: IC2.83 (PD2), K3.3 (CMD), R21.P$1 (1)
SD_DAT0: IC2.65 (PC8), K3.7 (DAT0), R23.P$1 (1)
SD_DAT1: IC2.66 (PC9), K3.8 (DAT1), R18.P$1 (1)
SD_DAT2: IC2.78 (PC10), K3.1 (DAT2), R19.P$1 (1)
SD_DAT3: IC2.79 (PC11), K3.2 (CD/DAT3), R20.P$1 (1)
SD_ON: IC2.15 (PC0), R3.P$1 (1)
SW: D6.A (1), IC5.8 (SW), L1.2
SWCLK: IC2.76 (PA14/SWCLK), K5.SWCLK, TP2.1
SWDIO: IC2.72 (PA13/SWDIO), K5.SWDIO, TP1.1
SWO: IC2.89 (PB3/SWO), K5.SWO, TP8.1
TOUCH_ON: IC2.47 (PB10), R24.P$2 (2)
VBUS: D1.A (1), D3.4 (VCC), K1.A4 (VBUS), K1.A9 (VBUS), K1.B4 (VBUS), K1.B9 (VBUS)
VCC: C4.2, C14.1, C16.P$2 (2), IC5.3 (VIN), IC6.1 (CE), IC6.4 (IN), L1.1, R1.P$2 (2), R8.1, TP5.1
VCC-2: C5.2, C6.P$2 (2), C7.P$2 (2), C8.P$2 (2), C9.P$2 (2), C10.P$2 (2), C11.P$2 (2), C17.2, C28.P$2 (2), C29.P$2 (2), C30.P$2 (2), C31.P$2 (2), C32.P$2 (2), C33.P$2 (2), C34.2, C35.2, C41.P$2 (2), C42.P$2 (2), C44.P$2 (2), C45.2, C46.P$2 (2), C51.2, C52.2, C53.2, C54.1, C55.P$1 (1), C56.1, IC1.3 (VDD), IC2.6 (VBAT), IC2.11 (VDD), IC2.19 (VDD), IC2.22 (VDDA), IC2.28 (VDD), IC2.50 (VDD), IC2.75 (VDD), IC2.100 (VDD), IC6.5 (OUT), K5.VCC (VDD), L2.1, L4.2, R2.P$2 (2), R17.P$1 (1), T1.1 (S), T2.1 (S), TP3.1
VDD: C19.2, C24.P$2 (2), C49.P$2 (2), K6.1 (VDD), L3.2, R12.P$1 (1), R15.P$2 (2), R16.P$2 (2), TP16.1
VREF+: C21.P$2 (2), IC2.21 (VREF+), L2.2

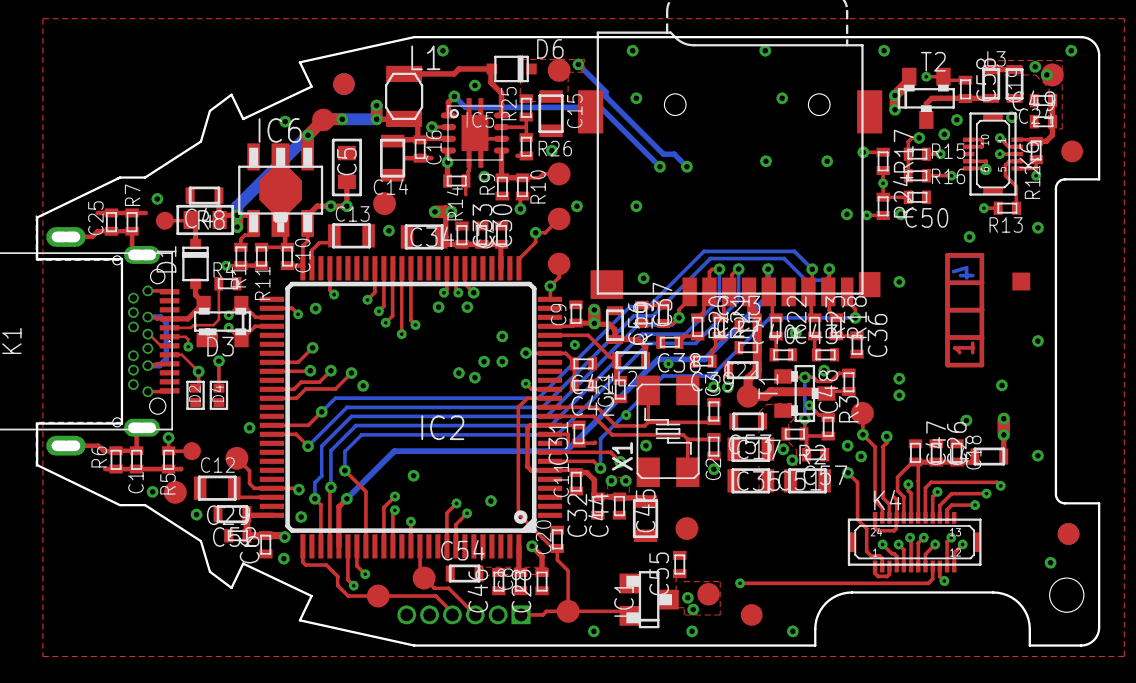
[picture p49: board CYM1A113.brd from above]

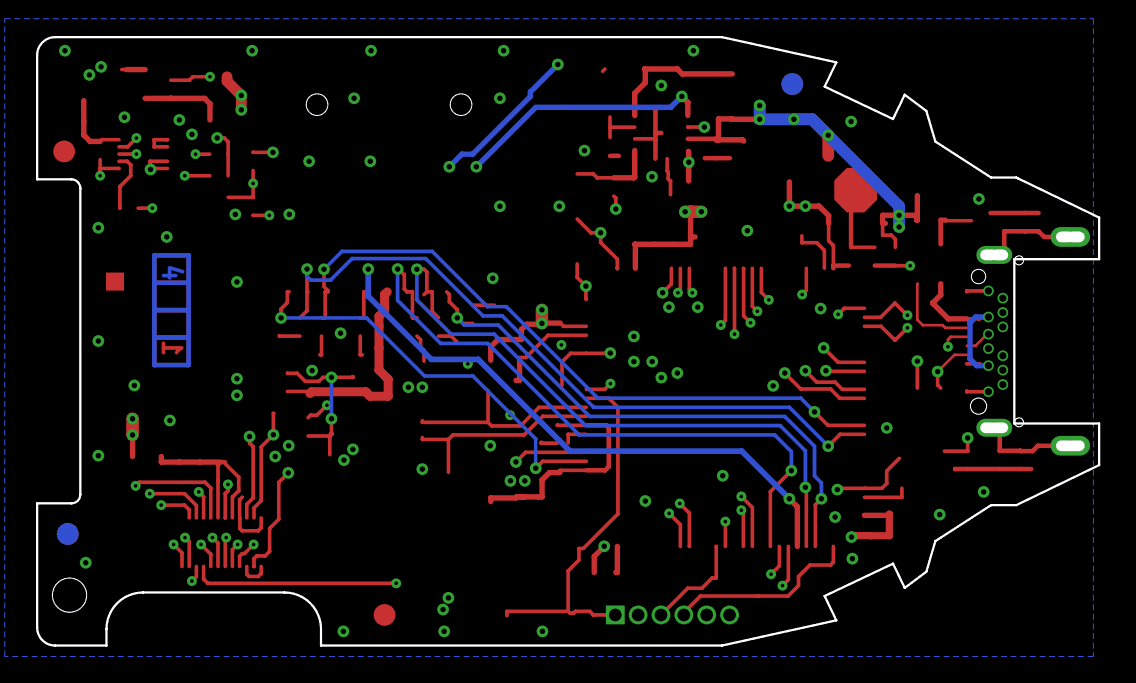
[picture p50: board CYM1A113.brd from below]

Board: 4 copper layers, 59.0 x 33.8 mm, 132 parts (2 on the bottom side), 71 nets.

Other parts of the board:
U$45, U$46, U$48, U$49, U$56, U$57: CENTR
U$47: BADMARK
U$53: RAM_BRD_ENG
U$54: LAYER_STACK_4_LAYERS

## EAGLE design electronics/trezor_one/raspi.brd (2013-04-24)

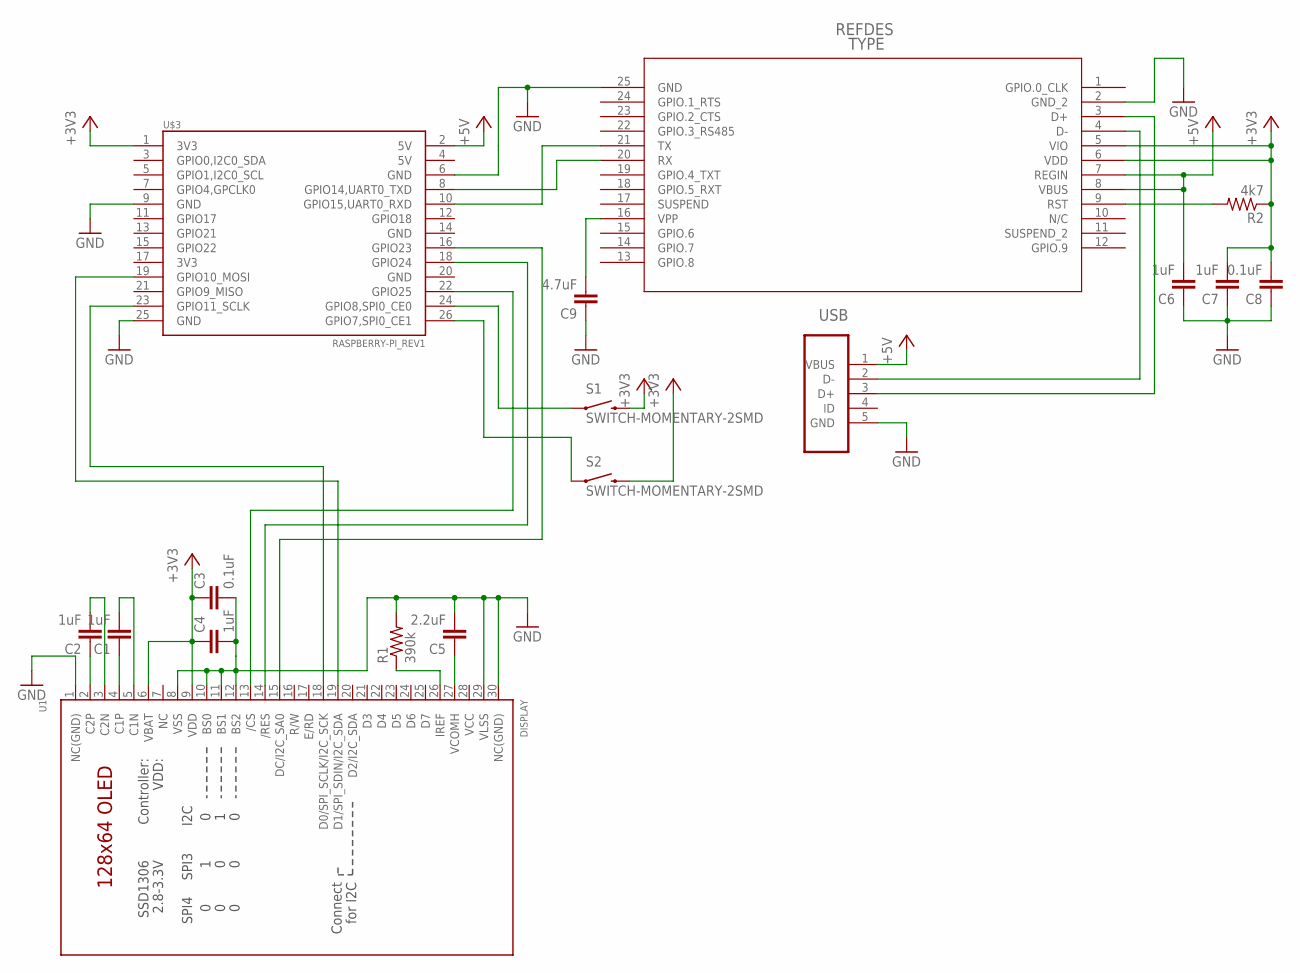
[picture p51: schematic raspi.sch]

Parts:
C1, C2, C4, C6, C7: 1uF; 0805
C3, C8: 0.1uF; 0805
C5: 2.2uF; 0805
C9: 4.7uF; 0805
R1: 390k; 0805
R2: 4k7; 0805
S1, S2: SWITCH-MOMENTARY-2SMD; TACTILE_SWITCH_SMD
U1: DISPLAY; UG-2864HSWEG01_0.96IN_WRAPAROUND
U2: CP2110-F01-GM
U$3: RASPBERRY-PI_REV1
USB: 47346-0001; MOLEX_47346-0001

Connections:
+3V3: C3.1, C4.1, C7.2, C8.2, R2.1, S1.3 (2), S2.3 (2), U1.6 (VBAT), U1.9 (VDD), U2.5 (VIO), U2.6 (VDD), U$3.1 (3V3)
+5V: C6.2, U2.7 (REGIN), U2.8 (VBUS), U$3.2 (5V), USB.1 (VBUS)
GND: C3.2, C4.2, C5.2, C6.1, C7.1, C8.1, C9.1, R1.2, U1.1 (NC(GND)), U1.8 (VSS), U1.10 (BS0), U1.11 (BS1), U1.12 (BS2), U1.29 (VLSS), U1.30 (NC(GND)), U2.2 (GND_2), U2.25 (GND), U$3.6 (GND), U$3.9 (GND), U$3.25 (GND), USB.5 (GND)
unnamed: U1.19 (D1/SPI_SDIN/I2C_SDA), U$3.19 (GPIO10_MOSI)
unnamed: S2.1, U$3.26 (GPIO7,SPI0_CE1)
unnamed: S1.1, U$3.24 (GPIO8,SPI0_CE0)
unnamed: U1.15 (DC/I2C_SA0), U$3.16 (GPIO23)
unnamed: U1.18 (D0/SPI_SCLK/I2C_SCK), U$3.23 (GPIO11_SCLK)
unnamed: C5.1, U1.27 (VCOMH)
unnamed: U1.13 (/CS), U$3.22 (GPIO25)
unnamed: U1.14 (/RES), U$3.18 (GPIO24)
unnamed: R1.1, U1.26 (IREF)
unnamed: C2.1, U1.2 (C2P)
unnamed: C1.1, U1.4 (C1P)
unnamed: C2.2, U1.3 (C2N)
unnamed: C1.2, U1.5 (C1N)
unnamed: C9.2, U2.16 (VPP)
unnamed: U2.21 (TX), U$3.10 (GPIO15,UART0_RXD)
unnamed: U2.20 (RX), U$3.8 (GPIO14,UART0_TXD)
unnamed: R2.2, U2.9 (RST)
USB_D_N: U2.4 (D-), USB.2 (D-)
USB_D_P: U2.3 (D+), USB.3 (D+)
VCC: U1.28 (VCC)

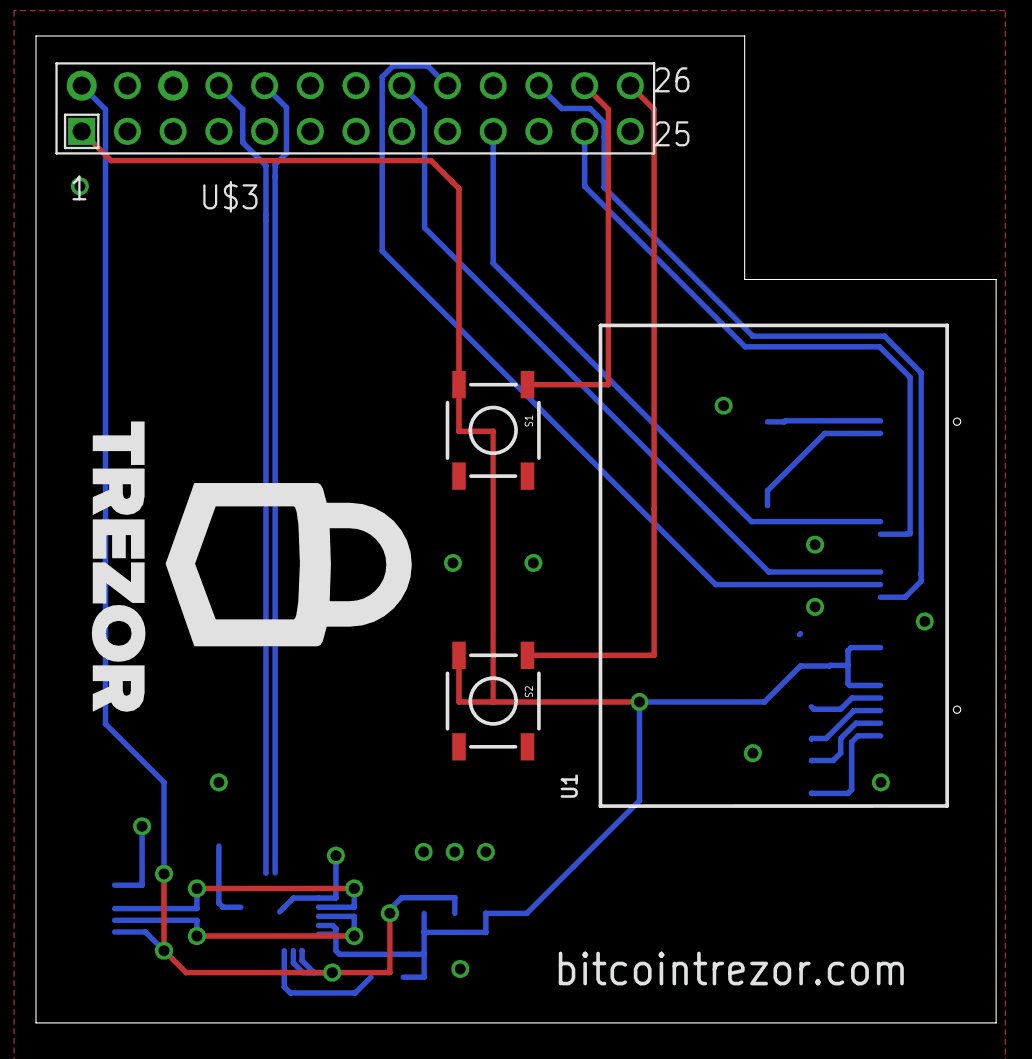
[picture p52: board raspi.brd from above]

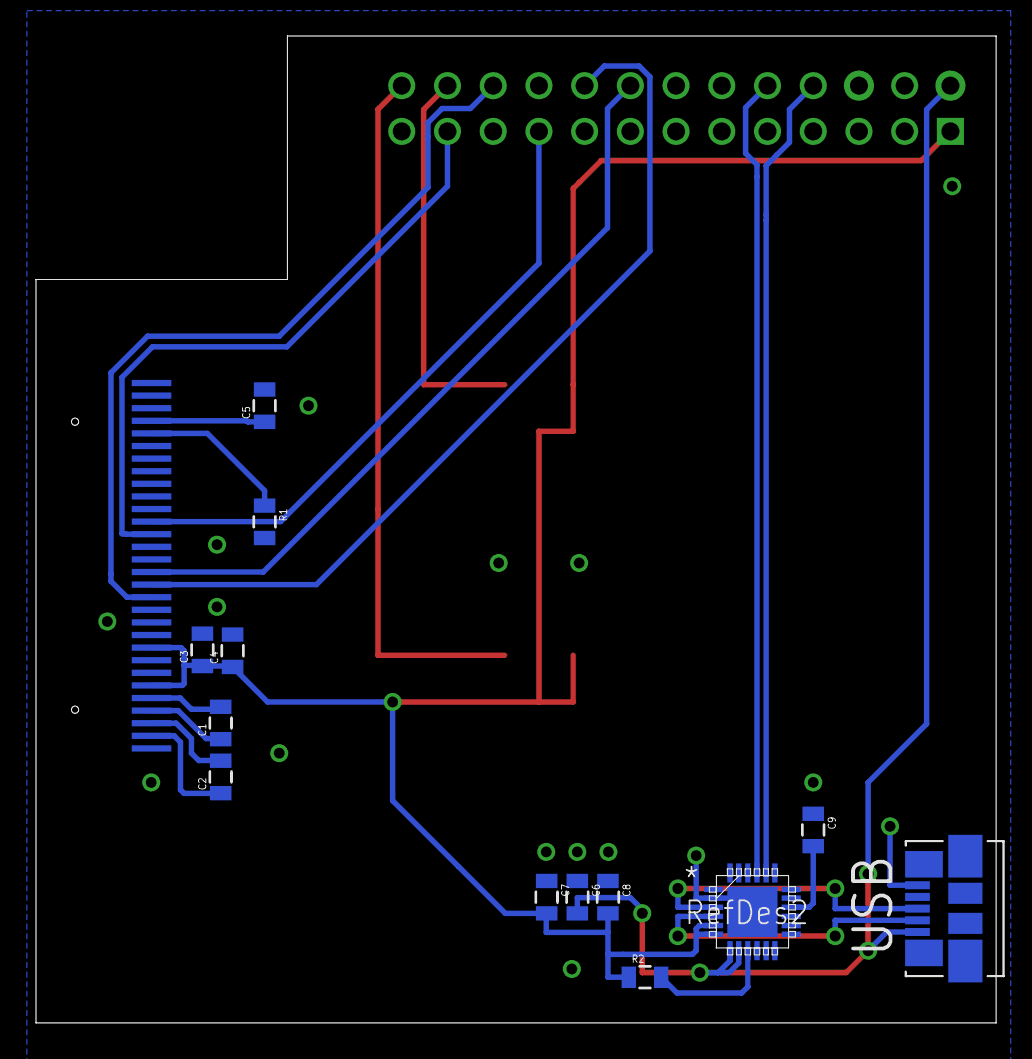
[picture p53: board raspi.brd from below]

Board: 2 copper layers, 53.3 x 54.8 mm, 17 parts (13 on the bottom side), 22 nets.

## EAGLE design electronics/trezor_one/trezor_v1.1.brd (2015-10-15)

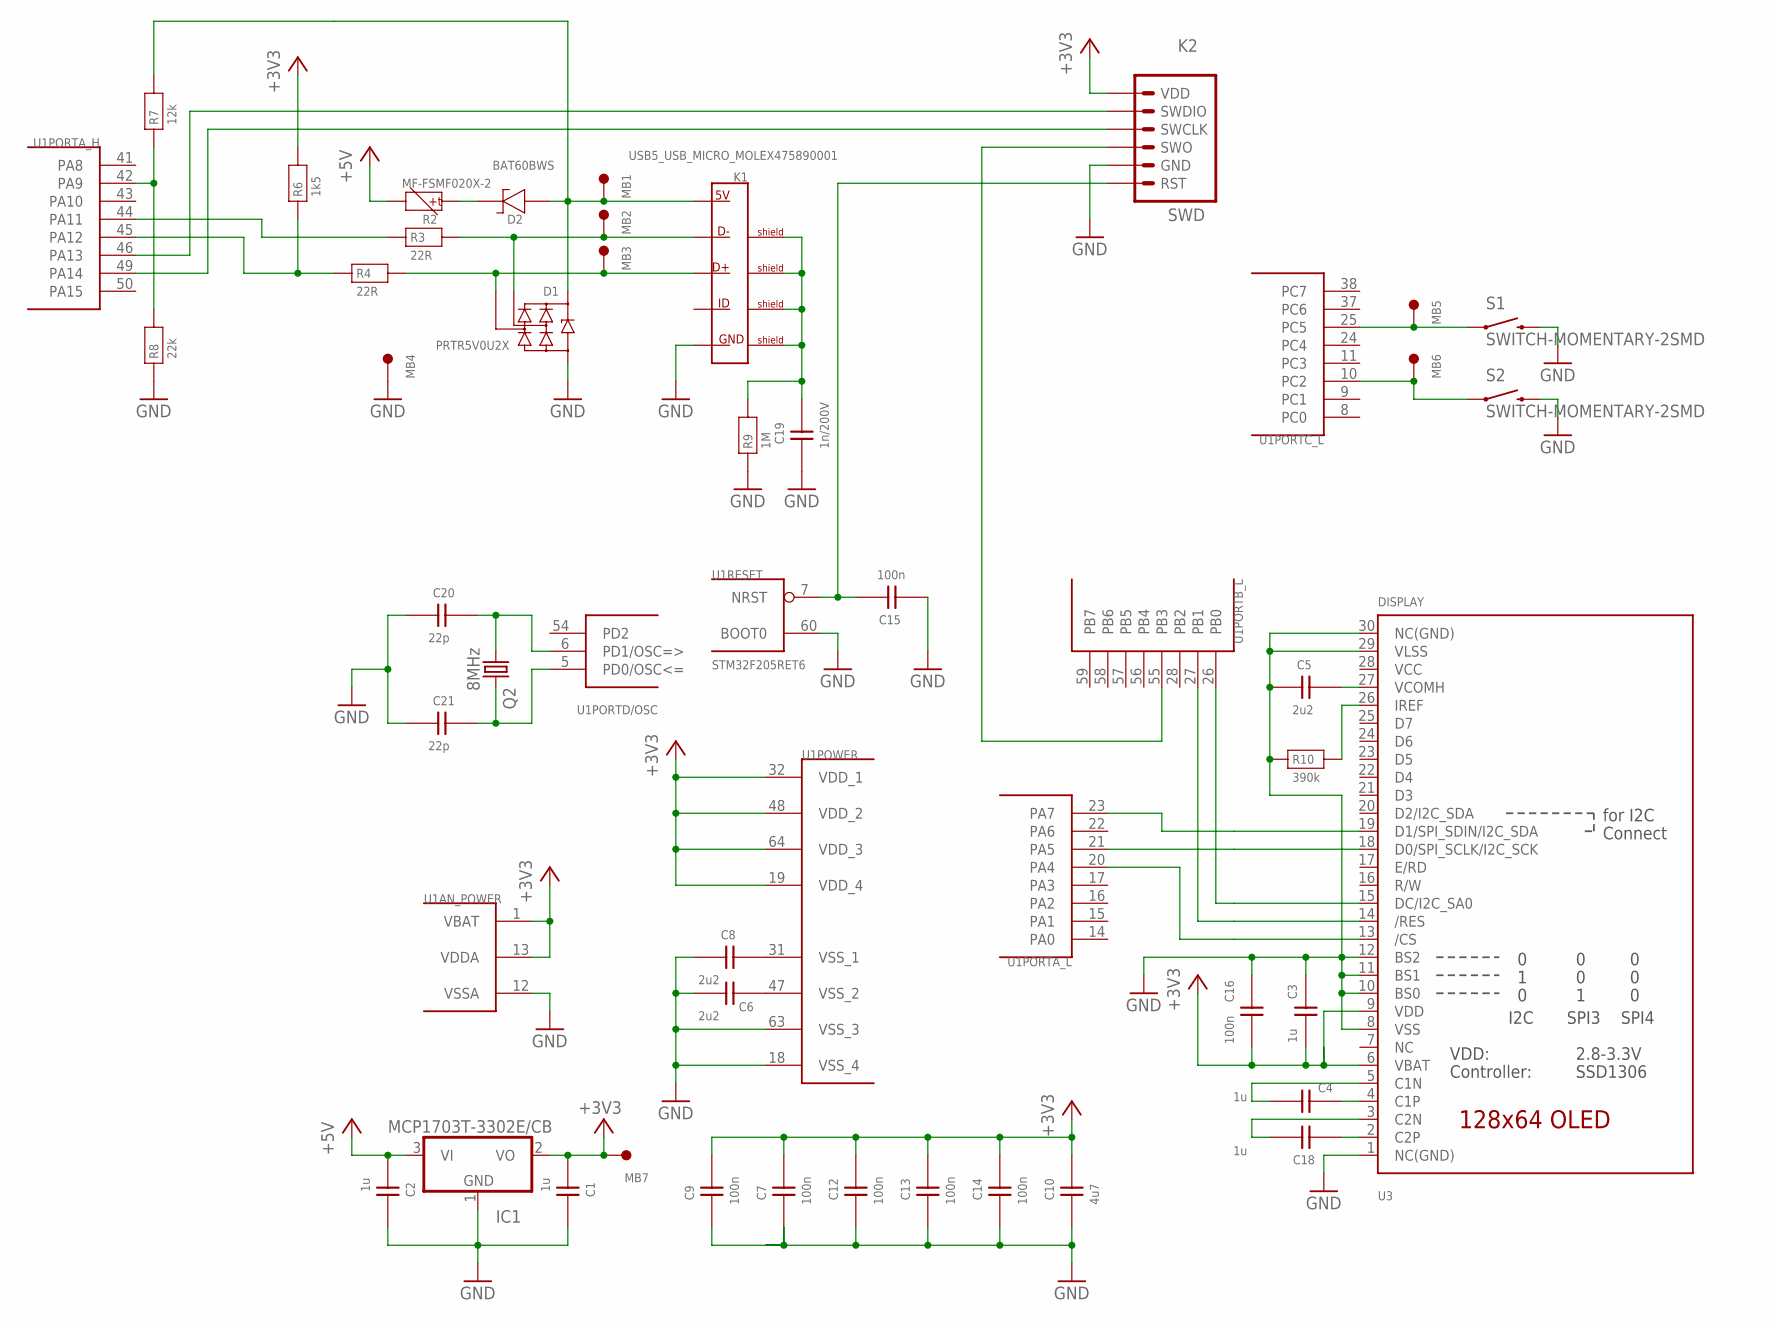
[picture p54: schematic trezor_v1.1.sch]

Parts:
C1, C2, C3, C4, C18: 1u; 0402
C5: 2u2; 0603
C6, C8: 2u2; 0402
C7, C9, C12, C13, C14, C15, C16: 100n; 0402
C10: 4u7; 0603
C19: 1n/200V; 0603
C20, C21: 22p; 0402
D1: PRTR5V0U2X; SOT143B
D2: BAT60BWS; SOD323
IC1: MCP1703T-3302E/CB; SOT23
K1: USB5_USB_MICRO_MOLEX475890001; USB_MICRO-MOLEX475890001
K2: SWD
MB1, MB2, MB3, MB4, MB5, MB6, MB7: MB_1.50; MB1.5
Q2: 8MHz; CTS406
R2: MF-FSMF020X-2; 0603
R3, R4: 22R; 0402
R6: 1k5; 0402
R7: 12k; 0402
R8: 22k; 0402
R9: 1M; 0603
R10: 390k; 0402
S1, S2: SWITCH-MOMENTARY-2SMD; TACTILE_SWITCH_SMD
U1: STM32F205RET6; TQFP64
U3: DISPLAY; UG-2864HSWEG01_0.96IN_WRAPAROUND

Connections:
+3V3: C1.P$1 (1), C3.P$1 (1), C7.P$2 (2), C9.P$2 (2), C10.2, C12.P$2 (2), C13.P$2 (2), C14.P$2 (2), C16.P$1 (1), IC1.2 (VO), K2.6 (VDD), MB7.1, R6.P$2 (2), U1.1 (VBAT), U1.13 (VDDA), U1.19 (VDD_4), U1.32 (VDD_1), U1.48 (VDD_2), U1.64 (VDD_3), U3.6 (VBAT), U3.9 (VDD)
+5V: C2.P$1 (1), IC1.3 (VI), R2.2
GND: C1.P$2 (2), C2.P$2 (2), C3.P$2 (2), C5.1, C6.P$1 (1), C7.P$1 (1), C8.P$1 (1), C9.P$1 (1), C10.1, C12.P$1 (1), C13.P$1 (1), C14.P$1 (1), C15.P$1 (1), C16.P$2 (2), C19.1, C20.P$1 (1), C21.P$1 (1), D1.1 (GND), IC1.1 (GND), K1.5 (5_GND), K2.2 (GND), MB4.1, R8.P$1 (1), R9.1, R10.P$1 (1), S1.3 (2), S1.4 (2), S2.3 (2), S2.4 (2), U1.12 (VSSA), U1.18 (VSS_4), U1.60 (BOOT0), U1.63 (VSS_3), U3.1 (NC(GND)), U3.8 (VSS), U3.10 (BS0), U3.11 (BS1), U3.12 (BS2), U3.29 (VLSS), U3.30 (NC(GND))
unnamed: U1.23 (PA7), U3.19 (D1/SPI_SDIN/I2C_SDA)
unnamed: C15.P$2 (2), K2.1 (RST), U1.7 (NRST)
unnamed: U1.26 (PB0), U3.15 (DC/I2C_SA0)
unnamed: C8.P$2 (2), U1.31 (VSS_1)
unnamed: U1.21 (PA5), U3.18 (D0/SPI_SCLK/I2C_SCK)
unnamed: C5.2, U3.27 (VCOMH)
unnamed: U1.27 (PB1), U3.14 (/RES)
unnamed: C6.P$2 (2), U1.47 (VSS_2)
unnamed: R10.P$2 (2), U3.26 (IREF)
unnamed: C18.P$1 (1), U3.2 (C2P)
unnamed: C4.P$1 (1), U3.4 (C1P)
unnamed: C18.P$2 (2), U3.3 (C2N)
unnamed: C4.P$2 (2), U3.5 (C1N)
unnamed: K2.3 (SWO), U1.55 (PB3)
unnamed: K2.5 (SWDIO), U1.46 (PA13)
unnamed: U1.20 (PA4), U3.13 (/CS)
unnamed: K2.4 (SWCLK), U1.49 (PA14)
unnamed: R3.P$1 (1), U1.44 (PA11)
unnamed: MB5.1, S1.1, S1.2 (1), U1.25 (PC5)
unnamed: MB6.1, S2.1, S2.2 (1), U1.10 (PC2)
unnamed: D1.4 (VCC), D2.A (1), K1.1 (1_5V), MB1.1, R7.P$2 (2)
unnamed: D2.K (2), R2.1
unnamed: D1.2 (I/O1), K1.2 (2_D-), MB2.1, R3.P$2 (2)
unnamed: D1.3 (I/O2), K1.3 (3_D+), MB3.1, R4.P$2 (2)
unnamed: C19.2, K1.S1_BOT (SHIELD_1), K1.S1_TOP (SHIELD_1), K1.S2_BOT (SHIELD_2), K1.S2_TOP (SHIELD_2), K1.S3_BOT (SHIELD_3), K1.S3_TOP (SHIELD_3), K1.S4_BOT (SHIELD_4), K1.S4_TOP (SHIELD_4), K1.SA (SHIELD_1), K1.SB (SHIELD_2), R9.2
unnamed: R7.P$1 (1), R8.P$2 (2), U1.42 (PA9)
USB_D_P: R4.P$1 (1), R6.P$1 (1), U1.45 (PA12)
VCC: U3.28 (VCC)
XTAL1: C20.P$2 (2), Q2.1, U1.6 (PD1/OSC=>)
XTAL2: C21.P$2 (2), Q2.3 (2), U1.5 (PD0/OSC<=)

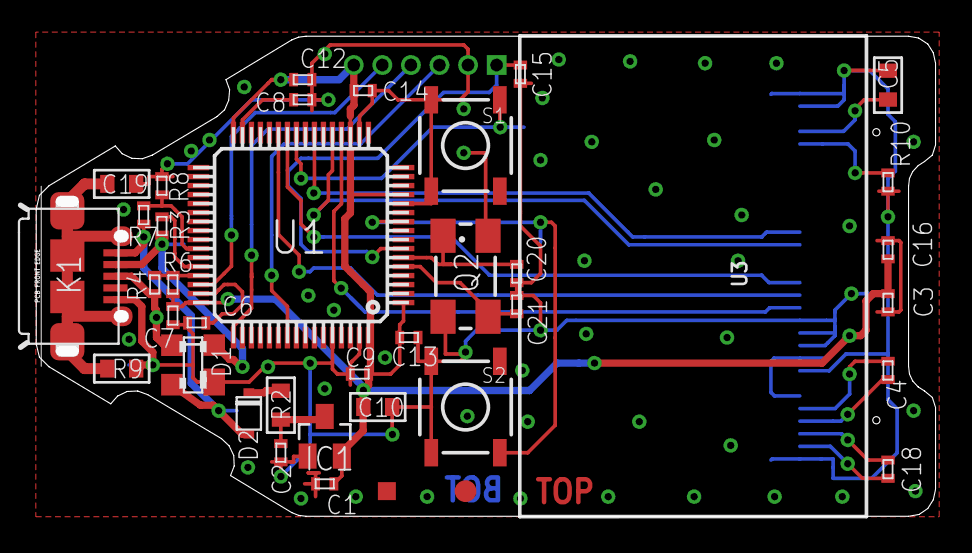
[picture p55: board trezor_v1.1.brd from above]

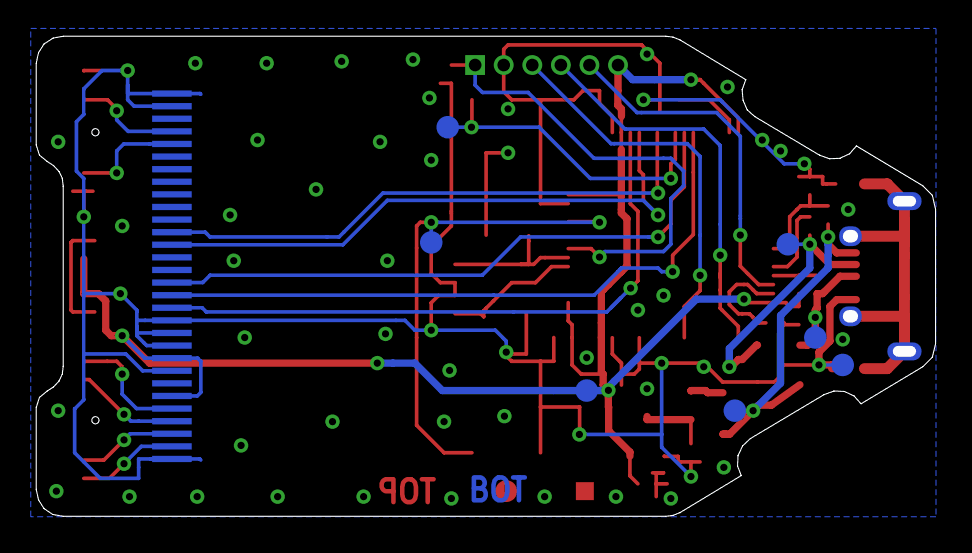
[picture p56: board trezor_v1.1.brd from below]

Board: 2 copper layers, 50.0 x 26.7 mm, 46 parts (7 on the bottom side), 32 nets.

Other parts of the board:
U$3: BADMARK
U$4: CENTR

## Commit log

2012-11-09 init code
    [launchpad.brd, launchpad.sch, raspi.brd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]
2012-11-09 fix distance for display
    [launchpad.brd, raspi.brd, raspi.sch]
2012-11-13 rework raspi board
    [raspi.brd, raspi.sch]
2012-11-13 add gnd polygons
    [launchpad.brd, raspi.brd]
2012-11-13 printing preparations
    [launchpad.brd, raspi.brd]
2012-11-29 add new stls
    [button.stl, case-down.stl, case-up.stl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]
2013-01-10 work on shield
    [raspi.brd, raspi.sch]
2013-01-14 work in progress
    [case-down.stl, case-up.stl, plosak-clear.dxf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]
2013-01-21 work on product scheme
    [product.brd, product.sch, raspi.brd]
2013-02-03 work on pcbs
    [plosak-clear.dxf, plosak-nobezier.dxf, plosak.dxf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]
2013-02-07 try freerouting
    [product.brd, product.dsn, product.sch]
2013-02-14 new pcb size :-/
    [button.stl, case-down.stl, case-up.stl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]
2013-02-21 raspi shield
    [raspi.brd, raspi.sch]
2013-02-21 work on product
    [product.brd]
2013-02-24 raspi work rename product to trezor
    [raspi.brd, trezor.brd, trezor.sch]
2013-02-25 work snapshot
    [raspi.brd, raspi.sch, trezor.brd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]
2013-02-25 forgot to connect usb gnd/vcc
    [trezor.brd, trezor.sch]
2013-03-09 work on raspi
    [raspi.brd]
2013-03-11 work on rpi
    [raspi.brd, raspi.sch]
2013-03-18 raspi work
    [raspi.brd, raspi.sch]
2013-03-24 rework BOMs
    [raspi.brd, raspi.sch]
2013-03-24 logo tDocu->tSilk
    [raspi.brd]
2013-04-01 rework to STM32 (WIP)
    [trezor.brd, trezor.sch]
2013-04-08 trezor WIP
    [trezor.brd, trezor.dsn, trezor.sch]
2013-04-08 revert dimension change
    [trezor.brd]
2013-04-08 remove unused files
    [atsha204-breakout.brd, atsha204-breakout.sch, launchpad.brd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]
2013-04-08 add url
    [trezor.brd]
2013-04-09 move capacitors to the edge
    [trezor.brd, trezor.dsn]
2013-04-12 add items to trezor bom
    [trezor.brd, trezor.sch]
2013-04-12 fix typo in trezor bom
2013-04-15 connect vbus to mcu as well
    [trezor.brd, trezor.sch]
2013-04-24 rework swd programmer
    [programmer-old.brd, programmer-old.sch, raspi.brd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]
2013-05-03 fix unconnected pin
    [trezor.brd]
2013-06-25 change crystal
    [trezor.brd, trezor.sch]
2013-07-23 repository cleanup
    [button-down.stl, button-up-1.stl, button-up-2.stl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]
2014-05-28 change capacitor
    [trezor_v1.brd, trezor_v1.sch]
2015-10-14 add board photo
    [programmer.brd, programmer.sch, raspi.brd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]
2015-10-15 cleanup eagle filenames (trezor -> trezor_v1.0, trezor_v1 -> trezor_v1.1)
    [trezor_v1.0.brd, trezor_v1.0.sch, trezor_v1.1.brd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]
2016-06-08 STL Models optimized for 3D Printing
    [buttons.stl, cover-down-3.stl, cover-up-3.stl]
2018-01-27 Added BOM for Trezor 1.1
    [trezor_v1.1_BOM.csv]
2020-02-01 Fix issues with 3d printed case (#9)
    - Fix mobility of buttons
    - Reinforce lanyard connection
    [buttons.stl, cover-down.stl, cover-up.stl]
2020-03-12 reorganize "case" folder structure
    [bottom.stl, button-down.stl, button-up-1.stl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]
2020-09-07 electronics: move Trezor One stuff to subfolder
    [programmer.brd, programmer.sch, raspi.brd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]
2020-09-07 electronics: add Trezor Model T resources
    [CYM1A113.brd, CYM1A113.sch]
2021-02-12 electronics: copy over relevant materials from trezor-firmware repo
2021-02-13 add kicad files
    [CYM1A113.kicad_pcb, CYM1A113.sch, trezor_v1.1.kicad_pcb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]
2021-02-16 Board edge rendering correction on kicad
    [CYM1A113.kicad_pcb]
2021-02-16 Fixed filled zones bug, connection issues
    [CYM1A113.kicad_pcb]
2021-02-16 set PCB width to 1.0 mm
    [CYM1A113.kicad_pcb]
2021-02-16 kicad import bug fixes
    fixed issues with the usb connector footprint causing kicad to be confused about the correct board edge shape
    [trezor_v1.1.kicad_pcb]
2021-02-16 add OSHW logo to Trezor One PCB
    [trezor_v1.1.kicad_pcb]
2021-02-16 add gitignore, remove extraneous kicad files
2021-02-24 update mosfet
    [CYM1A113.brd, CYM1A113.kicad_pcb, CYM1A113.sch]
2021-02-24 remove obsolete T1 board
    [trezor_v1.0.brd, trezor_v1.0.sch]
2023-02-07 update sd-card board link
2023-02-09 update model t bom

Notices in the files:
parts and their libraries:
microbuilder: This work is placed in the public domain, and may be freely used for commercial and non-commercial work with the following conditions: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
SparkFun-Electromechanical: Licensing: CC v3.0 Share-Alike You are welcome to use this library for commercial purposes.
